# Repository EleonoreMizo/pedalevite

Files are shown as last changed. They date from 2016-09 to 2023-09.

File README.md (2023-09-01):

### We have moved!

**This page is now dead, there will not be any update anymore.**

**The new page is hosted here: https://gitlab.com/EleonoreMizo/pedalevite/**  
**Git repository address: https://gitlab.com/EleonoreMizo/pedalevite.git**

Please update your bookmarks! Repository is kept here for consistency with other projects but probably not indefinitely.

Pédale Vite — Multi-FX pedalboard
=================================

**Pédale Vite** is a DIY multi-FX pedalboard for guitar, bass or any other electric instrument.

It is based on a Raspberry Pi 4 and uses a custom audio board.

Pédale Vite

Key features:

- A large collection of effects within a single box: distortion, chorus, flanger, delay, reverb…
- Programs containing any free combination of the above effects
- 12 footswitches to activate the programs or other functionalities
- Fast and smooth transition between programs
- Up to 3 expression pedals to drive effects like wha, volume, LFOs…
- Infinite modulation possibilities
- Free effect routing
- Designed for stage and regular transport
- Silent and accurate tuner activated with a footswitch
- Standalone, no need for any external computer
- Building is easy and simple, can be reproduced and adapted by any person without specific skill
- Free software and hardware design
- And much more…

More information [here](http://ldesoras.free.fr/doc/articles/pedale-vite/pedale-vite-en.html).

The [/doc/](/doc/) folder contains everything you need to build the pedalboard.

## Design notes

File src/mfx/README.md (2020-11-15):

# Multi-FX

This is the main Pédale Vite source code.

- **`adrv`**: various audio drivers coded for Pédale Vite and its Windows emulator
- **`cmd`**: the layer commanding the audio thread.
- **`doc`**: the internal document structure, with serialization facilities.
- **`dsp`**: a library containing all the digital signal processing parts.
- **`hw`**: platform-specific and hardware-related code.
- **`pi`**: a set of audio effects (and more) used in the pedalboard, designed as plug-ins.
- **`piapi`**: the plug-in API for the audio effects.
- **`ui`**: user interface basics. Mostly deals with hardware (display, switches…)
- **`uitk`**: User interface toolkit. Higher level (G)UI management.

The code uses (or tries to use) a Model-View-Controller (MVC) programming scheme. The **`Model`** and **`View`** classes are the main culprits here. The controller part is split into the various `ui::pg` classes. **`PageSet`** aggregates various GUI parts. **`WorldAudio`** handles most of the real-time audio tasks, and is asynchroniously controlled by `cmd::Central`.

The whole setup and event loops are currently located in `main.cpp` from the topmost source code directory.

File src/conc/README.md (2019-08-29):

# Conc

A library for lock-free inter-thread communications. It enables easy inter-tread communication and avoids locking critical threads with mutexes or other synchronisation objects.

Here are the main utility classes, from a user’s point of view:

- **`LockFreeCell`**: A template class to wrap a message object and use it in `LockFreeStack`, `LockFreeQueue` or `CellPool`.
- **`LockFreeStack`**: Lock-free stack (LIFO), completely thread-safe.
- **`LockFreeQueue`**: Lock-free queue (FIFO). Concurrent N to M threads access. It’s your main communication building block.
- **`CellPool`**: thread-safe storage for unused or recycled `LockFreeCell` objects.
- **`ObjPool`**: Like `CellPool`, but for any kind of object, providing additional control over creation.

These classes rely on atomic primitives (using Compare-And-Swap instructions). The **`Atomic*`** classes provide basic data storage, with `AtomicPtrIntPair` being the cornerstone of the previous data structures. **`AtomicIntOp`** is a helper wrapping a user-functor into a CAS loop to execute synchronized operations. There are some functor examples in the **`Aio*`** classes.

Some of these classes are probably less useful since the introduction of the `<atomic>` header in C++11, anyway the **`Interlocked`** class probably offers stronger lock-free guaranties, especially for 128-bit CAS required by `AtomicPtrIntPair` on 64-bit systems.

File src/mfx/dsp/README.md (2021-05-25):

# Digital Signal Processing library

## General organization

- **`ana`**: analysis and feature extraction tools, except envelope followers
- **`ctrl`**: control signal generators and processors (LFOs, envelopes, parameter smoothing…)
- **`dly`**: delay tools
- **`dyn`**: tools to analyse dynamics (envelope followers)
- **`fir`**: Finite Impulse Response filters
- **`grn`**: Granular resynthesis
- **`iir`**: Infinite Impulse Response filters, s-plane design tools
- **`mix`**: Basic copy/mix/volume tools
- **`nz`**: Noise generators
- **`osc`**: Oscillators
- **`rspl`**: Resampling tools
- **`shape`**: Waveshaper, look-up table functions and distortions
- **`spat`**: Spatialisation, environment
- **`spec`**: Spectral tools
- **`va`**: Virtual analogue circuit modelisations
- **`wnd`**: Windows and similar shapes

## Dependencies

The **`dsp`** lib depends on several other libraries:
- **`ffft`**: Fast Fourier Transforms
- **`fstb`**: Miscellaneous support functions and generic tools
- **`hiir`**: Half-band IIR filters and Hilbert transforms
- **`lal`**: Minimalist linear algebra library

## Unsorted classes

- **`BandSplitAllPassPair`**: A template agregator to split a signal into two bands, using the sum and difference of a complentary pair of all-pass filters

- **`DenormStop`**: Functions to prevent denormal numbers to appear and significantly slow down the processing.

- **`FilterCascade`**: A template to cascade up to 4 filters from different classes. They rely on a `float process_sample(float)` function.
- **`FilterBypass`**: A do-nothing filter
- **`FilterCascadeIdEven`**: A template to cascade several filters from the same class
- **`FilterCascadeIdOdd`**: Same as `FilterCascadeIdEven`, but with one more filter from another class

- **`SplDataRetrievalInterface`**: An interface to abstract the random access to potentially large sample data

- **`StereoLevel`**: a simple 2×2 matrix to handle 2-channel levels

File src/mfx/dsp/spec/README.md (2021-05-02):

## spec — spectral tools

- **`FrameOverlap*`**: classes for analysis and resynthesis of overlapping frames
- **`StftHelper`**: a wrapper around an FFTReal class to perform a windowed STFT analysis. Block processing is automatically stopped when a new frame is ready.

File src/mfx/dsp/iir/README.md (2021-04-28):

## dsp::iir — Infinite Impulse Response filters, s-plane design tools

- **`AllPass1p`**: single-pole all-pass filter
- **`AllPass1pChain`**: Chain of several single-pole all-pass filters
- **`AllPass2p`**: 2-pole all-pass filter
- **`AllPassCascade`**: Cascade of any number of 1-pole and 2-pole all-pass filter sections
- **`Biquad`**: Direct Form 2 biquad (2 poles and 2 zeros) implementation
- **`Biquad4`**: Processes 4 biquads in parallel. The interface is compatible with `Biquad4Simd`.
- **`Biquad4Simd`**: Processes 4 biquads simultaneously. They can be arranged in parallel, series or both. Serial arrangements can be with or without latency compensation.
- **`Biquad4SimdMorph`**: Same as above, with automatic coefficient ramping when they are changed.
- **`BiquadPackSimd`**: Processes N channels with M biquads, for an almost optimal usage of the SIMD instructions. The (N, M) configuration can be smoothly changed, as well as each filter coefficient. This is the core engine of any complex equalizer.
- **`DcKiller1p`**: single-pole DC removal.
- **`DcKiller2p`**: 2-pole DC removal.
- **`DesignElliptic`**: Elliptic low-pass filter design in the s-plane.
- **`DesignEq2p`**: s-plane design functions for basic filters (butterworth, equalizer…), including Orfanidis’ corrected filters at Nyquist frequency.
- **`Downsampler?xSimd`**, **`Upsampler?xSimd`**: Convenience wrappers on the HIIR functions to achieve fast and high-quality 4x-up and downsampling.
- **`FilterComb`**: Sub-sample comb filter with custom interpolator.
- **`Lpf1p`**: Simple smoothing low-pass filter with one pole and no zero
- **`OnePole`**: Direct Form 2 implementation of 1st order filter.
- **`OnePole4Simd`**: Processes 4 single-pole filters simultaneously. They can be arranged in parallel, series or both. Serial arrangements can be with or without latency compensation.
- **`SplitAp5`**: 5th-order crossover filter using complementary pairs of all-pass filters.
- **`SplitMultiband`**: Filterbank with equal-magnitude reconstruction using complementary pairs of all-pass filters (any order, variable number of bands).
- **`SplitMultibandBustard`**: Filterbank with equal-magnitude reconstruction using elementary LPF/HPF pairs like L-R or Thiele.
- **`SplitMultibandLin*`**: Filterbank with perfect phase-linear reconstruction using IIR filters.
- **`SplitMultibandSimdGen`**: Code generator for SIMD versions of `SplitMultiband` with a predefined number of bands.
- **`SplitThiele8`**: Linkwitz-Riley or Thiele 8th-order crossover filter.
- **`SqueezerSimd`**: 4-pole Moog low-pass filter emulation with optional, custom dirt. `SqueezerOpDefect` (radical shaping and polarity inversion) can be used for this purpose.
- **`Svf2p`**: class to design SVFs from basic parameters or s-plane equations
- **`SvfCore`**: Like `Biquad`, but using Andrew Simper’s Linear Trapezoidal State Variable Filters (SVFs) instead of biquads. Filter and mixer coefficients can be computed with `Svf2p`. Generic mixer can be optimised with **`SvfMixer*`** classes if only a fixed output is required.
- **`SvfCore4Simd`**: Processes 4 SVFs simultaneously. Works like `Biquad4Simd`.
- **`TransS`**: Transforms of s-plane equations and poles/zeros. 
- **`TransSZBilin`**: Functions turning s-plane equations (analogue prototypes) into z-plane coefficients to use them in the filter implementations. Also handles frequency prewarping.
- **`TransSZMatched`**: Vicanek’s transforms of s- to z-plane equations, trying to fix the frequency response near the Nyquist frequency.

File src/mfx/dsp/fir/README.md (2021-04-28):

## dsp::fir — Finite Impulse Response filters

- **`ConvolverFft`**: Helper class to perform a filtering convolution using an overlap-save-FFT technique.
- **`DesignPhaseMin`**: Turns a linear-phase filter into a minimum-phase filter.
- **`MovingSum`**: Computes the running sum of the last N samples. Does not drift and works in O(1).
- **`RankSelL`**: Selects the Nth-rank element (the median for example) from a running N-element list. Optimised to select a single, fixed rank per processed sample. Works in O(N)
- **`RankSelA`**: Same as above, but optimised to select one or more ranks very quickly. However new sample insertion is slower than `RankSelL`.
- **`Remez`**: Implementation of the Parks-McClellan algorithm to design a FIR filter.
- **`SlidingMax`**: Computes the running max of the last N samples. Works in O(1).
- **`SlidingOp`**: Performs an operation between the last N samples. Works in O(ln(N)). The operation is a functor.

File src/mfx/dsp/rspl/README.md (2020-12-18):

## rspl — resampling tools

- **`InterpFtor`**: simple functors for polynomial interpolation
- **`InterpFirMakerHermite4`**: Utility class for building a 3rd-order cubic hermite interpolator as a 4-tap FIR
- **`InterpFirMakerLagrange4`**: Utility class for building a 3rd-order lagrange interpolator as a 4-tap FIR
- **`InterpFirPolyphase`**: Interpolator using a FIR polyphase filter. Phase data are implemented with `InterpPhase*`, taken as template parameter.
- **`InterpolatorInterface`**: generic interpolator interface. Provides sample-per-sample and block processing, resampling rate linear ramping and multi-channel operations.
- **`InterpolatorFir`**: implements the `InterpolatorInterface` using a FIR for interpolation. The FIR convolver class (`InterpFirPolyphase` for example) should be provided as a template parameter.
- **`InterpolatorHermite43`**: implements the `InterpolatorInterface` using a 3rd-order cubic hermite interpolator
- **`InterpolatorHermite43Simd`**: same as `InterpolatorHermite43` with SIMD processing
- **`InterpolatorLerp`**: implements the `InterpolatorInterface` using a linear interpolator
- **`InterpolatorLerpSimd`**: same as `InterpolatorLerp` with SIMD processing
- **`InterpolatorOrder0`**: implements the `InterpolatorInterface` using a 0-th order interpolator (nearest neighbour)
- **`InterpPhase*`**: 
- **`SnhTool`**: This class is intended to improve resampling speed in presence of oversampled processing (rendering at a high sampling rate then downsampling to the target sampling rate). The idea is to generate less samples than required (in other words, at a lower rate) and to let the object hold the values to fill the blanks. Sample & Hold is preferred here over zero-filling because it greatly simplifies rate changes.
- **`Voice`**: class build around `InterpolatorInterface` and `SplDataRetrievalInterface`, handling the playback of a sampler voice with variable rate. Optional forward, backward or bidirectional looping.

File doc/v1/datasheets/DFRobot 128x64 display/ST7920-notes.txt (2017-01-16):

https://www.embeddedrelated.com/showthread/lpc2000/36610-1.php
http://forum.hobbycomponents.com/viewtopic.php?f=75&t=1395

Connectique :
1	VSS	GND
2	VDD	5 V
3	V0		Contrast (pot GND-VDD)
4	RS	x	Chip Select
5	R/W	x	Data
6	E	x	Clock
7	DB0
8	DB1
9	DB2
10	DB3
11	DB4
12	DB5
13	DB6
14	DB7
15	PSB	GND	Parallel/Serial
16	(NC)
17	RST	x	Reset
18	VOUT
19	BLA	5 V	Back light alim
20	BLK	GND	Back light (switch GND/NC) -> 0 = on

Some versions of this LCD are shipped with the PSB (parallel/serial select) pin shorted to VDD by a 0 ohm resistor fitted to R9 on the back of the LCD. This fixes the LCD in parallel mode. If this resistor is fitted and you wish to use the LCD in serial mode you will either need to move the resistor to R10 or completely remove it and ground the PSD pin.

What persuaded me to make the leap was when I found the solder jumpers that connect Vss and K, Vdd and A and PSB to Vss (or Vdd for parallel operation). Made sense that the Led accepted 5v if the jumpers are there. 

Hi I'm new to this site and just would like to point out that on the 12864ZW model R9 is actually a 27Kohm resistor and not a 0ohm jumper. To put it into serial mode you don't have to remove it like on the 12864B model, you can just connect pin PSB to ground and it will work in serial mode

Latest version I got just from mail (12864ZW written on back) doesn't seem to require any modifications, only solder jumper on small selector "S / P". Three point selector/solder pad thing. Working well currently with Raspberry Pi 3. MOSI + SCK (R/W & E) to GPIO, CS (RS) tied directly to VDD on board and seems to work well.

R10 is 0ohm, removing it backlight stops working, at least thru BLA/BLK pins.

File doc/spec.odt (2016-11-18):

# Document structure

## Table of content

## Revision history

Version | Date | Modifications
1.0 | 2015.09.07 | Creation

## References

Number | Title | Origin/Reference | Version/Date

## Glossary

# Fonctionnalités

Disposition générale :

- Pédales permanentes. Exemples :
  - banque N
  - banque suivante
  - banque précédente
  - preset { N, … }
  - preset suivant
  - preset précédent
  - Toggle accordeur (effet global)
  - Toggle effet { X, … }
  - Event trigger
- Zone de banque

Banque :

- Pédales permanentes
  - preset { N, … }
  - preset suivant
  - preset précédent
  - Toggle accordeur
  - Toggle effet { X, … }
  - Event trigger
- Zone de preset

Preset :

- Assignation expression → effet X paramètre N
- Pédales contextuelles
  - Effet X on/off
  - Event trigger
  - Paramètre binaire effet X paramètre N

Preset { N, … } : Sélection d’un preset donné ou cycle parmi une courte liste assignée à la pédale.

Toggle effet { X, … } : on peut adresser l’effet X par un nom, qui est global à la disposition générale (ou à la banque courante ? À voir.) Au sein d’un preset, on peut assigner un nom à un effet particulier, ce qui permet de relier une pédale à n’importe quel effet de n’importe quel patch. Il peut y avoir plusieurs effets assignés à la pédale, et dans ce cas l’état bypass de chaque effet est inversé.

On peut aussi simplement donner un type caractérisant l’effet à activer/désactiver. La pédale commande alors le premier effet de ce type trouvé dans la chaîne.

Event trigger peut avoir différents usages : repérage du tempo, enregistrement, lecture ou arrêt d’une boucle, réinitialisation de la phase des LFOs, envoi de données sur le MIDI, etc.

# Architecture

## Threading

Trois threads :

- Thread des entrées
- Thread de commande, qui gère la structure du document et toutes ses modifications.
  - Répond aussi vite que possible aux sollicitations utilisateur
  - Prépare les données pour le thread audio
  - Instancie, reconfigure et détruit les plug-ins.
- Thread audio, qui pourra éventuellement être multipliés pour profiter du multi-core.

## Gestion du document

Le modèle est partagé entre le thread de commande et le thread audio.

Toutes les actions passent par le thread de commande. Cependant, certains contrôleurs peuvent être envoyés directement au thread audio qui, en fonction de la configuration courante, peut mettre à jour instantanément sa copie personnelle des paramètres (hors modulation). C’est le cas par exemple de la fréquence de coupure de la wha.

Les paramètres modifiés par le thread audio sont routés sur le thread de commande qui redispatche à tout le monde sauf l’audio et éventuellement enregistre les changements (en fonction du mode d’édition). On peut alors considérer que thread audio prend temporairement et localement le rôle de contrôleur au sens MVC, se substituant complètement à sa fonction de vue.

Les deux threads disposent donc chacun d’une copie approximativement synchronisée des valeurs de tous les paramètres.

## Audio

Tout ce qui concerne le traitement audio est précalculé par le thread de commande, dans la mesure du possible. En particulier : l’enchaînement des traitements, la répartition des buffers, les applications instantanées de presets, etc.

## Messages

Messages thread de commande → thread audio :

- Nouveau bloc de contrôle
- Paramètre de plug-in

Messages thread audio → thread de commande :

- Recyclage d’un bloc de contrôle
- Paramètre de plug-in

## Contrôleurs

### LFO

Paramètres :

- Période/fréquence
- Distorsion de phase (répartition temporelle du point du milieu)
- Position de la distorsion de phase
- Aléa cyclique
- Forme d’onde
  - Sinus
  - Triangle
  - Demi-sinus
  - Carré
  - Dents de scie
  - N-Phase
  - Varislope
  - Bruit brun
- Signe
- Polarité (unipolaire / bipolaire)
- Distorsion d’onde n & m (1–64) : 1-(1-x^n)^m en valeur absolue. On pourrait le réduire à un seul paramètre ? n :1→1→64→64→(1), m :1→64→1→64→(1) en calculant bien la progression de n et m. https://www.desmos.com/calculator/u7s3hvwhcj. Ou mieux : avec p dans [0 ; 1], x forme d’onde en entrée, f(s)=3*s^2-2*s^3, r0(p) = limit(|1.25-2*p|-0.25, 0, 0.5), r1(p) = limit (1.25-|0.75-2*p|, 0.5, 1), h(x, p) = x*(r1(p)-r0(p))+r0(p), w(x, p) = (f•f•f)(h(x, p)), y(x, p) = (w(x, p) - w(0, p)) / (w(1, p) - w(0, p)) en faisant attention au cas linéaire quand p = 0. https://www.desmos.com/calculator/cps103twdg
- Sample & hold
- Smoothing

Traitement :

Soit : Phase tri → modulation chaotique → distorsion de phase → forme d’onde → signe → polarité

Soit : Générateur tout-en-un

Puis : → écrêtement → distorsion d’onde → sample & hold → smoothing

#### Intégration

C’est délicat, car on aimerait pouvoir piloter les paramètres des LFO avec les pédales, voir avec les autres LFO.

Une solution serait de concevoir les LFO comme des plug-ins. Leur valeur de sortie serait stockée comme premier sample du premier canal audio. Le plug-in publierait une propriété spécifique indiquant qu’il émet du signal de contrôle et non du son.

L’avantage de cette solution, c’est qu’on peut fabriquer sur le même modèle d’autres types de source de modulation : enveloppes ADSR, step sequencers, voire sondes.

L’inconvénient, c’est qu’il faut intégrer cela de manière fluide et logique, d’une part dans le modèle de document, et d’autre part dans l’interface utilisateur.

Ne générant pas d’audio, les LFO n’ont pas vraiment leur place dans les slots classiques : avoir un module dry/wet/gain n’a aucun sens. On pourrait faire à la place une liste de « sources de modulation pures » reprenant un peu le concept de slot, mais sans le dry/wet/gain. Cependant il est gênant d’avoir une telle liste parallèle qui ressemble de très près aux slots.

Ou alors on pourrait les mettre dans les slots et simplement ignorer le dry/wet/gain quand on les traite. Il faudrait cependant ajouter au preset des informations de graphe pour être sûr de traiter chaque plug-in correctement, quitte à ne faire qu’une chaîne et des plug-ins isolés. C’est probablement la méthode la plus viable à long terme.

Les côtés traitement et présentation sont nettement plus complexes. Il faudrait revoir le concept de la chaîne de traitement.

Réflexions à poursuivre…

O.K., on reprend. On peut commencer par identifier les slots par un identifiant unique plutôt que par une position dans la liste. Cette liste deviendrait alors un simple container (typiquement, une map) et perdrait son indication implicite de routing. Le routing serait contenu, lui, dans un objet séparé. Il y a déjà du travail à faire pour tout adapter.

Bon, voilà qui est fait. Alors maintenant, on va pouvoir faire des plug-ins générant des signaux de contrôle. Il suffit de les identifier avec un flag ou quelque chose comme ça. Par contre, comment identifie-t-on de manière simple les instances de ces plug-ins de façon à les présenter comme contrôleurs ? On peut par exemple dresser une liste dynamique de ces plug-ins identifiés par le nom de leur classe + le numéro de leur instance (probablement issu d’un classement par slot_id) + éventuellement nº de sortie. Ou alors label + sortie. Ça change un peu la conception de la page qui permet de sélectionner une modulation, mais ça devrait le faire. Non en fait ça va être compliqué. On va faire par exemple N ports fixes, que les plug-ins vont s’assigner plus ou moins automatiquement. Par contre ne seront présentés à l’utilisateur que les ports occupés.

# Interface d’utilisation

## Principes

L’interface se présente sous forme de pages. On passe d’une page à l’autre par une manipulation de des boutons ou par un événement externe (modification du document).

Le graphisme et la mise en page sont adaptables à des tailles d’écran diverses (au minimum 84 × 48), mais elles seront optimisées pour l’écran actuellement choisi, en 128 × 64.

Les boutons qui permettent d’interagir directement avec l’interface sont Select, Esc, les 4 flèches et les deux rotenc (rotary encoders) à bouton poussoir. Les directions des rotenc sont associés habituellement aux flèches, mais il est possible de les décoreler. De même, les deux boutons poussoir sont habituellement équivalents à Select.

## Liste des pages

### Démarrage

#### Éléments affichés

- Titre
- Version
- Éventuellement, scan des plug-ins
- Éventuellement, message d’interruption.

#### Interactions

Si la pédale 1 est maintenue enfoncée pendant cette phase, la phase se poursuit au moins jusqu’au relâchement de la pédale. Si la pédale reste enfoncée plus de deux secondes, le programme se termine.

### Informations — programme courant

#### Éléments affichés

- Numéro du programme en très gros
- Nom du programme en gros
- Numéro et nom de la banque courante en petit (qui peut être différente de la banque à laquelle appartient le programme courant ?)
- Adresse IP en petit

#### Interactions

- Select : ➡ menu principal
- ←, →, rotenc 2 : ➡ contrôle des niveaux ? Ça ou autre chose ?
- ↑, ↓, rotenc 1 : changement de programme

### Contrôle des niveaux

#### Éléments affichés

- Volume master en dB
- Vu-mètre sortie + clipping
- Volume d’entrée en dB
- Vu-mètre entrée + clipping
- Vu-mètre Charge CPU

#### Interactions

- ↑, ↓, rotenc 1 : Défilement dans le menu
- ←, →, rotenc 2 : changements
- Select sur un volume : Remettre à zéro l’information de clipping
- Select sur l’icône de canaux : changer la stéréo de sortie
- Esc : ➡ Informations — programme courant

### Menu principal

#### Éléments affichés

- Édition programme courant
- Édition des banques
- Configuration du pédalier
- Contrôle du volume maître
- Redémarrage

#### Interactions

- ↑, ↓, rotenc 1 : Défilement dans le menu
- Select : ➡ Édition programme courant, ➡ édition des banques, ➡ configuration du pédalier, ➡ contrôle du volume maître, ➡ redémarrage
- Esc : ➡ Informations — programme courant

### Redémarrage

#### Éléments affichés

- Voulez-vous vraiment redémarrer ?
- Non
- Oui

#### Interactions

- ↑, ↓, rotenc 1 : Défilement dans le menu
- Select : ➡ menu principal ou redémarrage de la machine
- Esc : ➡ menu principal

### Édition programme courant

#### Éléments affichés

- Nom du programme
- Contrôleurs
- Sauver dans…
- Liste des plug-in slots dans l’ordre de traitement + 1 vide

Note : à partir de cet écran, et dans tous les écrans hiérarchiquement contenus, on passe en mode « édition ». Dans ce mode, les changements opérés sur le programme acif sont automatiquement sauvegardés dans la banque.

#### Interactions

- ↑, ↓, rotenc 1 : Défilement dans le menu
- Esc : ➡ menu principal
- Select sur Nom du programme ➡ édition texte. Titre : « Nom du programme ».
- Select sur Contrôleurs : ➡ contrôleurs du programme
- Select sur un slot vide : ➡ menu slot
- Select sur un slot plein : ➡ liste des paramètres
- ←, →, rotenc 2 sur un slot plein : changement du type de l’effet, avec un slot vide en début de liste.

### Édition texte

#### Éléments affichés

- Titre
- Chaîne éditée + curseur
- Zone de sélection défilante contenant différents caractères + Del + ← + → + OK + Cancel
- Curseur dans la zone défilante

Exemple de contenu de caractères (pas exhaustif, pas final) :

+---------------------+

|Titre |

|Texte |

|OK CANCEL SPC DEL ← →|

|abcdefgABCDEFGáàâãäÁÀÂÃÄþ

|hijklmnHIKLMNJéèêëýÉÈÊËšÞ

|opqrstuOPQRSTUíìîïÝÍÌÎÏŠø

|vwxyzçÇVWXYZñÑóòôõöÓÒÔÕÖØ

|0123456789œŒæÆúùûüßÚÙÛÜžŽ

+-_'"«»,.:;!¡?¿*+·#%&|

=@/\()[]{}<>×÷¯¢$€£¥

#### Interactions

À l’arrivée, le curseur de chaîne est positionné sur la fin de la chaîne.

- ↑, ↓, rotenc 1 et ←, →, rotenc 2 : faire défiler le curseur de sélection
- Select : ajouter le caractère pointé ou faire l’action indiquée
- Esc : comme Cancel.

Icônes :

- OK : la chaîne est validée telle quelle, retour à l’écran commanditaire
- Cancel : l’édition est annulée, retour à l’écran commanditaire
- Del : le caractère avant le curseur est effacé
- ←, → : déplacement du curseur de chaîne.

### Contrôleurs du programme

#### Éléments affichés

- Sources de modulation

#### Interactions

- Select sur Type de l’effet : ➡ Sources de modulation
- Esc : ➡ édition programme courant

### Sources de modulation

#### Éléments affichés

- Liste des plug-ins non-audio sources de modulation + 1 vide. L’ordre donné est arbitraire.

#### Interactions

- Le fonctionnement est le même que pour la liste Édition programme courant. Le menu Slot correspondant est un peu différent (pas d’Insertion, de Déplacer ni de Canaux). La liste des paramètres n’intègre pas ceux de mix.
- Esc : ➡ Contrôleurs du programme

### Menu slot

#### Éléments affichés

- Type de l’effet
- Label
- Insérer nouveau avant
- Copier
- Coller
- Supprimer (si applicable)
- Remise à zéro (si applicable)
- Déplacer
- Presets (si applicable)
- Nbr chn in/out (si applicable)

#### Interactions

- ←, →, rotenc 2 sur Type de l’effet : cycle les effets disponibles + slot vide.
- Select sur Type de l’effet : ➡ liste des effets
- Select sur Supprimer : ➡ confirmation simple (titre : « supprimer le slot ? »), éventuelle suppression du slot puis retour ➡ édition programme courant.
- Select sur Remise à zéro : ➡ confirmation simple (titre : « Remettre l’effet à zéro ? »), éventuelle remise à zéro du slot puis retour sur cette même page.
- Select sur Déplacer : ➡ déplacement de slot
- Select sur Presets : ➡ gestion des presets d’effet
- Select sur Nbr chn in/out : alterne le mono forcé avec stéréo (si applicable)
- Select sur Label :
- Esc : ➡ édition programme courant

### Liste des paramètres

#### Éléments affichés

- Setup / actions
- Bypass + valeur
- FX mix + valeur
- Volume + valeur
- Liste des paramètres de l’effet + valeur

Les valeurs sont ici affichées sans unité, par souci de compacité.

Les paramètres modulés seront signalés d’une manière restant à déterminer (soulignement pointillé ?)

#### Interactions

- ↑, ↓, rotenc 1 : Défilement dans le menu
- Select sur Setup / actions : ➡ menu slot
- Select sur un paramètre : ➡ Édition d’un paramètre
- Esc : ➡ édition programme courant
- ←, →, rotenc 2 : changement de la valeur du paramètre (coarse, 1/20)

### Édition d’un paramètre

#### Éléments affichés

- Nom du paramètre
- Valeur
- Unité (sur la même ligne que la valeur)
- Symboles donnant 4 pas de réglage, sur une ligne (ex : « 1 :10 :100 :1000 »)
- Contrôleurs, avec symbole indiquant qu’il y en a
- Si applicable : indication asservissement au tempo

#### Interactions

Le nom et la valeur ne sont pas navigables.

### Contrôleurs d’un paramètre

#### Éléments affichés

- Automation
- Modulations (liste)

Chaque élément de la liste est constitué soit de <none> (pour l’automation) ou <empty> (denière modulation), soit du nom/numéro de la source de modulation, sans autre précision à ce niveau.

#### Interactions

- ↑, ↓, rotenc 1 : Défilement dans le menu
- Select sur une entrée : ➡ Édition d’un contrôleur
- Esc : ➡ Édition d’un paramètre

### Édition d’un contrôleur

#### Éléments affichés

- Source/action : <empty>, pedal, expression, rotenc… (on allongera la liste plus tard) + numéro ou nom de la source
- Le pas, si applicable (rotenc + paramètre à valeurs continues)
- Valeur min
- Pas de réglage de la valeur min, si applicable
- valeur max
- Pas de réglage de la valeur max, si applicable
- Nom de la courbe, si applicable
- Conversion unipolaire → bipolaire

Idéalement, si <empty> est actif, les autres champs apparaissent vides.

#### Interactions

Les valeurs min et max ne sont pas navigables.

- ↑, ↓, rotenc 1 : Défilement dans le menu
- ←, →, rotenc 2 sur la source : changement de la source, éventuellement ajout ou destruction du contrôleur.
- ←, →, rotenc 2 sur le pas : changement de la valeur du pas. On utilisera une échelle log.
- ←, →, rotenc 2 sur le pas des valeurs min/max : changement de ladite valeur en fonction du pas sélectionné.
- ←, →, rotenc 2 sur la courbe : changement de la courbe
- Select sur la courbe :➡ Choix d’une courbe
- ←, →, rotenc 2 ou Select sur la conversion unipolaire → bipolaire : toggle.
- Esc : ➡ Contrôleurs d’un paramètre.

### configuration du pédalier

Cet écran pourra servir autant à la configuration de base du pédalier qu’à celles associées aux programmes et aux banques.

#### Éléments affichés

12 entrées indiquant pour chaque pédale :

- Numéro de la pédale
- Fonction attribuée

La fonction peut être excessivement complexe. On choisira donc de ne présenter que des cas d’utilisation courants. Les cas y échappant seront indiqués comme « complexes » et ne pourront pas être édités.

Cas d’utilisation envisagés :

- Rien.
- Simple action : PRESS, action unique. En dehors des possibilités suivantes, l’action sera indiquée comme complexe :
  - Prog +
  - Prog -
  - Prog N
  - Bank +
  - Bank -
  - Bank N
  - Tuner
  - Tempo
  - Toggle type d’effet ou étiquette
  - Set nom du paramètre, type d’effet ou étiquette
- Bouton momentané : PRESS + RELEASE, action paramètre identique avec une valeur pour chaque changement d’état.
  - PBSet nom du paramètre, type d’effet ou étiquette
- Toggle : PRESS avec 2 cycles, paramètre identique à chaque fois avec une valeur pour chaque cycle.
  - Tgl nom du paramètre, type d’effet ou étiquette

Rappel, structure à montrer :

pédale → type de déclencheur → étapes de cycle → liste d’actions

Note : seule le déclencheur « PRESS » peut avoir plusieurs étapes de cycle. Les autres n’utilisent que la première étape, si elle existe.

#### Interactions

- ↑, ↓, rotenc 1 : Défilement dans le menu
- ←, →, rotenc 2 sur une pédale : défilement du type d’action :
  - Toutes les simples actions (programme 0 à 15, banque 0 à 63), avec Toggle FX et Set positionnées sur une étiquette vide et le paramètre 0.
  - Bouton momentané avec une étiquette vide et le paramètre 0, valeurs normalisées 0 et 1
  - Idem pour le Toggle Param.
- Select sur Toggle FX : ➡ Sélection d’un effet
- Select sur Set : ➡ Sélection d’un paramètre d’effet, 1 valeur
- Select sur Bouton momentané : ➡ Sélection d’un paramètre d’effet, 2 valeurs
- Select sur Toggle Param : ➡ Sélection d’un paramètre d’effet, 2 valeurs
- Esc : ➡ Menu principal

### Sélection d’un paramètre d’effet, 1 valeur

#### Éléments affichés

- « Effect » ou « Label »
- Nom de l’effet ou du label
- Nom du paramètre
- Valeur
- Unité (sur la même ligne que la valeur)
- Symboles donnant 4 pas de réglage, sur une ligne (ex : « 1 :10 :100 :1000 »)

#### Interactions

### Sélection d’un paramètre d’effet, 2 valeurs

#### Éléments affichés

#### Interactions

### Édition des banques

#### Éléments affichés

- Import bank
- Export bank
- Liste des banques : coche + numéro + nom

La coche indique la banque courante.

#### Interactions

- Select sur Import : ➡ import de banque
- Select sur Export : ➡ export de banque
- Select sur une banque : sélection de la banque et ➡ édition d’une banque
- Esc : ➡ Menu principal

### x

#### Éléments affichés

#### Interactions

### x

#### Éléments affichés

#### Interactions

### x

#### Éléments affichés

#### Interactions

### x

#### Éléments affichés

#### Interactions

### x

#### Éléments affichés

#### Interactions

# Implémentation

## Interface utilisateur

### Principes

Chaque page est un container d’éléments, sous forme de simple liste.

La notion de curseur (matérialisé en vidéo inversée) est centrale. Celui-ci passe d’un élément à l’autre, en sautant les éléments qui n’acceptent pas de curseur.

Le curseur réagit à ↑, ↓ et rotenc 1. Par défaut, il passe à l’élément voisin et s’arrête aux extrémités de la liste. Il est toutefois possible d’indiquer pour chaque élément d’autres redirections, et même des redirections supplémentaires (←, →, rotenc 2). Ce mode permet de gérer des listes horizontales, des grilles plutôt que des listes ou des éléments disposés de manière irrégulière.

Un des éléments possible est une fenêtre, qui définit un espace virtuel possiblement plus grand que ce qui est affiché. Au sein d’une fenêtre, les éléments sont disposés comme dans le container principal. Il ne peut pas y avoir de fenêtre de second ordre. L’entrée et la sortie de la fenêtre se fait par ses éléments extrêmes. La sortie peut aussi se faire par le forçage à l’arrêt de certains éléments.

Pour simplifier, on fixe :

- que l’interaction et l’affichage sont regroupés sur la même arborescence
- que le fond est de couleur « 0 »
- que les éléments graphiques ne se superposent pas, ou s’écrasent les uns les autres
- que la position dans la liste détermine l’ordre d’affichage.

En terme de dessin, chaque élément est responsable de son affichage. Il sera mis à disposition un jeu de primitives.

### Raccord avec le modèle

Il existe une vue globale à jour disponible pour l’interface utilisateur. En plus ce cela, chaque élément implémente l’interface d’observer du modèle, ce qui permet de réagir de manière appropriée lors d’une notification (mise à jour d’une valeur, changement forcé d’écran…)

L’interface utilisateur aura également accès à l’interface contrôleur du modèle.

Pour l’instant tout tourne dans le même thread. En cas de latence significative ou de perte de réponse de l’audio causés par une gestion de l’UI un peu trop lourde, on mettra l’UI dans un thread séparé.

### Éléments d’interface

#### Caractéristiques communes

- Identifiant, donné par le code client lors de l’insertion. Il est unique au sein du container.
- Position en pixels, relativement à l’origine du container
- Flag indiquant la navigabilité (passage du curseur)
- Forçages : ↑, ↓, ←, →. Le forçage peut prendre plusieurs formes :
  - Saut à un élément spécifié
  - Arrêt
- Deux flags indiquant si les rotenc permettent la navigation (besoin de ça ? c’est implicite avec le gestionnaire d’événements)
- Une routine de redraw, où l’on indique si on doit afficher le curseur avec
- Un gestionnaire d’évènements :
  - Touches et rotenc non gérés par la navigation
  - Entrée et sortie du curseur

Les évènements de touches et de rotenc sont remontés hiérarchiquement s’ils ne sont pas explicitement interceptés.

#### Bitmap

Il s’agit d’une surface, fixe ou rendue dynamiquement. Pas de transparence à prévoir pour l’instant.

#### Simple texte

Défini par :

- Un texte
- Une police
- Des justifications horizontales et verticales
- Une taille maxi en pixels ?
- Des attributs :
  - Bold
  - Surligné
  - Souligné
  - Autre ?

#### Fenêtre

La fenêtre est un container spécifique.

# Idées

## Côté software

Intégrer un mode looper, qu’on active avec une pédale et qui dévoile plusieurs autres pédales : rec, stop/play, clear, revert… Il doit être possible de placer le looper à n’importe quel point de la chaîne (ça peut être un slot).

Intégrer un mode édition sans les mains, qui permette de naviguer uniquement avec les pédales et de régler les paramètres avec la pédale d'expression. Peut-être prévoir un affichage spécifique, présentant moins d’informations mais en plus gros.

Sortir le son 100 % dry sur le canal droit.

Mode tempo : les LED clignotent à un rythme déterminé. Utile ?

### Refonte de l’interface des plug-ins

Nouveaux besoins :

- Avoir un vrai système de plug-in, avec des bibliothèques dynamiques externes
- Faire en sorte que la description d’un plug-in soit indépendante des instances de celui-ci.
- Simplifier au mieux le développement d’un nouveau plug-in (éviter l’usine à gaz qui peut tout faire)

## Nouvelles versions de l’électronique

### Pédales d’expression supplémentaires

Ajouter des pédales (par exemple jusqu'à 3). Il peut être utile d’avoir plusieurs pédales d’expression pour contrôler alternativement plusieurs paramètres dans un même patch, sans avoir à passer par les interrupteurs du pédalier. Il faudra sajouter des résistances 100 kΩ ou 1 MΩ (valeur à tester) en pull-down sur les entrées de l’ADC, afin qu’aucune broche ne soit jamais complètement dans le vide et ne fasse antenne.

Si on pose Ra la valeur du potentiomètre, Rb la valeur du pull-down et p la position du potentiomètre entre 0 et 1, on obtient le potentiel suivant à la borne du curseur : V = Vref × PontDiviseur (Ra × p // Rb, Ra × (1 – p)) = Vref × (1 – Ra × (1 – p) / (Ra × Rb × p / (Ra × p + Rb) + Ra × (1 – p))). Avec les valeurs prévues, la différence de course est négligeable.

### LED plus brillantes

Avec amplification par transistor NPN BC547B. En faibles courants, VCESAT < 0,25 V et VBESAT = 0,7 V. β = 200.

LED choisies :

- Rouge, 180 mcd (20 mA, 1,95 V). RR = (VALIM – VCESAT – VLED) / IC = (3,3 – 0,25 – 1,95) / 0,020 = 55 Ω. On arrondit à la valeur standardisée de 56 Ω.
- Verte, 150 mcd (20 mA, 2,1 V). Pour compenser la luminosité on déplace le point de fonctionnement : (24 mA, 2,15 V). RG = (VALIM – VCESAT – VLED) / IC = (3,3 – 0,25 – 2,15) / 0,024 = 37,5 Ω. On arrondit à la valeur standardisée de 39 Ω.

Résistance de base : IBmin = IC / β = 0,024 / 200 = 0,12 mA. RBmax = (VHI - VBESAT) / IBmin = (3,3 – 0,7) / 0,00012 = 21666 Ω. Il faut un facteur 2 de sécurité, on choisit donc 10 kΩ.

Note importante : on utilise la broche d’alimentation 3,3 V. Or cette broche est comme le reste du GPIO, limitée à un total de 50 mA. On ne peut donc pas avoir plus de 2 LED allumées simultanément. Il reste alors au mieux 5 à 10 mA pour le reste du GPIO. Comme ces LED ne sont pas allumées à fond simultanément (PWM), on peut essayer de répartir les phases actives pour donner de l’air au circuit.

On pourrait aussi doubler les valeurs des résistances (120 et 82 Ω), ce qui devrait diviser par 2 le courant traversant les diodes. La luminosité résultante serait encore amplement suffisante.

### Codeurs incrémentaux

Quatre par exemple, voire plus. Deux broches d’entrée par codeur sont nécessaires, ce qui nécessitera un extenseur de ports.

### Plusieurs cartes

Diviser la carte principale en plusieurs morceaux. L’intérêt serait d’une part de simplifier les pistes et le soudage, et d’autre part de favoriser l’évolutivité et la modularité de l’ensemble. Par exemple :

- Carte de dispatching (connecteur Pi + connecteurs autres cartes) + ADC
- Carte LED
- Carte Pédales/boutons
- Carte codeurs incrémentaux

### Meilleur écran

Idéalement https://www.adafruit.com/products/2050 (8/16 broches) si dispo, mais on peut aussi utiliser https://www.adafruit.com/products/358 qu’on a déjà (8 voire 9 broches). On peut prévoir suffisamment de broches GPIO et un connecteur de départ adapté pour reporter la décision à n’importe quel moment.

Finalement : on a pris un 12864ZW basé sur un contrôleur Sitronix 7920. L’écran a une grande surface d’affichage, un très bon contraste et une résolution de 128 × 64. Le rétroéclairage consomme environ 60 mA en 5 V, ce qui est relativement important (0,3 W).

### Odroid C2

Vérifier la compatiblité des broches GPIO.

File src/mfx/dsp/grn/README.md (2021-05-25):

## dsp::grn — Granular resynthesis

- **`VelvetConv`**: Convolution between a single granule and velvet noise.

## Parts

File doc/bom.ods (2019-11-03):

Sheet: Feuille2
PÉDALE VITE — VERSION 2 — 2019-11-29
All resistors are 1% metal-film, ¼ W, ≤ 6.3 mm long unless specified
Green lines indicate identical components used in different places.
Prices are indicative and possibly outdated.
 |  |  |  |  | Quantity
Components | Description | Model | Main | Case | Mic | In | Out | Pwr | Dgt | Oth | Total | Units per set | Price per set (w/o tax) | Number of sets | Price | URL | Note
AUDIO BOARD
C1, C2 | 2200 µF, 50 V, pitch 7.5 mm, Ø18 mm | Panasonic EEU-FC1H222 |  |  |  |  |  | 2 |  |  | 2 | 1 | 3,1700 | 2 | 6,34 | http://fr.farnell.com/panasonic-electronic-components/eeufc1h222/condensateur-elec-alu-2200uf-50v/dp/9692487
C3, C4, C7, C8, C9, C11, C14, C15, C19, C20, C39, C42, C45, C59, C62, C65, C70, C74, C76, C78, C80, C82, C96, C97, C98 | 100 nF, 50 V, pitch 2.54 mm, X7R | Multicomp MC0805B104K500A2.54MM |  |  |  | 3 | 3 | 4 | 8 | 4 | 25 | 1 | 0,0894 | 25 | 2,24 | http://fr.farnell.com/multicomp/mc0805b104k500a2-54mm/condensateur-mlcc-x7r-100nf-50v/dp/2309020
C5, C6 | 1000 µF, 35 V, pitch 5 mm, Ø12.5 mm | Panasonic EEU-FC1V102 |  |  |  |  |  | 2 |  |  | 2 | 1 | 0,9160 | 2 | 1,83 | https://www.banzaimusic.com/Panasonic-FM-1000uF-35V.html http://fr.farnell.com/panasonic-electronic-components/eeufc1v102/condensateur-elec-alu-1000uf-35v/dp/9692312
C10, C73, C75, C81 | 100 µF, 25 V, pitch 2.5 mm, Ø6.3 mm | Panasonic EEU-FC1E101S |  |  |  |  |  |  | 3 | 1 | 4 | 1 | 0,1597 | 4 | 0,64 | https://www.banzaimusic.com/Panasonic-FM-100uF-25V.html http://fr.farnell.com/panasonic-electronic-components/eeufc1e101s/condensateur-elec-alu-100uf-25v/dp/1848439
C12, C13, C16, C17 | 100 µF, 35 V, pitch 3.5 mm, Ø8 mm | Panasonic EEU-FC1V101 |  |  |  |  |  |  |  | 4 | 4 | 1 | 0,1681 | 4 | 0,67 | https://www.banzaimusic.com/Panasonic-FM-100uF-50V.html http://fr.farnell.com/panasonic-electronic-components/eeufc1v101/condensateur-elec-alu-100uf-35v/dp/1848449
C18, C21 | 10 µF, 25 V → 50 V, pitch 2 mm, Ø5 mm | Panasonic EEU-FC1H100L |  |  |  |  |  |  | 2 |  | 2 | 1 | 0,1597 | 2 | 0,32 | https://www.banzaimusic.com/Panasonic-FC-10uF-25V.html http://fr.farnell.com/panasonic-electronic-components/eeufc1h100l/condensateur-elec-alu-10uf-50v/dp/1855182
C22 | 1 nF, 50 V → 100 V, pitch 2.54 mm, X7R | AVX SR151C102KAA |  |  |  |  |  |  |  | 1 | 1 | 1 | 0,1890 | 1 | 0,19 | http://fr.farnell.com/avx/sr151c102kaa/condensateur-mlcc-x7r-1nf-100v/dp/2332953
C30, C31, C40, C41, C50, C51, C60, C61 | 10 µF, 50 V, pitch 3.5 mm, Ø8 mm | Elna RFS-50V100MG3#5 |  |  | 2 | 2 |  |  |  |  | 8 | 1 | 0,4202 | 8 | 3,36 | https://www.banzaimusic.com/Elna-RFS-10uF-50V.html https://www.mouser.fr/ProductDetail/Elna/RFS-50V100MG35
C32, C33, C52, C53 | 1 nF polypropylen 2.5%, pitch 5 mm, 7.2 × 4.5 mm² | Wima FKP2-1000/100/5A |  |  | 2 |  |  |  |  |  | 4 | 1 | 0,1250 | 4 | 0,50 | https://www.musikding.de/Wima-FKP2-1nF-100V_1 https://www.mouser.fr/ProductDetail/WIMA/FKP2-1000-100-5A
C34, C54 | 470 µF, 25 V, pitch 5 mm, Ø10 mm | Panasonic EEU-FC1E471 0,843 |  |  | 1 |  |  |  |  |  | 2 | 1 | 0,3025 | 2 | 0,61 | https://www.banzaimusic.com/Panasonic-FC-470uF-25V.html
C35, C36, C55, C56 | 1 µF, 35 V tantalum, pitch 2.54 mm | ? |  |  | 2 |  |  |  |  |  | 4 | 1 | 0,1765 | 4 | 0,71 | https://www.banzaimusic.com/Tantalum-1uF-35V.html http://www.gotronic.fr/art-condensateur-tantale-1-0uf-35v-3323.htm
C37, C38, C57, C58 | 10 µF, 35 V, pitch 2 mm, Ø5 mm | Elna RFS-35V100ME3#5 |  |  | 2 |  |  |  |  |  | 4 | 1 | 0,1597 | 4 | 0,64 | https://www.banzaimusic.com/Elna-RFS-10uF-35V.html https://www.mouser.fr/ProductDetail/Elna/RFS-35V100ME35
C43, C44, C46, C47, C63, C64, C66, C67 | 1 nF, 50 V, pitch 5 mm, C0G | TDK FA28C0G1H102JNU00 Vishay K102J15C0GF53H5H |  |  |  | 4 |  |  |  |  | 8 | 1 | 0,2430 | 8 | 1,94 | https://www.mouser.fr/ProductDetail/TDK/FA28C0G1H102JNU00 http://fr.farnell.com/vishay/k102j15c0gf53h5h/condensateur-mlcc-c0g-1000pf-50v/dp/2544855
C48, C68 | 3.3 nF, 50 V, pitch 5 mm, C0G | TDK FA28C0G1H332JNU00 Kemet C322C332J1G5TA |  |  |  | 1 |  |  |  |  | 2 | 1 | 0,2880 | 2 | 0,58 | https://www.mouser.fr/ProductDetail/TDK/FA28C0G1H332JNU00 http://fr.farnell.com/kemet/c322c332j1g5ta/condensateur-mlcc-c0g-np0-3-3nf/dp/1457675
C71, C72 | 4 pF → 3.9 pF, 50 V, pitch 2.54 mm, ceramic | ? |  |  |  |  |  |  | 2 |  | 2 | 1 | 0,0800 | 2 | 0,16 | http://www.gotronic.fr/art-condensateur-ceramique-3-9-pf-8674.htm http://www.gotronic.fr/art-condensateur-ceramique-18-pf-8682.htm
C77, C79 | 1 µF, 25 V → 50 V, pitch 2 mm, Ø5 mm | Elna RFS-50V010ME3#5 |  |  |  |  |  |  | 2 |  | 2 | 1 | 0,1597 | 2 | 0,32 | https://www.banzaimusic.com/Elna-RFS-1uF-50V-14.html https://www.mouser.fr/ProductDetail/Elna/RFS-50V010ME35 https://www.mouser.fr/ProductDetail/Elna/RFS-50V010MF35 https://www.mouser.fr/ProductDetail/KEMET/ESC105M050AC3AA | The F3#5 model is a bit too thick. Kemet ones are OK and cheaper
C83, C84 | 100 pF, 50 V, pitch 2.54 mm, C0G | Multicomp MC0805N101J500A2.54MM |  |  |  | 1 |  |  |  |  | 2 | 1 | 0,0853 | 2 | 0,17 | http://fr.farnell.com/multicomp/mc0805n101j500a2-54mm/condensateur-mlcc-c0g-np0-100pf/dp/2309023
C90, C91, C100, C101 | 100 µF, 25 V, pitch 5 mm, Ø10 mm | Elna RFS-25V101MH4#5 |  |  |  |  | 4 |  |  |  | 4 | 1 | 0,4538 | 4 | 1,82 | https://www.banzaimusic.com/Elna-RFS-100uF-25V.html https://www.musikding.de/ELNA-RFS-100uF-25V_1 https://www.mouser.fr/ProductDetail/Elna/RFS-25V101MH45
C92, C102 | 2.2 nF, 50 V, pitch 5 mm, C0G | TDK FA28C0G1H222JNU00 Kemet C322C222J1G5TA |  |  |  |  | 2 |  |  |  | 2 | 1 | 0,2790 | 2 | 0,56 | https://www.mouser.fr/ProductDetail/TDK/FA28C0G1H222JNU00 http://fr.farnell.com/kemet/c322c222j1g5ta/condensateur-mlcc-c0g-np0-2-2nf/dp/1457673
C93, C103 | 6.8 nF, 50 V, pitch 5 mm, C0G | TDK FK28C0G1H682J Kemet C322C682JBG5TA |  |  |  |  | 2 |  |  |  | 2 | 1 | 0,2790 | 2 | 0,56 | https://www.mouser.fr/ProductDetail/?qs=vNwBHymccZ%2FG5OaLWVcvXw%3D%3D http://fr.farnell.com/kemet/c322c682jbg5ta/condensateur-mlcc-c0g-np0-6800pf/dp/2500246
C94, C104 | 470 pF 50 V, pitch 5 mm, C0G | TDK FA28C0G1H471JNU00 Vishay K471J15C0GF53H5H |  |  |  |  | 2 |  |  |  | 2 | 1 | 0,2160 | 2 | 0,43 | https://www.mouser.fr/ProductDetail/TDK/FA28C0G1H471JNU00 http://fr.farnell.com/vishay/k471j15c0gf53h5h/condensateur-mlcc-c0g-470pf-50v/dp/2544854
C95, C105 | 1.5 nF 50 V, pitch 5 mm, C0G | TDK FG28C0G1H152JNT00 Kemet C322C152J2G5TA |  |  |  |  | 2 |  |  |  | 2 | 1 | 0,1980 | 2 | 0,40 | https://www.mouser.fr/ProductDetail/TDK/FG28C0G1H152JNT00 http://fr.farnell.com/kemet/c322c152j2g5ta/condensateur-mlcc-c0g-1500pf-200v/dp/2678633
D1–D8 | Blocking diode 100 V reverse voltage (1N4002 or above) | 1N4007 |  |  |  |  |  | 6 | 1 | 1 | 8 | 1 | 0,0700 | 8 | 0,56 | http://www.gotronic.fr/art-1n4007-107.htm
D9 | TL431 voltage reference (any model) | TL431ACLP |  |  |  |  |  | 1 |  |  | 1 | 1 | 0,3890 | 1 | 0,39 | http://fr.farnell.com/texas-instruments/tl431aclp/ref-de-tension-shunt-2-495v-36v/dp/9593543
D10–D13, D18–D21, D30–D33, D38–D41 | IC protection diode 1N4448, low fwd voltage, 100 V rev | 1N4448 |  |  | 4 | 4 |  |  |  |  | 16 | 1 | 0,0700 | 16 | 1,12 | http://www.gotronic.fr/art-1n4448-1633.htm
D14–D17, D34–D37 | IC protection Schottky diode 1N5817, low fwd voltage | STMicroelectronics 1N5817 |  |  |  | 4 |  |  |  |  | 8 | 1 | 0,0840 | 8 | 0,67 | http://www.banzaimusic.com/1N5817.html https://www.musikding.de/1N5817_1 http://fr.farnell.com/stmicroelectronics/1n5817/diode-schottky-1a-20v/dp/9801197
IC1 | +15 V regulator 1,5 A TO220, high PSRR | ON MC7815ACTG |  |  |  |  |  | 1 |  |  | 1 | 1 | 0,4500 | 1 | 0,45 | https://www.mouser.fr/ProductDetail/ON-Semiconductor/MC7815ACTG
IC2 | -15 V regulator 1,5 A TO220, high PSRR | TI LM7915CT/NOPB |  |  |  |  |  | 1 |  |  | 1 | 1 | 1,4000 | 1 | 1,40 | https://www.mouser.fr/ProductDetail/Texas-Instruments/LM7915CT-NOPB
IC3 | +5 V regulator 1,5 A TO220, high PSRR | TI LM7805CT/NOPB |  |  |  |  |  |  |  | 1 | 1 | 1 | 1,3800 | 1 | 1,38 | https://www.mouser.fr/ProductDetail/Texas-Instruments/LM7805CT-NOPB
IC1, IC2, IC3 | Heatsink for TO220, 20 × 10 mm², 24 °C/W | Aavid Thermalloy 507302B00000G |  |  |  |  |  | 2 |  | 1 | 3 | 10 | 1,5400 | 1 | 1,54 | http://fr.farnell.com/aavid-thermalloy/507302b00000g/dissipateur-to-220/dp/1611415
IC1, IC2, IC3 | M3 screw, 6 mm |  |  |  |  |  |  | 2 |  | 1 | 3 | 10 | 0,2500 | 1 | 0,25 | http://www.gotronic.fr/art-10-vis-acier-m3-6mm-6506.htm
IC1, IC2, IC3 | M3 nut |  |  |  |  |  |  | 2 |  | 1 | 3 | 10 | 0,1700 | 1 | 0,17 | http://www.gotronic.fr/art-10-ecrous-acier-m3-6510.htm
IC1, IC2, IC3 | M3 washer |  |  |  |  |  |  | 2 |  | 1 | 3 | 10 | 0,1300 | 1 | 0,13 | http://www.gotronic.fr/art-10-rondelles-acier-m3-6511.htm
IC4 | +3.3 V regulator 300mA TO-92 | STMicroelectronics L4931CZ33 |  |  |  |  |  |  | 1 |  | 1 | 1 | 1,1100 | 1 | 1,11 | http://fr.farnell.com/stmicroelectronics/l4931cz33-ap/ldo-fixe-3-3v-0-25a-to-92-3/dp/2554986
IC4, D9, Q1, Q2, Q3 | Single row round-pin socket for transistors, regulator and voltage reference | STB32 |  |  |  |  |  |  | 15 |  | 15 | 32 | 0,9500 | 1 | 0,95 | http://www.gotronic.fr/art-barrette-secable-stb32-4622.htm
IC5, IC9 | Differential instrumentation amplifier | TI INA103KP |  |  | 1 |  |  |  |  |  | 2 | 1 | 9,5700 | 2 | 19,14 | https://www.mouser.fr/ProductDetail/Texas-Instruments/INA103KP
IC5, IC9 | IC socket, 16 pins, 7.62mm | SUP16T |  |  | 1 |  |  |  |  |  | 2 | 1 | 0,3667 | 2 | 0,73 | http://www.gotronic.fr/art-support-tulipe-sup16t-4606.htm
IC6, IC7, IC8, IC10, IC11, IC12, IC15, IC16, IC17 | Operational amplifier | TI NE5532AP |  |  |  | 3 | 3 |  |  |  | 9 | 1 | 0,9810 | 9 | 8,83 | https://www.mouser.fr/ProductDetail/Texas-Instruments/NE5532AP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 https://fr.farnell.com/texas-instruments/ne5532ap/ampli-op-double-faible-bruit-5532/dp/1106091
IC6, IC7, IC8, IC10, IC11, IC12, IC15, IC16, IC17 | IC support 8 pins, pitch 7.62 mm, hollow body | SUP08T |  |  |  | 3 | 3 |  |  |  | 9 | 1 | 0,1800 | 9 | 1,62 | http://www.gotronic.fr/art-support-tulipe-sup08t-4604.htm
IC13 | Clock | IDT MK2703BSLF |  |  |  |  |  |  | 1 |  | 1 | 1 | 4,0500 | 1 | 4,05 | https://www.mouser.fr/ProductDetail/IDT/MK2703BSLF?qs=sGAEpiMZZMtXsj1ZQc4vOY7HyZZcqbXCXYQWKNwuzqM%3D
IC14 | Audio codec | Cirrus Logic CS4272 |  |  |  |  |  |  | 1 |  | 1 | 1 | 8,1900 | 1 | 8,19 | https://www.mouser.fr/ProductDetail/Cirrus-Logic/CS4272-CZZ?qs=sGAEpiMZZMtq3QB8qGen7RvmYt8Ka6ZEaAgtBiwxodk%3D
J7, J9 | Screw terminal 1 × 2, 250 V, pitch 5 mm | ? |  |  |  |  |  | 2 |  |  | 2 | 1 | 0,2500 | 2 | 0,50 | http://www.gotronic.fr/art-bornier-sc02-4535.htm
JP1, JP2, P3 | 1-row breakable Dupont pin header, pitch 2.54 mm | 1×36 pins |  |  |  |  |  |  | 13 | 2 | 15 | 36 | 0,5000 | 1 | 0,50 | http://www.gotronic.fr/art-connecteur-he14-mh100-4457.htm
JP1, JP2 | Female jumpers for Dupont pin headers | ? |  |  |  |  |  |  | 1 | 1 | 2 | 20 | 0,6700 | 1 | 0,67 | http://www.gotronic.fr/art-cavaliers-femelles-cf17-4464.htm
L1, L2 | 22 µH, pitch 5 mm, Ø7.5 mm | CH6080 |  |  |  |  |  | 2 |  |  | 2 | 1 | 0,7100 | 2 | 1,42 | http://www.gotronic.fr/art-self-radiale-22uh-8576.htm
L3–L6 | 1.2 µH, 7.11 × 2.79 mm | Bourns 78F1R2K-RC |  |  | 2 |  |  |  |  |  | 4 | 1 | 0,1980 | 4 | 0,79 | https://www.mouser.fr/ProductDetail/Bourns/78F1R2K-RC
L7 | Ferrite bead, pitch 2–4 mm, Ø6 mm, 1 kΩ at 100 MHz | Laird Technologies 28C0236-0EW-10 |  |  |  |  |  |  | 1 |  | 1 | 5 | 1,8150 | 1 | 1,82 | http://fr.farnell.com/laird-technologies/28c0236-0ew-10/filtre-6x10-50mm-100mhz-998r/dp/2292298 http://fr.farnell.com/murata/bl02rn1r2m2b/inductance-radial/dp/9526838 | The second one is probably less efficient but is cheaper and available as single units.
P1, P2 | 3-pin connector, pitch 2.54 mm, male embase (type Molex KK) | MPE-Garry 428-1-003-0-T-KS0 |  |  |  |  |  | 1 |  | 1 | 2 | 1 | 0,1000 | 2 | 0,20 | http://www.gotronic.fr/art-connecteur-s003-124.htm
P1, P2 | 3-pin connector, pitch 2.54 mm, female | MPE-Garry 431-1-003-X-KS0 |  |  |  |  |  | 1 |  | 1 | 2 | 1 | 0,0500 | 2 | 0,10 | http://www.gotronic.fr/art-boitier-nsk254-3b-170.htm
P1, P2 | Female contact for the 3-pin connectors | MPE-Garry 611-1-TX-X |  |  |  |  |  | 3 |  | 3 | 6 | 10 | 0,1700 | 1 | 0,17 | http://www.gotronic.fr/art-10-contacts-nsk254-0-171.htm
P4–P20 | 2-row breakable Dupont pin header, pitch 2.54 mm | 2×36 pins |  |  |  | 20 | 10 | 8 |  |  | 58 | 72 | 0,7500 | 1 | 0,75 | http://www.gotronic.fr/art-connecteur-he14-mh200-4459.htm
Q1 | NPN, TO 92, 1 A | BC639 |  |  |  |  |  |  |  | 1 | 1 | 1 | 0,1700 | 1 | 0,17 | http://www.gotronic.fr/art-transistor-bc639-1360.htm http://fr.farnell.com/fairchild-semiconductor/bc63916-d27z/transistor-bipol-npn-80v-to-226aa/dp/2453811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
Q2 | PNP, TO 92, 1 A | BC640 |  |  |  |  |  |  |  | 1 | 1 | 1 | 0,1700 | 1 | 0,17 | http://www.gotronic.fr/art-transistor-bc640-1361.htm http://fr.farnell.com/fairchild-semiconductor/bc640ta/transistor-bipol-pnp-80v-to-92/dp/2453812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
Q3 | NPN, TO 92 | BC547B |  |  |  |  |  |  | 1 |  | 1 | 1 | 0,1300 | 1 | 0,13 | http://www.gotronic.fr/art-transistor-bc547b-1336.htm | BC639 is fine too.
R7 | 10 Ω |  |  |  |  |  |  | 1 |  |  | 1 | 1 | 0,0504 | 1 | 0,05 | https://www.musikding.de/10R-metal-film-1 http://fr.farnell.com/te-connectivity/lr0204f10r/resistance-metal-10r-0-25w-1/dp/2329856
R12, R13, R42, R43 | 15 Ω |  |  |  | 2 |  |  |  |  |  | 4 | 1 | 0,0504 | 4 | 0,20 | https://www.musikding.de/15R-metal-film-1 http://fr.farnell.com/te-connectivity/lr0204f15r/resistance-metal-15r-0-25w-1/dp/2329874
R25, R55 | 20 Ω |  |  |  |  | 1 |  |  |  |  | 2 | 1 | 0,0504 | 2 | 0,10 | https://www.musikding.de/20R-metal-film-1 http://fr.farnell.com/te-connectivity/lr0204f20r/resistance-metal-20r-0-25w-1/dp/2329898
R5, R6, R72 | 33 Ω |  |  |  |  |  |  |  | 1 | 2 | 3 | 1 | 0,0504 | 3 | 0,15 | https://www.musikding.de/33R-metal-film-1 http://fr.farnell.com/te-connectivity/lr0204f33r/resistance-metal-33r-0-25w-1/dp/2329924
R14, R15, R44, R45 | 50 Ω (→ 51 Ω if unavailable or too expensive) |  |  |  | 2 |  |  |  |  |  | 4 | 1 | 0,0504 | 4 | 0,20 | https://www.musikding.de/51R-metal-film-1 http://fr.farnell.com/te-connectivity/lr0204f51r/resistance-metal-51r-0-25w-1/dp/2329951
R19, R20, R22, R24, R36, R37, R49, R50, R52, R54, R66, R67, R90, R91, R92, R110, R111, R112 | 100 Ω |  |  |  | 2 | 4 | 6 |  |  |  | 18 | 1 | 0,0336 | 18 | 0,61 | https://www.musikding.de/100R-metal-film-1 http://fr.farnell.com/te-connectivity/lr0204f100r/resistance-metal-100r-0-25w-1/dp/2329854
R87, R107 | 220 Ω |  |  |  |  |  | 2 |  |  |  | 2 | 1 | 0,0504 | 2 | 0,10 | https://www.musikding.de/220R-metal-film-1 http://fr.farnell.com/te-connectivity/lr0204f220r/resistance-metal-220r-0-25w-1/dp/2329900
R83, R103 | 430 Ω |  |  |  |  |  | 2 |  |  |  | 2 | 1 | 0,0504 | 2 | 0,10 | https://www.musikding.de/430R-metal-film-1 http://fr.farnell.com/te-connectivity/lr0204f430r/resistance-metal-430r-0-25w-1/dp/2329938
R81, R101 | 510 Ω |  |  |  |  |  | 2 |  |  |  | 2 | 1 | 0,0504 | 2 | 0,10 | https://www.musikding.de/510R-metal-film-1 http://fr.farnell.com/te-connectivity/lr0204f510r/resistance-metal-510r-0-25w-1/dp/2329949
R16, R46 | 604 Ω (→ 620 Ω if unavailable or too expensive) |  |  |  | 1 |  |  |  |  |  | 2 | 1 | 0,0672 | 2 | 0,13 | https://www.banzaimusic.com/604-Ohm-MF-0-25W.html https://www.mouser.fr/ProductDetail/Yageo/MFR-25FBF52-604R
R85, R105 | 620 Ω |  |  |  |  |  | 2 |  |  |  | 2 | 1 | 0,0504 | 2 | 0,10 | https://www.musikding.de/620R-metal-film-1 http://fr.farnell.com/te-connectivity/lr0204f620r/resistance-metal-620r-0-25w-1/dp/2329960
R88, R108 | 820 Ω |  |  |  |  |  | 2 |  |  |  | 2 | 1 | 0,0504 | 2 | 0,10 | https://www.musikding.de/820R-metal-film-1 http://fr.farnell.com/multicomp/mf25-820r/resistance-0-25w-1-820r/dp/9342265
R3, R4, R28, R29, R58, R59, R86, R89, R106, R109 | 1 kΩ |  |  |  |  | 2 | 4 |  |  | 2 | 10 | 1 | 0,0504 | 10 | 0,50 | https://www.musikding.de/10k-metal-film-1 http://fr.farnell.com/multicomp/mf25-1k/resistance-1k-0-25w-1/dp/9341102
R38, R39, R68, R69 | 1.1 kΩ |  |  |  |  | 2 |  |  |  |  | 4 | 1 | 0,0504 | 4 | 0,20 | https://www.musikding.de/1k1-metal-film-1 http://fr.farnell.com/te-connectivity/lr0204f1k1/resistance-metal-1k1-0-25w-1/dp/2329886
R34, R35, R64, R65 | 1.2 kΩ |  |  |  |  | 2 |  |  |  |  | 4 | 1 | 0,0504 | 4 | 0,20 | https://www.musikding.de/1k2-metal-film-1 http://fr.farnell.com/multicomp/mf25-1k2/resistance-1-2k-0-25w-1/dp/9341226
R82, R102 | 1.3 kΩ |  |  |  |  |  | 2 |  |  |  | 2 | 1 | 0,0672 | 2 | 0,13 | https://www.banzaimusic.com/1-3k-MF-0-25W.html http://fr.farnell.com/te-connectivity/lr0204f1k3/resistance-metal-1k3-0-25w-1/dp/2329889
R80, R100 | 1.54 kΩ (→ 1.6 kΩ if unavailable or too expensive) |  |  |  |  |  | 2 |  |  |  | 2 | 1 | 0,0940 | 2 | 0,19 | https://www.mouser.fr/ProductDetail/Yageo/MFR-25FBF52-1K54 http://fr.farnell.com/te-connectivity/lr0204f1k6/resistance-metal-1k6-0-25w-1/dp/2329892
R84, R104 | 2 kΩ |  |  |  |  |  | 2 |  |  |  | 2 | 1 | 0,0504 | 2 | 0,10 | https://www.musikding.de/2k-metal-film-1 http://fr.farnell.com/te-connectivity/lr0204f2k0/resistance-metal-2k0-0-25w-1/dp/2329911
R10, R11, R31, R33, R40, R41, R61, R63 | 2.2 kΩ |  |  |  | 2 | 2 |  |  |  |  | 8 | 1 | 0,0504 | 8 | 0,40 | https://www.musikding.de/2k2-metal-film-1 http://fr.farnell.com/multicomp/mf25-2k2/resistance-2-2k-0-25w-1/dp/9341536
R30, R32, R60, R62 | 2.4 kΩ |  |  |  |  | 2 |  |  |  |  | 4 | 1 | 0,0504 | 4 | 0,20 | https://www.musikding.de/2k4-metal-film-1 http://fr.farnell.com/te-connectivity/lr0204f2k4/resistance-metal-2k4-0-25w-1/dp/2329913
R9, R21, R23, R26, R27, R51, R53, R56, R57, R70 | 10 kΩ |  |  |  |  | 4 |  | 1 | 1 |  | 10 | 1 | 0,0504 | 10 | 0,50 | https://www.musikding.de/10k-metal-film-1_1 http://fr.farnell.com/te-connectivity/lr0204f10k/resistance-metal-10k-0-25w-1/dp/2329855
R8 | 11 kΩ |  |  |  |  |  |  | 1 |  |  | 1 | 1 | 0,0504 | 1 | 0,05 | https://www.musikding.de/11k-metal-film-1 http://fr.farnell.com/te-connectivity/lr0204f11k/resistance-metal-11k-0-25w-1/dp/2329859
R17, R18, R47, R48, R71 | 100 kΩ |  |  |  |  | 2 |  |  | 1 |  | 5 | 1 | 0,0504 | 5 | 0,25 | https://www.musikding.de/100k-metal-film-1 http://fr.farnell.com/te-connectivity/lr0204f100k/resistance-metal-100k-0-25w-1/dp/2329853
Y1 | 27 MHz crystal, 18 pF, pitch 5 mm | TXC 9B-27.000MEEJ-B |  |  |  |  |  |  | 1 |  | 1 | 1 | 0,5360 | 1 | 0,54 | http://fr.farnell.com/txc/9b-27-000meej-b/xtal-27-000mhz-18pf-hc-49s/dp/1842241
MAIN BOARD
C1, C2 | 1 µF, ceramic X7R, pitch 2.5 mm, must fit in a 2.5 × 5 mm² space, 4 mm high max |  | 2 |  |  |  |  |  |  |  | 2 | 1 | 1,020 | 2 | 2,04 | https://fr.farnell.com/kemet/c315c105k3r5ta/condensateur-1-f-25v-10-x7r/dp/2819619
C3–C5, C7–C42 | 100 nF, ceramic Y5V+, pitch 2.5 mm, must fit in a 2.5 × 5 mm² space, 4 mm high max |  | 40 |  |  |  |  |  |  |  | 40 | 1 | 0,093 | 40 | 3,73 | https://fr.farnell.com/multicomp/mc0805y104m500a2-54mm/condensateur-0-1-f-50v-20-y5v/dp/2112751 https://fr.farnell.com/murata/rcer71h104k0dbh03a/condensateur-0-1uf-50v-mlcc-radial/dp/2990748 https://www.mouser.fr/ProductDetail/Vishay/K104K15X7RF53L2 https://www.musikding.de/Ceramic-Disc-01-uF
P1 | HE10 male socket connector, 2×20 pins |  | 1 |  |  |  |  |  |  |  | 1 | 1 | 0,792 | 1 | 0,79 | https://www.gotronic.fr/art-connecteur-he10bd40-20084.htm https://fr.farnell.com/3m/30340-6002hb/connect-header-40-voies-2-rangs/dp/2668422
P2, P3, P16 | 2-row breakable Dupont pin header, pitch 2.54 mm | 2×36 pins | 15 |  |  |  |  |  |  |  | 15 | 36 | 0,750 | 1 | 0,75 | https://www.gotronic.fr/art-connecteur-he14-mh200-4459.htm
P4 | 1-row breakable Dupont pin header, pitch 2.54 mm | 1×36 pins | 10 |  |  |  |  |  |  |  | 10 | 36 | 0,500 | 1 | 0,50 | https://www.gotronic.fr/art-connecteur-he14-mh100-4457.htm
P5, P9, P10 | Connector NSK254 1×4, base | MPE-Garry 428-1-004-0-T-KS0 | 3 |  |  |  |  |  |  |  | 3 | 1 | 0,100 | 3 | 0,30 | https://www.gotronic.fr/art-connecteur-nsk254-4-15396.htm
P6, P7, P8, P11, P12, P13, P14, P15 | Connector NSK254 1×3, base | MPE-Garry 428-1-003-0-T-KS0 | 8 |  |  |  |  |  |  |  | 8 | 1 | 0,083 | 8 | 0,67 | https://www.gotronic.fr/art-connecteur-nsk254-3-15395.htm
Q1, Q2, Q3 | Transistor NPN CBE hFE ≥ 200 | BC547B | 3 |  |  |  |  |  |  |  | 3 | 1 | 0,125 | 3 | 0,38 | https://www.gotronic.fr/art-transistor-bc547b-1336.htm https://fr.farnell.com/on-semiconductor/bc547bta/transistor-npn-45v-0-1a-0-5w-to/dp/2985329 | BC639 is fine too.
R1 | 1.5 kΩ, 5 %, ¼ W |  | 1 |  |  |  |  |  |  |  | 1 | 10 | 0,167 | 1 | 0,17 | https://www.gotronic.fr/art-10-resistances-1-4w-1-5k-8486-2576.htm https://fr.farnell.com/multicomp/mf25-1k5/resistance-1-5k-0-25w-1/dp/9341323
R2, R3, R4 | 1 MΩ, 5 %, ¼ W |  | 3 |  |  |  |  |  |  |  | 3 | 10 | 0,167 | 1 | 0,17 | https://www.gotronic.fr/art-10-resistances-1-4w-1-0m-8486-2602.htm https://fr.farnell.com/multicomp/mf25-1m/resistance-1m-0-25w-1/dp/9341137
R5, R7 | 140 Ω, 5 %, ¼ W |  | 2 |  |  |  |  |  |  |  | 2 | 10 | 0,750 | 1 | 0,75 | https://fr.farnell.com/vishay/mrs25000c1400fct00/resist-couche-mince-140r-1-600mw/dp/9464514
R6 | 110 Ω, 5 %, ¼ W |  | 1 |  |  |  |  |  |  |  | 1 | 1 | 0,067 | 1 | 0,07 | https://www.musikding.de/110R-metal-film-1 https://fr.farnell.com/multicomp/mf25-110r/resistance-0-25w-1-110r/dp/9341161
R8, R9, R26–R43, R60–R79 | 10 kΩ, 5 %, ¼ W |  | 40 |  |  |  |  |  |  |  | 40 | 10 | 0,167 | 4 | 0,67 | https://www.gotronic.fr/art-10-resistances-1-4w-10k-8486-19.htm https://fr.farnell.com/multicomp/mf25-10k/resistance-10k-0-25w-1/dp/9341110
RN10-17, RN18-25, RN44-51, RN52-59 | Resistor network, 8 × 10 kΩ bussed, 5 %, ¼ W, SIP9 |  | 4 |  |  |  |  |  |  |  | 4 | 1 | 0,202 | 4 | 0,81 | https://fr.farnell.com/multicomp/mcrnla09g0103b0e/reseau-de-resistance-10k-2-1-8w/dp/1973141 https://www.gotronic.fr/art-reseau-de-8-x-10k-8486-point-commun-2970.htm
U1 | A/D converter, 10 bits, 8 channels, SPI | Microchip MCP3008-I/P | 1 |  |  |  |  |  |  |  | 1 | 1 | 2,070 | 1 | 2,07 | https://fr.farnell.com/microchip/mcp3008-i-p/10bit-adc-2-7v-8ch-spi-16dip/dp/1627174
U1 | IC socket, 16 pins, 7.62mm, hollow body | SUP16T | 1 |  |  |  |  |  |  |  | 1 | 1 | 0,367 | 1 | 0,37 | https://www.gotronic.fr/art-support-tulipe-sup16t-4606.htm
U3, U4 | Port expander, I2C | Microchip MCP23017-E/SP | 2 |  |  |  |  |  |  |  | 2 | 1 | 1,130 | 2 | 2,26 | https://fr.farnell.com/microchip/mcp23017-e-sp/16-bit-expander-i-o-i2c-i-f/dp/1332088
U3, U4 | IC socket, 28 pins, 7.62mm, hollow body | SUP28TE | 2 |  |  |  |  |  |  |  | 2 | 1 | 0,625 | 2 | 1,25 | https://www.gotronic.fr/art-support-tulipe-sup28te-220.htm
CASE & MISC. PARTS
 | Processing unit | Raspberry Pi 4B |  | 1 |  |  |  |  |  |  | 1 | 1 | 31,360 | 1 | 31,36 | https://fr.farnell.com/raspberry-pi/rpi4-modbp-1gb/raspberry-pi-4-model-b-1gb/dp/3051885
 | PSU for the RPi4 | Recom RAC15-05SK |  | 1 |  |  |  |  |  |  | 1 | 1 | 13,690 | 1 | 13,69 | https://fr.farnell.com/recom-power/rac15-05sk/alimentation-ac-dc-5v-3a/dp/2900646 https://fr.farnell.com/mean-well/irm-15-5/alimentation-ac-dc-5v-3a/dp/2815503
 | USB-C male plug with cable | Molex 68798-0009 |  | 1 |  |  |  |  |  |  | 1 | 1 | 4,580 | 1 | 4,58 | https://fr.farnell.com/molex/68798-0009/cable-usb-2-0-male-male-1m/dp/2894286
 | Display, HDMI, 800 × 480 | Waveshare 4inch HDMI LCD (12030) |  | 1 |  |  |  |  |  |  | 1 | 1 | 38,170 | 1 | 38,17 | https://www.waveshare.com/4inch-hdmi-lcd.htm
 | HDMI cable | Waveshare DIY HDMI Cable |  | 1 |  |  |  |  |  |  | 1 | 1 | 1,000 | 1 | 1,00 | https://www.waveshare.com/product/accessories/wire-adapter/ffc-20pin-0.5pitch-0.5m-opposite-side-contact.htm
 | Micro HDMI plug | Waveshare DIY HDMI Cable |  | 1 |  |  |  |  |  |  | 1 | 1 | 3,000 | 1 | 3,00 | https://www.waveshare.com/product/accessories/wire-adapter/micro-hdmi-adapter-horizontal.htm
 | HDMI plug, angled | Waveshare DIY HDMI Cable |  | 1 |  |  |  |  |  |  | 1 | 1 | 2,500 | 1 | 2,50 | https://www.waveshare.com/product/accessories/wire-adapter/hdmi-adapter-vertical.htm
 | Prototyping board 100×160mm² | Roth Elektronik RE210-S1 |  | 1 |  |  |  |  |  |  | 1 | 1 |  | 1 | 0,00
Audio board | Toroidal transformer, 230 V to 2×15 V, 2×7.5VA or more (500 mA in the secundary) | Audiophonics |  |  |  |  |  | 1 |  |  | 1 | 1 | 14,9167 | 1 | 14,92 | https://www.audiophonics.fr/fr/transformateurs-toriques/transformateur-torique-30va-2x15v-p-3629.html https://fr.farnell.com/multicomp/mcta015-15/transformateur-15va-2x-15v/dp/9530266 | The Multicomp transformer works also for 110V mains.
LED board, 2 rot. enc. boards, navigation board | Prototyping board 100×160mm² | Roth Elektronik RE210-S1 |  | 1 |  |  |  |  |  |  | 1 | 1 | 5,660 | 1 | 5,66 | https://fr.farnell.com/roth-elektronik/re210-s1/carte-prototypage-re210-s1/dp/1221149
Audio connections | Symmetrical shielded patch cable (meters) | Sommer Cable SC Isopod SO-F22 Sommer Cable Cicada SO-D14 |  | 2 |  |  |  |  |  |  | 2 | 1 | 0,392 | 2 | 0,78 | https://www.thomann.de/fr/sommer_cable_sc_isopod_so_f22_blk.htm https://www.thomann.de/fr/sommer_cicada_sod14_sw.htm
 | Thin wrapping wire (meters) |  |  | 1 |  |  |  |  |  |  | 1 |  |  | 1 | 0,00 |  | One can use standard wires
 | Low-voltage signal wire (meters). ~0.2 mm² | FC25* |  | 21 |  |  |  |  |  |  | 21 |  | 0,167 | 21 | 3,50 | https://www.gotronic.fr/art-fil-de-cablage-fc25n-5076.htm https://www.musikding.de/wire-025mm2-5m-black
 | Domestic-voltage wire (meters). ≥ 1 mm² |  |  | 1 |  |  |  |  |  |  | 1 |  |  | 1 | 0,00
 | Faston female connectors 250 mil | JST STO-2.5T-250N |  | 7 |  |  |  |  |  |  | 7 | 100 | 8,330 | 1 | 8,33 | https://fr.farnell.com/jst-japan-solderless-terminals/sto-2-5t-250n/contact-femelle-6-3x0-8mm/dp/3625448
 | Boxes for Faston female connectors | JST 01022-250 |  | 7 |  |  |  |  |  |  | 7 | 100 | 3,130 | 1 | 3,13 | https://fr.farnell.com/jst-japan-solderless-terminals/01022-250/capot-pour-connect-femelle-6-3mm/dp/3625527
 | Terminal, 3mm | COZ30 |  | 11 |  |  |  |  |  |  | 11 | 100 | 2,000 | 1 | 2,00 | https://www.gotronic.fr/art-100-cosses-a-souder-3-mm-coz30-4690.htm
 | Set of heat-shrinkable tubes |  |  |  |  |  |  |  |  |  | 0 |  |  | 0 | 0,00
2 audio inputs | Input combo jack + XLR, female | Neutrik NCJ9 FI-S |  |  |  | 1 |  |  |  |  | 2 | 1 | 3,233 | 2 | 6,47 | https://www.thomann.de/fr/neutrik_ncj_9_fis.htm https://fr.farnell.com/neutrik/ncj9fi-h/embase-xlr-jack-6-35mm-coudee/dp/5008372 | FI-H fits too, but is less handy to solder.
3 expression pedals 2 audio outputs | Jack socket, female, stereo | Neutrik Rean NYS230 |  | 3 |  |  | 2 |  |  |  | 5 | 1 | 1,375 | 5 | 6,88 | https://www.musikding.de/Rean-Neutrik-phone-jack-stereo-NYS230
12 pedals | Momentary footswitch | Toowei T601A21U |  | 12 |  |  |  |  |  |  | 12 | 1 | 2,333 | 12 | 28,00 | https://www.musikding.de/1PST-momentary-footswitch-soft-short
6 navigation switches | Momentary button | Multimec 5GTH935 |  | 6 |  |  |  |  |  |  | 6 | 1 | 1,980 | 6 | 11,88 | https://fr.farnell.com/multimec/5gth935/commutateur-tht-ip67-3-5n-0-05a/dp/2280480
 | Caps for the momentary buttons | Multimec 1US09 |  | 6 |  |  |  |  |  |  | 6 | 5 | 1,510 | 2 | 3,02 | https://fr.farnell.com/multimec/1us09/cap-round-10-6mm-convex-noir/dp/2280433
2+5 rot. enc. | Rotary encoder with push button | Bourns PEC11R-4215F-S0024 |  | 7 |  |  |  |  |  |  | 7 | 1 | 1,560 | 7 | 10,92 | https://fr.farnell.com/bourns/pec11r-4215f-s0024/codeur-increment-2canal-24impuls/dp/2474844
 | Caps for the rotary encoders | Multicomp CR-BA-7C6-180D |  | 7 |  |  |  |  |  |  | 7 | 5 | 3,580 | 2 | 7,16 | https://fr.farnell.com/multicomp/cr-ba-7c6-180d/bouton-15-7mm-noir-blanc-line/dp/1441142
 | LED, red, 20 mA, > 20 mcd | Kingbright L-9294SURCK |  | 2 |  |  |  |  |  |  | 2 | 5 | 0,000 | 1 | 0,00 | https://fr.farnell.com/kingbright/l-9294surck/led-wide-view-130-rouge/dp/2079968 https://fr.farnell.com/kingbright/l-57srsrd/led-5mm-rouge-150mcd-640nm/dp/2217956
 | LED, green, 20 mA, > 20 mcd | Kingbright L-9294CGCK |  | 1 |  |  |  |  |  |  | 1 | 5 | 0,880 | 1 | 0,88 | https://fr.farnell.com/kingbright/l-9294cgck/led-wide-view-130-vert/dp/2079971 https://fr.farnell.com/kingbright/l-53sgc/led-5mm-ultra-vert/dp/1142572
2 rot. enc. w/sw 1 LED | Connector NSK254 1×4, case | MPE-Garry 431-1-004-X-KS0 |  | 6 |  |  |  |  |  |  | 6 | 1 | 0,067 | 6 | 0,40 | https://www.gotronic.fr/art-boitier-nsk254-4b-15398.htm
5 rot. enc 3 expr. pedals | Connector NSK254 1×3, case | MPE-Garry 431-1-003-X-KS0 |  | 13 |  |  |  |  |  |  | 13 | 1 | 0,050 | 13 | 0,65 | https://www.gotronic.fr/art-boitier-nsk254-3b-170.htm
 | Connector NSK254, female contact | MPE-Garry 611-1-TX-X |  | 63 |  |  |  |  |  |  | 63 | 10 | 0,167 | 7 | 1,17 | https://www.gotronic.fr/art-10-contacts-nsk254-0-171.htm
2 rot. enc w/sw 1 LED | Connector NSK254 1×4, base | MPE-Garry 428-1-004-0-T-KS0 |  | 3 |  |  |  |  |  |  | 3 | 1 | 0,100 | 3 | 0,30 | https://www.gotronic.fr/art-connecteur-nsk254-4-15396.htm
5 rot. enc. | Connector NSK254 1×3, base | MPE-Garry 428-1-003-0-T-KS0 |  | 5 |  |  |  |  |  |  | 5 | 1 | 0,083 | 5 | 0,42 | https://www.gotronic.fr/art-connecteur-nsk254-3-15395.htm
Navigation switches | 2-row breakable Dupont pin header, pitch 2.54 mm | 2×36 pins |  | 4 |  |  |  |  |  |  | 4 | 36 | 0,750 | 1 | 0,75 | https://www.gotronic.fr/art-connecteur-he14-mh200-4459.htm
Pi4 GPIO link | HE10 ribbon cable, 2×20, 300 mm | Amphenol FC40300-S |  | 1 |  |  |  |  |  |  | 1 | 1 | 2,180 | 1 | 2,18 | https://fr.farnell.com/amphenol/fc40300-s/cordon-2-54mm-f-f-s-r-300mm-40voies/dp/2217675
1 audio board | Dupont case, 1×10 | Multicomp 2226A-10 |  | 2 |  |  |  |  |  |  | 2 | 50 | 3,395 | 1 | 3,40 | https://fr.farnell.com/multicomp/2226a-10/a-sertir-boitier-1-rangee-10-voies/dp/1593513
2 display 2 navigation | Dupont case, 2×4 | NDR-08 |  | 4 |  |  |  |  |  |  | 4 | 25 | 2,083 | 1 | 2,08 | https://www.gotronic.fr/art-25-boitiers-ndr-08-29006.htm
1 footswitch | Dupont case, 2×8 | Multicomp 2226B-16 |  | 1 |  |  |  |  |  |  | 1 | 10 | 1,560 | 1 | 1,56 | https://fr.farnell.com/multicomp/2226b-16/a-sertir-boitier-2-rangee-16voies/dp/1593525 | Optional, we can use two 2×4 cases
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

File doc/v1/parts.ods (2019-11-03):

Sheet: Parts
Description | Model | Quantity | Units per set | Price per set (tax-free) | Number of sets | Price | URL | Note
Processing unit | Raspberry Pi 3 model B | 1 | 1 | 31,410 | 1 | 31,41 | http://fr.farnell.com/raspberry-pi/raspberrypi3-modb-1gb/sbc-raspberry-pi-3-mod-b-1gb-ram/dp/2525225
Radiator for Pi 3 | ? | 1 | 1 | 3,900 | 1 | 3,90 | http://www.gotronic.fr/art-radiateurs-pour-raspberry-19847.htm
USB Sound interface | PreSonus Audiobox USB | 1 | 1 | 70,833 | 1 | 70,83 | http://www.thomann.de/fr/presonus_audiobox_usb.htm
5V DC 2.5A power supply | Stontronics T6090DV | 1 | 1 | 6,910 | 1 | 6,91 | http://fr.farnell.com/stontronics/t6090dv/psu-raspberry-pi-5v-2-5a-uk-euro/dp/2520786
5V DC 450mA cheap mobile charger | ? | 1 | 1 | 0,000 | 1 | 0,00 | Second hand
Micro-SD card + NOOBS | Transcend TSRASPI10-16G | 1 | 1 | 8,890 | 1 | 8,89 | http://fr.farnell.com/transcend/tsraspi10-16g/16gb-microsd-card-preloaded-with/dp/2521753
Expression pedal | Yamaha FC-7 | 1 | 1 | 49,167 | 1 | 49,17 | http://www.thomann.de/fr/yamaha_fc7.htm
Display 128×64 | LCD12864DFR (Digole 12864ZW) | 1 | 1 | 18,250 | 1 | 18,25 | http://www.gotronic.fr/art-module-graphique-lcd12864dfr-19395.htm
Prototyping board 100×160mm² | Roth Elektronik RE210-S1 | 2 | 1 | 5,660 | 2 | 11,32 | https://fr.farnell.com/roth-elektronik/re210-s1/carte-prototypage-re210-s1/dp/1221149
Wire, soft, insulated, black, 0.2mm² (1m) | FC25N | 36 | 1 | 0,167 | 36 | 6,00 | http://www.gotronic.fr/art-fil-de-cablage-fc25n-5076.htm | Total wire length: 36m
Wire, soft, insulated, grey, 0.2mm² (1m) | FC25G | 0 | 1 | 0,167 | 0 | 0,00 | http://www.gotronic.fr/art-fil-de-cablage-fc25g-5077.htm
Wire, soft, insulated, brown, 0.2mm² (1m) | FC25GR | 0 | 1 | 0,167 | 0 | 0,00 | http://www.gotronic.fr/art-fil-de-cablage-fc25br-5078.htm
Wire, soft, insulated, violet, 0.2mm² (1m) | FC25VI | 0 | 1 | 0,167 | 0 | 0,00 | http://www.gotronic.fr/art-fil-de-cablage-fc25vi-5079.htm
Wire, soft, insulated, blue, 0.2mm² (1m) | FC25B | 0 | 1 | 0,167 | 0 | 0,00 | http://www.gotronic.fr/art-fil-de-cablage-fc25b-5080.htm
Wire, soft, insulated, green, 0.2mm² (1m) | FC25V | 0 | 1 | 0,167 | 0 | 0,00 | http://www.gotronic.fr/art-fil-de-cablage-fc25v-5081.htm
Wire, soft, insulated, red, 0.2mm² (1m) | FC25R | 0 | 1 | 0,167 | 0 | 0,00 | http://www.gotronic.fr/art-fil-de-cablage-fc25r-5082.htm
Wire, soft, insulated, orange, 0.2mm² (1m) | FC25O | 0 | 1 | 0,167 | 0 | 0,00 | http://www.gotronic.fr/art-fil-de-cablage-fc25o-5083.htm
Wire, soft, insulated, yellow, 0.2mm² (1m) | FC25Y | 0 | 1 | 0,167 | 0 | 0,00 | http://www.gotronic.fr/art-fil-de-cablage-fc25j-5084.htm
Wire, soft, insulated, white, 0.2mm² (1m) | FC25BL | 0 | 1 | 0,167 | 0 | 0,00 | http://www.gotronic.fr/art-fil-de-cablage-fc25bl-5085.htm
Wire, single conductor, insulated, 0.2mm², multicolour set (total 60m) | FCR60 | 1 | 1 | 9,083 | 1 | 9,08 | http://www.gotronic.fr/art-assortiment-fcr60-5212.htm | Optional. We could use the soft wires
Wire, single conductor, 0.2mm², 138m | Pro Power TCW25 250G | 1 | 1 | 12,350 | 1 | 12,35 | http://fr.farnell.com/pro-power/tcw25-250g/fil-de-cuivre-etame-tcw-25swg/dp/1230990 | Actually required: 5m
Audio cable, mono (2m) | Sommer Cable The Spirit LLX | 2 | 1 | 2,167 | 2 | 4,33 | http://www.thomann.de/fr/sommer_cable_the_spirit_llx.htm
Audio cable, balanced (2m) | Sommer Cable Galileo 238 / SW | 2 | 1 | 2,167 | 2 | 4,33 | https://www.thomann.de/fr/sommer_cable_galileo_238sw.htm
Jack, female, stereo, 6.35mm | Neutrik NYS230 | 6 | 1 | 3,490 | 6 | 20,94 | http://fr.farnell.com/neutrik/nys230/embase-jack-panneau-6-35mm-stereo/dp/4632667
Jack, male, stereo, 6.36mm | Neutrik NP3X | 3 | 1 | 2,742 | 3 | 8,23 | http://www.thomann.de/fr/neutriknp_3_x.htm
Jack, female, mono, 6.35mm | Neutrik NYS229 | 2 | 1 | 2,900 | 2 | 5,80 | http://fr.farnell.com/neutrik/nys229/embase-jack-panneau-6-35mm-mono/dp/4632655
Jack, male, mono, 6.35mm | Neutrik NP2X | 2 | 1 | 3,060 | 2 | 6,12 | http://fr.farnell.com/neutrik/np2x/fiche-male-6-35mm-2p/dp/8314535
USB type A male port with right angle | Lumberg 2410 07 | 1 | 1 | 1,780 | 1 | 1,78 | http://fr.farnell.com/lumberg/2410-07/fiche-usb-2-0-type-a-angle-droit/dp/1308875
USB type B female socket | Multicomp MC32597 | 1 | 1 | 0,659 | 1 | 0,66 | http://fr.farnell.com/multicomp/mc32597/embase-usb-2-0-type-b-traversant/dp/1696538
USB type B male plug | Keystone Electronics 926 | 1 | 1 | 1,270 | 1 | 1,27 | http://www.mouser.fr/ProductDetail/Keystone-Electronics/926/
Momentary footswitch | Toowei T601A21 ? | 12 | 1 | 2,333 | 12 | 28,00 | http://www.musikding.de/1PST-momentary-footswitch-soft-short
Momentary button | Multicomp MCPAS6-D1-M1CES2-5 | 6 | 1 | 3,110 | 6 | 18,66 | http://fr.farnell.com/multicomp/mcpas6-d1-m1ces2-5/commutateur-carree-noir/dp/2146917
Rotary encoder with push button | Bourns PEC11R-4215F-S0024 | 7 | 1 | 1,790 | 7 | 12,53 | http://fr.farnell.com/bourns/pec11r-4215f-s0024/codeur-increment-2canal-24impuls/dp/2474844
Cap for rotary encoders | Multicomp CR-BA-7C6-180D | 7 | 1 | 0,556 | 7 | 3,89 | http://fr.farnell.com/multicomp/cr-ba-7c6-180d/bouton-15-7mm-noir-blanc-line/dp/1441142
Capacitor, 4700µF, electrolytic, 16V | Panasonic EEUFR1C472B | 1 | 1 | 1,970 | 1 | 1,97 | http://fr.farnell.com/panasonic-electronic-components/eeufr1c472b/condensateur-elec-alu-4700uf-16v/dp/1800647
Capacitor, 1µF, ceramic | Multicomp MCMLR50V105KX7R | 1 | 1 | 0,448 | 1 | 0,45 | http://fr.farnell.com/multicomp/mcmlr50v105kx7r/condensateur-ceramique-x7r-1uf/dp/2112947
Capacitor, 100nF, ceramic | Multicomp MC0805B104K500A2.54MM | 40 | 1 | 0,090 | 40 | 3,61 | http://fr.farnell.com/multicomp/mc0805b104k500a2-54mm/condensateur-mlcc-x7r-100nf-50v/dp/2309020
Capacitor, 100nF, film | MKT IRD607 LCC or MKT370 PHILIPS | 1 | 1 | 0,130 | 1 | 0,13 | http://www.gotronic.fr/art-condensateur-lcc-100-nf-66.htm
Resistor 1W, 2.2Ω | ? | 1 | 1 | 0,080 | 1 | 0,08 | http://www.gotronic.fr/art-resistance-carbone-1w-2-2-8486-2717.htm
Resistor ¼W, 39Ω | ? | 1 | 10 | 0,167 | 1 | 0,17 | http://www.gotronic.fr/art-10-resistances-1-4w-39-8486-2560.htm
Resistor ¼W, 56Ω | ? | 2 | 10 | 0,167 | 1 | 0,17 | http://www.gotronic.fr/art-10-resistances-1-4w-56-8486-2562.htm
Resistor ¼W, 1.5kΩ | ? | 1 | 10 | 0,167 | 1 | 0,17 | http://www.gotronic.fr/art-10-resistances-1-4w-1-5k-8486-2576.htm
Resistor ¼W, 10kΩ | ? | 72 | 10 | 0,167 | 8 | 1,33 | http://www.gotronic.fr/art-10-resistances-1-4w-10k-8486-19.htm
Resistor ¼W, 1MΩ | ? | 3 | 10 | 0,167 | 1 | 0,17 | http://www.gotronic.fr/art-10-resistances-1-4w-1-0m-8486-2602.htm
Transistor NPN | BC547B | 3 | 1 | 0,125 | 3 | 0,38 | http://www.gotronic.fr/art-transistor-bc547b-1336.htm
LED, red | Kingbright L-9294SURCK | 2 | 1 | 0,181 | 2 | 0,36 | http://fr.farnell.com/kingbright/l-9294surck/led-wide-view-130-rouge/dp/2079968
LED, green | Kingbright L-9294CGCK | 1 | 1 | 0,189 | 1 | 0,19 | http://fr.farnell.com/kingbright/l-9294cgck/led-wide-view-130-vert/dp/2079971
HE10 base connector, 2×20 | HE10BD40 | 1 | 1 | 0,792 | 1 | 0,79 | http://www.gotronic.fr/art-connecteur-he10bd40-20084.htm
HE10 ribbon cable, 2×20, 300 mm | Amphenol FC40300-S | 1 | 1 | 5,190 | 1 | 5,19 | http://fr.farnell.com/amphenol/fc40300-s/cordon-2-54mm-f-f-s-r-300mm-40voies/dp/2217675
HE14 female contact | NDR-T | 99 | 25 | 0,625 | 4 | 2,50 | http://www.gotronic.fr/art-25-contacts-ndr-t-22802.htm
HE14 male connectors, 2×36, breakable | MH200 | 1 | 1 | 0,750 | 1 | 0,75 | http://www.gotronic.fr/art-connecteur-he14-mh200-4459.htm
HE14 case, 1×3 | NSR-03 | 1 | 25 | 0,667 | 1 | 0,67 | http://www.gotronic.fr/art-25-boitiers-nsr-03-22806.htm
HE14 case, 1×8 | Multicomp 2226A-08 | 3 | 10 | 3,270 | 1 | 3,27 | http://fr.farnell.com/multicomp/2226a-08/a-sertir-boitier-1-rangee-8-voies/dp/1593512
HE14 case, 2×4 | Multicomp 2226B-08 | 5 | 10 | 4,100 | 1 | 4,10 | http://fr.farnell.com/multicomp/2226b-08/a-sertir-boitier-2-rangee-8voies/dp/1593521
HE14 case, 2×8 | Multicomp 2226B-16 | 2 | 10 | 1,930 | 1 | 1,93 | http://fr.farnell.com/multicomp/2226b-16/a-sertir-boitier-2-rangee-16voies/dp/1593525 | Optional. We could replace it with 2 2x4 cases.
Connector NSK254, female contact | NSK254-0 | 56 | 10 | 0,167 | 6 | 1,00 | http://www.gotronic.fr/art-10-contacts-nsk254-0-171.htm
Connector NSK254 1×3, base | S003 | 13 | 1 | 0,100 | 13 | 1,30 | http://www.gotronic.fr/art-connecteur-s003-124.htm
Connector NSK254 1×3, case | NSK254-3B | 13 | 1 | 0,050 | 13 | 0,65 | http://www.gotronic.fr/art-boitier-nsk254-3b-170.htm
Connector NSK254 1×4, base | S004 | 4 | 1 | 0,125 | 4 | 0,50 | http://www.gotronic.fr/art-connecteur-s004-5858.htm
Connector NSK254 1×4, case | NSK254-4B | 4 | 1 | 0,667 | 4 | 2,67 | http://www.gotronic.fr/art-boitier-nsk254-4b-15398.htm
Connector NSK254 1×5, base | S005 | 2 | 1 | 0,150 | 2 | 0,30 | http://www.gotronic.fr/art-connecteur-s005-5859.htm
Connector NSK254 1×5, case | NSK254-5B | 2 | 1 | 0,075 | 2 | 0,15 | http://www.gotronic.fr/art-boitier-nsk254-5b-22515.htm
IC socket, 16 pins, 7.62mm | SUP16T | 1 | 1 | 0,333 | 1 | 0,33 | http://www.gotronic.fr/art-support-tulipe-sup16t-4606.htm
IC socket, 28 pins, 7.62mm | SUP28TE | 2 | 1 | 0,625 | 2 | 1,25 | http://www.gotronic.fr/art-support-tulipe-sup28te-220.htm
IC socket, 14 pins, 7.62mm | SUP14T | 1 | 1 | 0,292 | 1 | 0,29 | http://www.gotronic.fr/art-support-tulipe-sup14t-4605.htm
A/D converter, 10 bits, 8 channels, SPI | Microchip MCP3008-I/P | 1 | 1 | 2,070 | 1 | 2,07 | http://fr.farnell.com/microchip/mcp3008-i-p/10bit-adc-2-7v-8ch-spi-16dip/dp/1627174
Port expander, I2C | Microchip MCP23017-E/SP | 2 | 1 | 1,140 | 2 | 2,28 | http://fr.farnell.com/microchip/mcp23017-e-sp/16-bit-expander-i-o-i2c-i-f/dp/1332088
AND gate (4×) | 74HC08 | 1 | 1 | 0,250 | 1 | 0,25 | http://www.gotronic.fr/art-74hc08-10012.htm
Terminal 3mm | COZ30 | 1 | 100 | 1,917 | 1 | 1,92 | http://www.gotronic.fr/art-100-cosses-a-souder-3-mm-coz30-4690.htm | Actually required: 1 piece
C14 (IEC 60320) power socket | ? | 1 | 1 | 4,230 | 1 | 4,23 | http://fr.rs-online.com/web/p/connecteurs-iec/0488191/
Insulation for C14 power socket | ? | 1 | 5 | 3,380 | 1 | 3,38 | http://fr.rs-online.com/web/p/products/5260724/ | Actually required: 1 piece
Power switch | C6003L | 1 | 1 | 1,750 | 1 | 1,75 | http://www.gotronic.fr/art-interrupteur-c6003l-4219.htm
Power socket, female, 2 pins |  | 1 | 1 | 0,917 | 1 | 0,92 | http://www.leroymerlin.fr/v3/p/produits/fiche-electrique-femelle-2-poles-6-a-debflex-e29634
Wire, 2 ways, 220V |  | 1 | 1 | 2,958 | 1 | 2,96 | http://www.leroymerlin.fr/v3/p/produits/cable-electrique-h03vvf-blanc-l-5-m-e28732 | Actually required: 1m
Strut 4mm | ? | 8 | 10 | 0,750 | 1 | 0,75 | http://www.gotronic.fr/art-10-entretoises-lisses-4-mm-23179.htm
Strut 5mm | ? | 18 | 10 | 0,792 | 2 | 1,58 | http://www.gotronic.fr/art-10-entretoises-lisses-5-mm-23180.htm
Strut 10mm | ? | 2 | 10 | 1,000 | 1 | 1,00 | http://www.gotronic.fr/art-10-entretoises-lisses-10-mm-23182.htm | We could combine the remains of the 4 and 5mm sets to get 9mm struts instead.
Screw, M3, 20mm | ? |  | 10 | 0,292 | 0 | 0,00 | http://www.gotronic.fr/art-10-vis-acier-m3-20mm-6508.htm
Nut, M3 | ? |  | 10 | 0,167 | 0 | 0,00 | http://www.gotronic.fr/art-10-ecrous-acier-m3-6510.htm
Washer, M3 | ? |  | 10 | 0,125 | 0 | 0,00 | http://www.gotronic.fr/art-10-rondelles-acier-m3-6511.htm
Screw, M2.5, wood |  | 30 |  |  | 30 | 0,00
Sheet of steel, 1000×600×0.75mm |  | 1 | 1 | 13,000 | 1 | 13,00 | http://www.leroymerlin.fr/v3/p/produits/tole-lisse-acier-brut-l-100-x-l-60-cm-x-ep-0-75-mm-e19323 | Actually required: 500×600
Corner piece, aluminium, 19.5×1000×1.5mm |  | 1 | 1 | 3,792 | 1 | 3,79 | http://www.leroymerlin.fr/v3/p/produits/corniere-egale-aluminium-brut-l-1-m-x-l-1-95-cm-x-h-1-95-cm-e17200 | Actually required: 500mm
Wood board, 20mm |  | 1 | 1 |  | 1 | 0,00
Wood board, 10mm |  | 1 | 1 |  | 1 | 0,00
Rubber leg | SJ5009 | 8 | 4 | 0,420 | 2 | 0,84 | http://www.gotronic.fr/art-pieds-a-visser-pour-coffrets-sj5009-6356.htm
 |  |  |  |  | 0 | 0,00
 |  |  |  |  | 0 | 0,00
 |  |  |  |  | 0 | 0,00
Shipping fees |  | 5 | 1 | 7,000 | 5 | 35,00
Total |  |  |  |  |  | 457,17

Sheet: Wire lengths
Wire lengths
Part | Length (m) | Number of cables | Wires per cable | Total length
Rotenc5 | 0,35 | 5 | 3 | 5,25
Rotenc2 | 0,4 | 2 | 4 | 3,2
Rotenc board | 0,8 | 1 | 6 | 4,8
Switch board | 0,7 | 1 | 8 | 5,6
LED board | 0,4 | 1 | 5 | 2
Display | 0,6 | 1 | 9 | 5,4
Display fix | 0,2 | 1 | 5 | 1
Buttons | 0,25 | 6 | 1 | 1,5
Button ground | 0,35 | 1 | 1 | 0,35
Pedals | 0,25 | 12 | 1 | 3
Pedal ground | 0,65 | 2 | 1 | 1,3
Expression pedal | 0,25 | 3 | 3 | 2,25
Total |  |  |  | 35,65

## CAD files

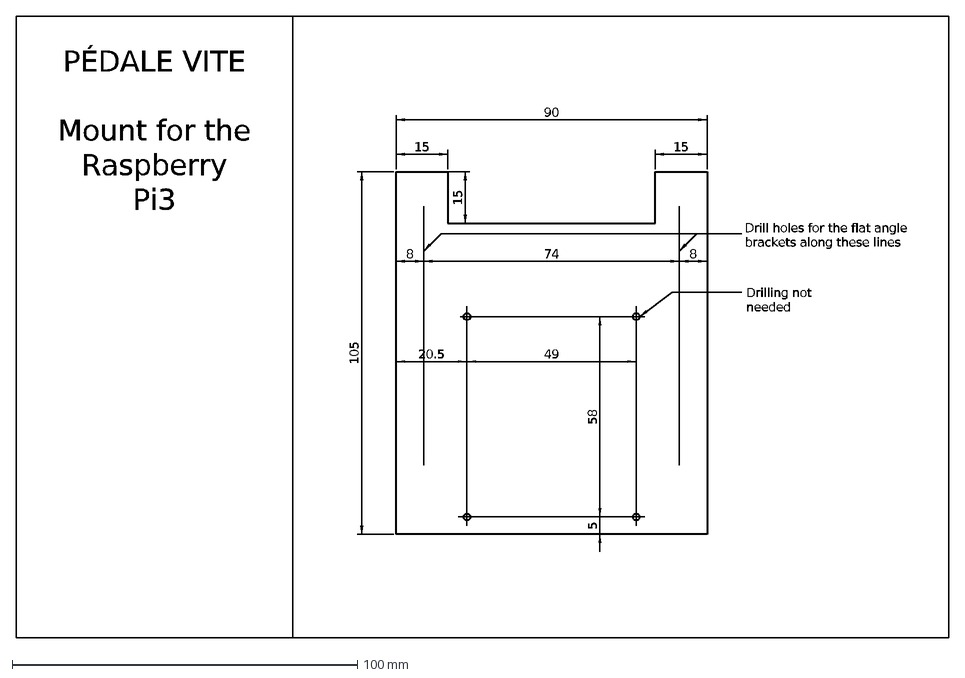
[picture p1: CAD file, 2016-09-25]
doc/v1/drawing-pi-mount.dxf
90
105
Drilling not needed
Drill holes for the flat angle brackets along these lines
8
74
PÉDALE VITE Mount for the Raspberry Pi3
15
49
20.5
5
58

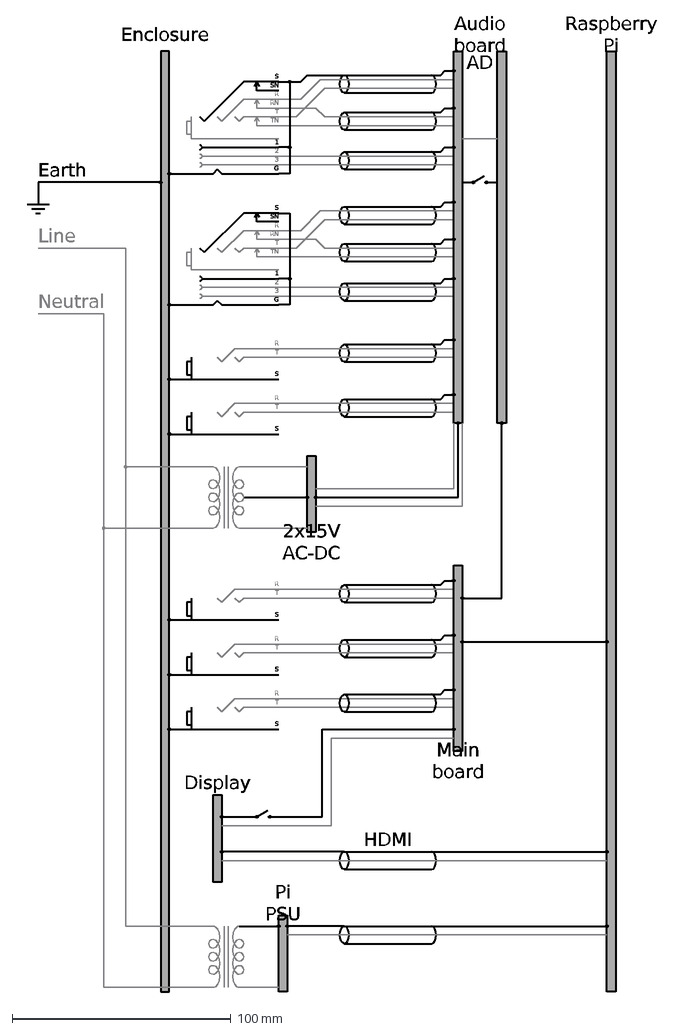
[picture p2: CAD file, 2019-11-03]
doc/ground-path.dxf
S
SN
R
RN
T
TN
1
2
3
G
A
D
Enclosure
Audio board
Raspberry Pi
Earth
Line
Neutral
Display
2x15V AC-DC
HDMI
Main board
Pi PSU

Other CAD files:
doc/drawing-panel.dxf
doc/user-manual/sources/panel.dxf
doc/v1/user-manual/sources/panel.dxf
doc/v1/drawing-panel.dxf

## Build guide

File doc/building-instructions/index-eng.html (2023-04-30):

# Pédale Vite v2 — Building instructions

## Table of content

1. Introduction
2. Required materials
  1. Drawings
  2. Materials
  3. Tools
3. Step-by-step building
  1. Enclosure
  2. Electronics
  3. Assembly
4. Software setup
  1. Preparing the system
  2. Startup and system update
  3. Basic configuration
  4. Boot time optimisation
  5. Software dependencies
  6. Installing Clang (optional)
  7. Installing Pédale Vite
  8. Pédale Vite autostart
  9. Read-only operating system and other optimisations
5. Maintenance
  1. Tests and troubleshooting
  2. Source code
6. Possible improvements and variations
7. Version history

## I. Introduction

Pédale Vite is a DIY (“do it yourself”) multi-effect pedalboard for guitar and bass. This manual decribes how to build it and install all required components.

I want to make it clear, this project is quite complex moderately difficult but within reach of everyone. One does not need to be a DIY genius. One does not need to be dexterous. No specific ability is required. All used skills (soldering, drilling…) are not trivial but they are easy and quick to learn.

However the realisation requires a significant amount of work, count about ten days of work. This is approximately the time I’ve spend to build Pédale Vite. And I’m far from being well organised and dexterous. I’m pretty sure seasoned people could halve this time without hassle.

It is advised to start by reading the full instructions before beginning, in order to have a better view of the operations.

## II. Required materials

The project’s GitHub repository (https://github.com/EleonoreMizo/pedalevite/) contains all the required files.

- .pro schematics open with KiCAD (http://kicad-pcb.org/), v6.0.2 here.
- .dfx drawings open with LibreCAD (http://librecad.org/), v2.2.0 here.
- .ods spreadsheets open with LibreOffice (https://www.libreoffice.org/) or OpenOffice (https://www.openoffice.org/).

Some documents have been exported to .png or .pdf for convenience.

### Drawings

Drawings are in the doc (https://github.com/EleonoreMizo/pedalevite/tree/master/doc) folder in the repository.

- The boards folder contains KiCAD electronic schematics as well as the PCB layouts for all the boards.
- drawing-panel.dxf shows how to drill the plates for the enclosure.
- cables.ods show how to build and connect the cables. Each pair of letters indicates matching pins for a single wire.

These drawings are not exhaustive. For example, cables for the Pi powering or power cords are missing. However these parts are quite simple and don’t need detailed instructions.

### Materials

The bill of materials is in doc/bom.ods on the repository. It shows quantity, quality and physical constraints, as well as an indicative price without tax (from the shop where each component was bought). It’s possible to cut down the price on several components. Some of the parts I used are leftovers from other projects or were bought in unnecessary large quantities here. It is possible to optimise this point. It’s also possible to use other materials, as long as they are compatible or adjustable to the existing design.

For your information, all the resistors are ¼ W, mostly because of their size on the board.

### Tools

- Drawing pencil, or better a mechanical pencil, to draw through the holes of a prototyping board
- Fine compass or any other tools for drawing circles of diameter 10, 11, 12 and 24 mm (if using a non-stepped unibit).
- Ruller
- Protractor
- Chisel
- Wood saw
- Metal saw
- Metal file, flat
- Metal file with a round section, as fine as possible (3–5 mm)
- Workbench
- A pair of clamps
- Disposable woodboards (from pallets for example) to use as drilling stand or helper.
- Drill, or a drill press if possible
- Drill bit for wood, 2 mm
- Drill bits, unibit or hole saws to cut steel at diameters of 3, 4, 5, 7, 10, 11, 12 and 24 mm
- Center punch or sharp, pointed screw
- Small multi-usage handheld tool (Dremel, Proxxon…) with cutting ability
- Cutting discs for steel (if possible in both small and large diameters)
- Cutting oil
- Set of spanners : 5, 5.5, 6, 10, 13 and 14 mm
- Flat screwdriver
- Cross-head screwdriver (PH2 and possibly PH1)
- Hammer
- Thermoregulated soldering iron (50 W or more) with its stand
- Solder 0.5mm and 1mm with flow
- Desoldering pump and possibly desoldering bread
- Third hand
- Vice
- Sponge to clean the iron
- Fine pliers
- Tweezers
- Cutting pliers for component legs
- Crimping tool for small terminals (the PA-09 (http://www.engineer.jp/en/products/pa09e.html) from Engineer are great)
- Crimping tool for Faston 250 terminals
- Stripping tool for small section wires
- Insulating adhesive tape
- Gloves
- Safety glasses
- Respirator, to protect against dust
- Fan or something to suck or repulse toxic releases from soldering
- Multimeter (to measure resistance or test contacts)
- Oscilloscope (optional but handy)
- Marker pens or painting with fine paintbrushes

Tools alone can be expensive. Don’t hesitate to borrow them, steal them or buy them collectively.

## III. Step-by-step building

### Enclosure

#### Machining

First, don’t forget to protect yourself with goggles, respirator and gloves, and possibly some noise reducer depending on your cutting and drilling tools.

Cut the plate with a cutting disc mounted on the multi-usage handheld tool. Use a plank as a guide for the tool so you can cut as straight as possible. Spray cutting oil on the line to avoid heating and save the cutting discs. If you’ve never done it before, it’s recommended to practice on a scrape before.

Cut the following panels :

- Top : 520×250 mm²
- Back : 520×70 mm²
- Front : 520×30 mm²
- Bottom : 520×253 mm²
- Sides : [30–70]×250 mm² (rectangle trapeze)

Note : front and bottom panels can be made of aluminium instead of steel.

Once the panels are cut, deburr with a file and slightly round the corners.

Important : operations are done on the inside of each panel. The drawings are all inside views.

Draw some marks for the drilling and cutting, referring to the drawings (Panels layer). Mark the centers with the center punch. Use the compass to delimit the holes which will be drilled with the reamer. Drill these ones first, with cutting oil. Stop drilling when the reamer reaches the hole outline. Get the component and try to fit it in the hole, and drill slightly more if required.

Deburr the hole with a dedicated reamer or use a cutting disc to eliminate the excess of metal.

Cut two 520 mm pieces from the corner piece. They will join the top panel with the bottom and front pannels. The smallest part of the L will be on top and the longest will be vertical. If required, file the top part of one of the pieces to make room for the display screws.



More room for the screws. Actually it wasn’t really necessary.

Cut two 250 mm corner pieces that will be used as lining for the panel. One of them is stepped over by the audio board; make sure there will be no contact when everything is in place. If so, remove some matter off the corner piece with a file or a cutting disc.

Clamp the latter corner pieces with the plate and drill their common holes simultaneously.

Drill the remaining holes and deburr if necessary. The small holes without indicated diameters one the drawings are 3mm wide. The position and diameter of some holes depend on the actual material you could gather (power socket and switch, connectors, etc.) Don’t blindly follow the drawings, check what you really need and adjust if required.

The LED holes have a 5 mm diameter. It is possible to enlarge them slightly to 6 mm while shifting down the center from half a millimeter. This allows the LEDs to be brought down to the enclosure surface while being still visible even at high incidence.

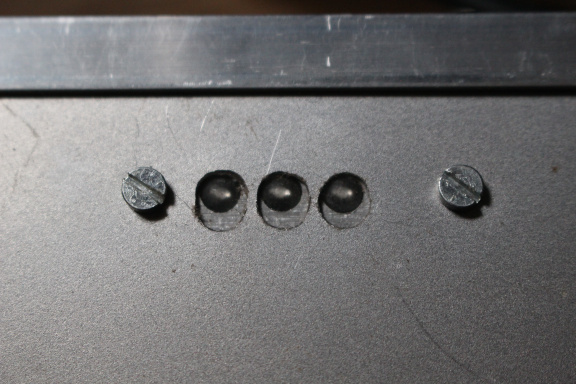
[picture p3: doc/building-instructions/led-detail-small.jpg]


My LED holes are pushed even further and are slightly oval.

Nota bene : the holes to screws the side stands and pillars are slighty shifted at the corners so the screws can cross without colliding.



Screws unalignment, front panel.

It may be easier to leave aside the holes going through the long corner pieces. They will be drilled once these pieces are put on the assembly.

Cut the rectangle zone. Start drilling the corners with a small bit (3 mm is OK, at 1.5 mm from each corner), this will ease joining the cuts. Then cut the lines with a small disc. Deburr and square the angles with a rectangular file.

#### Side stands

Take a 18- to 20 mm-thick plank (max). Cut two trapezoidal shapes, 250 mm on the side with both right angles, and 30 and 70 mm on the adjacent sides. You can check that the opposite side is about 253 mm. The right angles are on the top. Please refer to the drawings (Structure layer) for the dimensions and locations.

With a wood saw and a chisel, cut the windows for the Pi connectors and the gain controls of the audio board.



Window for the Pi connectors.

Then drill and screw the metal plates on the inside.

Screw the front, back and top panels on these wood pieces. Use 3 mm screws, not too long.

Put the long corner piece on the angles and hold them tight. Drill the holes through the corner pieces, the panels and the wood pieces with a 2 mm drill. Then drill the metal parts only with a 3 mm drill.

It is possible to drill all the holes through the corner pieces, even the pillar ones. Add the last side stand screws. Add short metal screws (8–10 mm) with nuts and washers to hold the corner piece against the top panel.

#### Center pillars

The center pillars will support the linings made with the corner pieces. First, screw the latters to the plate if it is not already done. Then cut the pillars of 20 mm square section in wood, preferably a strong variety. One can take the offcut from the previous planks.

The vertical shape of each pillar is a trapeze (side view). The angle (9°) is located at the bottom. The length difference is about 3 mm. Cut a pair of pillars of 30 and 33 mm for the front, and another pair of 67 and 70 mm for the back. Subtract the corner piece thickness from these lengths. Anyway you can also add about half a millimeter which will be trimmed later with a file.

Hold the pillars on the assembly, drill the holes and add screws. Put the assembly on the floor, and check it is not wobbly. If it is, trim the pillar excess with a file.

Then, the baptism of fire : put the assembled enclosure on the floor and stay on it. It should not bend nor give any sign of weakness.

### Electronics

#### The boards

The main board, audio board and 2×15 V AC to DC converter boards are PCBs that you can make manufacture with the Gerber files contained in the doc/boards subfolders.

The other boards are obtained by cutting the following rectangles in the prototyping boards :

- 19×18 full holes, 48.3×45.7 mm², 5V power board
- 20×13 full holes, 50.8×33.0 mm², navigation switch board
- 18× 4 full holes, 45.7×10.1 mm², LED board
- 18× 4 full holes, 45.7×10.1 mm², board to mount rotary encoders for navigation
- 48× 3 full holes, 121,9× 7.6 mm², board to mount rotary encoders for parameter control

Standard prototyping boards contain 61×38 holes. Therefore it’s possible to extract all the boards from the same board. It is possible to use a veroboard or a matrix board, the latter being easier for the circuits to be implemented here.

To cut the board, a metal saw does the job well. Fasten the board on a workbench with a vice or a clamp, between two wood boards to avoid damaging it. Cut it following the middle of a row of pads, of holes, to take advantage of the existing holes.

Drill the mounting holes at the four corners with a 3 mm drill. Without drill press, it’s better to use an existing hole as a guide. Locate each drilled hole at the middle of a 3×3 pad square, free of any conductive function (check doc/boards/misc-boards/misc-boards.kicad_pcb).

When the LED board is cut, build its mounting device before soldering the components. Just see below.

#### Soldering the PCBs

##### Main board

Solder the components in order of height. First the flat resistors, then all the ceramic capacitors located out of IC sockets.

Then check that the internal capacitors can fit inside the sockets without any problems. If necessary, file the plastic of the sockets so that everything fits in correctly without forcing. It is possible to tilt the capacitors or slightly offset them, up to a certain limit.

Then solder the sockets, then the internal capacitors. Then the vertical resistors, then the transistors. Finally, the HE10, Dupont and NSK254 connectors.

Do not immediately place the IC in their holders, there are checks to be done beforehand, see below.

##### Audio board

This board requires some attention. Indeed, there are two surface mounted technology (SMT) components, the CS4272 codec and the MK2703 clock. The CS4272 is particularly delicate since it is a TSSOP, with very thin legs (0.63 mm pitch). These two components must be soldered first. You will need thin soldering wire (0.5 mm), and depending on your visual acuity, perhaps a magnifying glass or a microscope. Very good lighting is necessary in all cases.

There are various soldering techniques for this type of component, generally involving first soldering two legs to immobilize the part, then soldering the rest. There are many photo or video tutorials for manual soldering of SMT chips. The solder flood technique works relatively well, but requires a minimum of practice to be executed cleanly and efficiently. Feel free to practice beforehand on adapter boards with cheap IC that can be sacrificed without regret. Otherwise, go back to the simplest technique, leg by leg. The biggest risk is to pour solder under the chip, behind the legs and bridge them without possibility of going back. In case of a problem, it is almost impossible to unsolder the chip without damaging it (mechanically or thermally) and start again, unless you have a suitable hot air gun.

If you do not feel confident enough for the operation, entrust it to an experienced or professional person. However, it is not that difficult, this board was my first TSSOP chip soldering experience and it works very well.



The audio board.

After soldering the SMT chips, the components are soldered in their order of height : small 1N4448-like diodes, resistors, larger Schottky-like diodes, ceramic capacitors, integrated circuit holders, film capacitors, Dupont connectors and sockets for transistors and regulators, inductors, choke, and finally, in no predefined order, electrolytic capacitors, 5 V regulator, NSK254 power supply connector.

The Q1-Q3 transistors, D9 voltage reference and IC4 regulator are mounted on a single-row round-pin socket rather than soldered directly (this is optional).

Put the quartz in this list according to its actual size, but before soldering it, make sure there is a gap between the component and the PCB. You can insert a piece of cardboard to ensure the gap and remove it once the soldering is complete. Be careful not to overheat it, it could burn.

Tilt the inductors of each channel to form a mutual right angle.

When everything is soldered, fasten the thermal dissipator to IC3.

Finally, insert a jumper on JP1 to select the least significant bit of the board I²C address. Put it between pins 2 et 3 for the address 0, expected by the software part.



I²C address selection with JP1.

As with the main board, do not place the chips in their sockets immediately.

##### 15V AC to DC board

Nothing much to say about this board supplying power for the audio board. Don’t forget to fasten the thermal dissipators on the voltage regulators. L1 and L2 coils have to be bent to form a mutual right angle.



±15 V rectification and filtering. Ignore the model of the diodes in the bridge, it’s not the same as the one in the BOM list.

#### Soldering the prototyping boards

For all the boards : on the component side, first place the main components without soldering them, with the help of the PCB drawings. Draw their outline with a lead pencil. This will ease the placing of the other components.

##### Making tracks

To connect the components on a matrix board, it may be necessary to create tracks on the copper side. These tracks appear in green on the drawings (B.Cu, back copper layer in KiCAD/Pcbnew). To help, capture a screenshot of the diagram (seen from the component side) and mirror it horizontally with a graphic software (Gimp, Photoshop…) This gives a wiring diagram with the correct orientation.

To create a circuit wire, unroll some non-insulated tinned wire. Pull it with a plier in one hand and the reel in the other hand until you feel it has slightly stretched. Stop immediately to avoid breaking it. Then the wire has become straight. Cut it to the desired length (a large segment that will be reused, or a bit more than strictly required for a single connection).

To place it, start from the first free pad. Avoid starting on a pad filled with a component leg, use the next one on the path. With a plier, bend the end of the wire on 1 or 2 mm in order to make a small hook, which will go in the selected pad. Then bend the wire with the plier to make the desired path. You can use a pattern to help measuring the sections, for example with some offcut of the boards. With complex paths, control the wire from time to time by placing it on the circuit and correcting if required. When you’re done, make another hook, control the path and cut the end.

Check carefully what will be soldered on the path. It can be necessary to move aside from the center of the pads to make room for the component legs.

Solder at the ends and at the angles. Add soldering joints on the longest segments, to consolidate.

When soldering components, you will have to add a small bridge to link the track to the component leg.

##### Wires on the components sides

Some boards require wires on the component side. Strip the insulation on 2–3 mm. Wedge it in the hole with a crocodile clip. Don’t bite the wire near the soldering point. Instead, make a kind of reversed U by holding the wire a few centimeters further and by entering the hole perpendicularly to the board. When the wire is heated, the insulation will probably retract and the pressure will make the wire move forward, keeping the insulation as close to the board as possible. This is necessary to avoid short circuits with several wires close to each other.

##### 5V power board

Solder the terminals and then the power supply unit. Connect the legs by soldering bare copper wires or by laying large solder bridges. Refer to the PCB diagram to place these tracks.

Some tracks and pins (J501 and pins 1 and 2 of the power block) carry mains voltages. It will be necessary to carefully scrape the copper around these tracks over at least one pad (2.5mm wide) to avoid any possibility of short circuiting. A mini drill with a small rounded cutter is perfect for this job. Bonus : cover these tracks and pins with varnish.

Also, pay attention to the mounting holes. Ensure that nuts, washers and spacers remain far enough away from the mains tracks.

##### Navigation switch board

On this board, the switches are on the copper side and the connector on the component side. There are two possible approaches. The first is to use the copper on the board to make certain connections, such as ground. This option is relatively simple if you use a Veroboard instead of a matrix board; just cut the tracks in the right places. This is the solution I chose because I had got rests of Veroboard. In the case of a matrix board, tracks must be formed by adding bare copper wires or solder bridges. These conductive elements will then lie under the switches. Ensure that the switches, once in place, rest in a stable and horizontal position on the tracks. In addition, care should be taken to leave open holes to insert the legs of these switches, which can be complicated.

The second option is to wire everything on the component side with insulated wires. In this case, start with the elements near the connector, as the wiring will become quite dense there.

Solder the switches row by row, one by one, from the above. Soldering between two switches can be a little tricky, be careful not to melt the plastic while walking around with the iron. Make sure that the switches are firmly attached to the board when soldering. Indeed, they will have to cope with high and regular pressures, and this must not stress the solder joints.

It is not necessary to connect all the legs. Each switch has four legs, they are connected two by two internally, constituting two unique poles. You can solder and connect just one leg of each pole. Depending on the connection solution chosen, solder the cables as you go along, or after soldering all the switches. It is up to you to evaluate what will be the most practical to do. On the connector, there are only two ground legs for the six switches, so you will need to make derivations.



Navigation switch board, component side.
Here, a strip board (Veroboard) has been used to simplify the wiring.
Wires are soldered on both side for practical reasons.

##### Rotary encoder boards

Like the navigation switches, encoders are solered on the copper side. Ideally, the encoders should be fastened first on the front panel then soldered on the board. However the gap between the encoders and the panel is small, which is not handy.

If it’s too complicated, solder the component as best as you can, check with the panel and fix them if necessary. You can even enlarge slightly the holes with a round file.

Connect the connectors to the encoders using solder bridges. For the two navigation encoders with switches, add insulated wires on the component side to connect the connector legs to both terminals of the switch.



Rotary encoders for parameters



Rotary encoders for navigation

##### LED board

The LED board is somewhat special because it has component on both sides and requires a stand.

The stand supports the LEDs. It lies just under the front panel. Because of the LED size I used (compact ones), my board was about 2mm thick. For higher, standard LEDs, 3–5 mm is fine. It can be in wood, plastic or any other material. There is no specific size for the stand, just fully cover the circuit board, but don’t hesitate to make it larger. Just watch it will not collide with other items in the enclosure.

When the stand is ready, tie the board to it with a clamp, on the copper size. Drill the mounting holes on both elements, so they are correctly aligned. Mark the LED positions on the stand with a pencil through the circuit board holes receiving the LED legs.

Detach the stand and mark the center of the LEDs. Drill the LED holes (⌀ 5 mm). This requires accuracy because the smallest error becomes visible, in an aesthetic point of view.

Put the LEDs on the circuit board without soldering them and assemble everything : the stand wedging the LED heads, the circuit board maintaining the LED legs, the nuts, bolts and struts holding both parts far enough from each other.

The struts must be big enough to leave a couple of millimeters between the circuit board and the LED heads. Indead, LEDs are mounted on the copper side, and will be solered on this side. One-centimeter high struts should be good. If required, use washer to add missing millimeters. Make sure the screws are long enough, counting the panel thickness, nuts and washers.

Make sure the LED are aligned before solering them. Once done, disassemble the board to solder the other components.



Assembly made for a Pédale Vite prototype



LED board, mounted.

#### Connection checks

Before attaching the ICs, the connections must be checked. Use a multimeter in diode test mode or ohm-meter mode. It’s important to do it before mounting the IC on their sockets, because these IC may have internal contacts which will distort the results. Or worse, they could be damaged by the test.

You need a table summing up all the pins of all the connectors. For each of them, check the following :

- For each ground pin, check that no other pin is in contact, excepted other ground pins.
- Same for the power pins. Check on the IC sockets that the power pins are actually connected. However we still got connections with other pins, for example when a pull-up resistor is located between them. Check that this case is justified (buttons), and that the resistance value is correct.
- For each adjacent pin, check that there is no contact between them, or that the obtained resistance is consistent with what is expected.
- Check that all neighbour lumps of solder are not bridging.
- Check that the GPIO-like pins are consistent on the sockets and on the connectors.
- Touch soldered jumper wires when testing them to check that the connection doesn’t move.

These tests don’t guarantee that things will be running smoothly, however they help to detect a lot of potential short circuits.

Once the check is done, ICs can be fit into their supports.

#### Wiring

To connect the Pi and the main board, an old IDE cable does the job well; it is basically a 40-pin HE10 cable. Sometimes the connection is keyed and one of the hole is sealed. Just drill it with the tip of a knife or scissors, the female part of the connector should be there. Check it with a multimeter. Make sure that the cable is a 40-wires one and not a more recent 80-wire Ultra-DMA cable, their layouts are not compatible. Regarding the orientation, the wire which is on the SD-card side on the Pi must land on the left side on the main card.

For the other cables, check the spreadsheet indicating the connections (each letter identifies a wire), the connector types, and the cable lengths. Some cables have crossed wires.

You can twist the cables, this is handy and sometimes makes them more immunte to noise. However, the more the cable is twisted, the shorter it becomes.

Some connectors are keyed, make sure that the female part has the same orientation as the male part. On the other hand, Dupont connectors are not keyed. You must be careful during the connection. You can put a painted mark on both male and female parts to match them more easily.

Buttons and footswitches share a few ground wires. Prepare the cables by crimping them on one side only. They will be soldered and connected later.

##### Audio wiring and ground

All the audio connections should be done with shielded cables, the shield being tied to the ground. Cables with two wires but not shielded (like the gain pot or pads) should be twisted. More generally, use as shortest wire as possible, to minimise exposure to noise.

To prevent ground loops and their induced buzz, the ground should be wired in a star topology, and at worst, in a tree. The links between different ground sections should be unique, otherwise a ground loop is formed.

In Pédale Vite, ground is arranged in the following manner :

- The audio board has two independant ground planes. One for the analogue part, the other one for the digital part. These two grounds should be connected at a single point, the JP2 jumper.
- Tha analogue ground should be connected to the outside only by the first audio input (left), more specifically the jack part of the jack-XLR combo. The ground wires from all other connectors should be connected only to one end. But at least one end is required to make the shielding work.
- Ground from the other audio connectors are connected to the enclosure, either naturally in the case of non-insulated jacks (audio output), either by soldering the ground lug to the lug in contact with the enclosure in the case of isolated combos. This is also true for the combo XLR part from the first input. Be careful with the latter : I added a terminal between the combo and the enclosure, making the combo imperfectly pressed against the side. Therefore the small metal teeth on the combo were not making a good contact (1 Ω is already too much), leading to a ground buzz. So I had to add another terminal linked to the G pin with a wire.
- All power supply units are isolated and should not cause any explicit link to the ground or earth.
- The earth coming from the mains is tied to the enclosure, and consequently to the common ground. Ideally, one should run a wire to plug the earth directly on the ground of the first audio connector to get an explicit star topology. However the back panel from the enclosure is conductive enough to be considered as a ground plane and the earth wire can be connected on one of the screws fastening the mains plug.
- All the panels from the enclosure should be electrically connected. It is possible that the aluminium corner pieces are anodised, so they are not conductive. Therefore the link should be secured with terminals attached to the screws and wires. A groove should be cut in the bottom of one of the center pillar to fit a terminal that will be hold by the screw of a leg.
- The main board ground is linked to the Pi one by the 40-pin connector. This ground is propagated to the display and to the digital ground plane of the audio board. Switches use the main board ground but are isolated.
- However the jacks for the expression pedals make contact with the back panel. Solder only one end of their ground wire.
- Custom boards and the Pi boards have isolated mounting holes, so their ground is not directly linked to the enclosure. Unfortunately, this is not the case with the display. Therefore, it will be necessary to cut its ground plane at the level of each “ear” containing the mounting holes, on both sides of the PCB. Use a sharp tool or the corner of a file. Check with a multimeter that each ear is actually insulated.
- The display has two ground connections with the Pi. One directly with the HDMI cable, the other one with the female GPIO port. Pins from this port are connected to the Pi via the main board for the touchscreen signals. It could be tempting to disconnect the power supply ground, unfortunately the HDMI wires are way too thin, so keep it connected.
- On the audio board, both analogue and digital grounds are not explicitely connected. It is possible to connect them with a jumper on JP2, located near the power supply connector. Once all elements are installed in the enclosure (see below), check with a multimeter that there is a stable and strong contact between both JP2 pins (the small capacitor for HF removal may perturbate the measure). If there is, leave JP2 alone, but you should investigate why there is a contact. If there is not, and that should be the case, add a jumper.

All these considerations should give a loop-free ground.



Ground map (bold lines).

 

Audio input (left) and output (right) connectors.
Please ignore the resistors soldered here for an experiment.



Connection of the analogue and digital grounds with JP2 on the audio board.

 
 
 

Interconnection of the enclosure plates.



Expression pedal connectors.

 

Mounting holes isolated from the ground on the display board.

##### Pi power supply

Raspberry Pi 4 can be powered by a USB-C plug or the GPIO port. We will power it with the USB-C, the ribbon cable connected to the GPIO being not strong enough to convey the required 3 A.

Because it is very difficult to find a naked USB-C plug, we are going to use a USB-A to USB-C powering cord and cut it. We just need about 15cm from the USB-C plug.

Now we should identify the wires. Get the other part of the cable, ending with the USB-A plug, because this plug is bigger and it will be easier to check its pins. From the front (https://en.wikipedia.org/wiki/USB#/media/File:USB.svg), the connector pins being turned upwards, the negative power pin is located at the far left, and the positive one at the far right. Also, it is very likely that the shield is connected to the negative pin. For the +5 V pin, check the continuity between each wire and the pin. Do not trust the insulation colors.

One both wires are found, strip the insulator on 3 mm. If you got the tools, crimp them with small cylindrical terminals, because these wires are thin and may move in the terminal blocks. If not, strip more insulator and fold the copper in order to get more material. Fold the other wires against the main cable and attach them with insulated adhesive tape.

Finally, connect the cable to the terminal blocks according to the polarity.



Pi power supply. The 5 V cable is the white one.

### Assembly

#### First assembly

Most parts can now be screwed to the enclosure : boards, plugs, switches… Because the Pi is very close to the top panel and its PCB is quite flexible, it will be necessary to cut the legs from the USB and RJ45 connectors, which are longer than the other through-hole components. The micro-SD card drive is quite high too. It is connected to the ground so it is not a real problem, but we want to avoid ground loops. To be safe, line the Pi location on the panel with insulating adhesive tape.



Enclosure inside, no cables, no Pi.

Put some insulating tape on the corner piece below the audio board, too.

Also, it will be necessary to put some insulating tape on the bottom metal sheet, in front of the transformer screw. Indeed, if there were a conductive loop going through the torus, it would be equivalent to a short-circuited turn, and would endanger the transformer.



Insulation to protect the transformer screw on the bottom plate.

Speaking about the transformer, I estimated necessary to add a large washer on its mounting screw, to avoid plate deformation under the transformer weight.



Washer stiffening the plate part holding the transformer.

Heights of the struts for each board :

- LEDs : 5–10 mm
- Navigation switches : 10 mm
- Display : 4 mm
- 5V PSU : 5 mm
- Raspberry Pi 4 : 3 mm
- Audio board : 12–13 mm
- Main board : 5 mm
- 2×15 V AC→DC : 5 mm

At this step, it is probably advised to mount the Pi only temporarily. Indeed, access to the SD card will be required when installing the software. When everything will be mounted, it will be difficult to access it.

#### Mains cables

First, insert a fuse in its support, along with a spare one in the second slot. Check with a multimeter how the C14 socket and the switch are wired.

Use stranded wires designed for power supply. Before soldering anything, don’t forget to pass the wires through the insulated sleeves protecting the plugs. Use enough cable to make sure that these sleeves can be moved back when soldering.

There are several cables to build : two for the line and neutral between the socket and the switch, one between the earth and the enclosure, and two between the switch and the 5V module. The 15V transformer has its own wires, which should be connected at the output of the switch too. Therefore the switch lugs should connect two wires each, one going to the 5V module, the other one to the 15V transformer.

If you have got the tools to crimp Faston terminals, cut the wires to the required size and crimp them. Don’t forget to crimp both cables on the same terminal for the switch lugs.

Once the terminals are crimped, add a insulating box. It may be necessary to slightly bend the male lugs on the C14 and switch block to prevent any contact with the bottom part of the enclosure.



Mains wiring using insulated Faston terminals.

Without Faston terminals, the wires should be soldered. Before soldering, don’t forget to put two or three heat-shrinkable tubes per solder joint to avoid letting conductive parts exposed (with the exception of the earth wire).

Fasten both outputs from the transformer in the terminal blocks of the 15V board. These two outputs should be wired in series with the same polarity. On the board, both central terminal blocks are wired together. In case of doubt, check the transformer with a multimeter. If the voltage in series is very small, invert one of the transformer outputs.



2×15 V transformer secundary connected to the AC to DC board

#### Soldering the footswitches

There is less ground wires out of the connectors than signal wires. Four for the footswitches. Just solder the ground wires to the closest switches and daisy-chain it to the switches nearby.

Footswitches requires some attention, if xPDT are used. First, the contact position is unique per switch (there is no reliable mark on the enclosure). The common pin (for the ground) is on the center, that’s all we know. Check with a multimeter what is the pin shored when the switch is held down.

The footswitch model included in the list is a robust one. However, depending on the model you got, the plastic box may be quite sensitive to heat and could melt easily. If one of the pin just slightly moves during soldering, the contact may be damaged. If it happens on DPDT switches, you can desolder it and try the other path. Always check the contact with a multimeter once both pins are soldered.

When all footswitch wires are soldered, they can be grouped by connector.

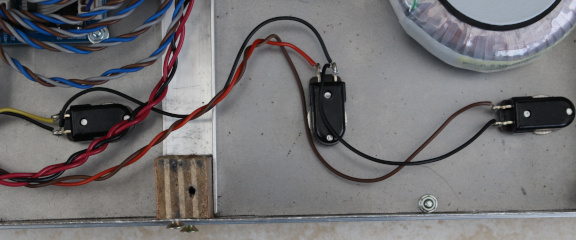
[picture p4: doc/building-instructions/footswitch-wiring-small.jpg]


Connecting the footswitches.

#### Last adjustments and enclosure closing

Add the remaining cables. All of them.



Main board, hyperconnected.
Don’t pay attention to the inversion of the blue and green wires on the audio board connector. There was a mistake in this board version.



Output connectors on the audio board. The balanced output is on the 1–2–3 part.

Personnally, I haven’t included the gain potentiometer and switches for the audio board because I don’t need it at the moment. Instead, I used jumpers to select the microphone level instead of the line level at the XLR input and set the global gain with a simple resistor.



Lazyness wins. No controls for the gains (yet).

For a given input gain, the resistance in ohms is given by the following formula :

R = 2000 / (Glin − 1) = 2000 / (10GdB/20 − 1)

Where Glin is the linear gain and GdB the same gain expressed in decibels. To obtain a unit gain, an infinite resistance is needed, so the Gain pot connectors should be left empty. Practically, it is probably more advised not to go over 10 kΩ to avoid brining too much thermal noise in.

To hold the resistor, crimp its two legs in Dupont female terminals, put them in a box and use it as a jumper.



Resistor in a Dupont box.



Input connectors on the audio board. Mic level is selected with two jumpers, some switch slots have been left empty and a resistor replaces the gain pot on the first input.



Enclosure content is ready. Anyway on this version, the touchscreen wiring is missing.

When everything is ready and the enclosure can be closed, adjust the ground terminal for the bottom plate so it lies just on the plliar screew hole. Put the plate. Insert 40 mm screws in the rubber legs and screw them in the pillars and side stands without forcing. The rubber legs just should stop spinning freely, don’t tighten the screws more. Be careful with the screws (ore more exactly the screw treads in the holes) because it is possible that you will have to open and close the enclosure many times for final adjustments and later, maintenance. Actually I advise not to close the enclosure until the pedalboard is fully operational, and to remove the Pi for software install.



Eight legs for a single enclosure.



Pédale Vite from the back.

During your tests, if you realize that you inverted some footswitches, switches, rotary encoder directions or other things, it is still possible to invert them back. Either on the hardware side by swapping some wires within a connector, either on the software.

Note : The Pi 4 is known to overheat easily. When the load is important, the clock speed is reduced to thermally protect the CPU. However Pédale Vite does not use all the available processing power. The internal temperature stays always below 65 °C, given tests done at a 17 °C ambient temperature and an important load, reaching the stability limit (90 %). One can extrapolate that there is no risk of thermal throttling up to 40 °C. So no additional cooling system (active or passive) is required.

## IV. Software setup

This part is easy but a bit laborious because it requires a lot of manipulations. However most of them can be scripted. I will try later to do it to simplify the task.

### Preparing the system

Minimum recommended version for Raspberry Pi OS is Buster (listed as Legacy) from 2019-09-26. Prefer a 32-bit OS because the 64-bit OS is not tested yet. Whatever OS you pick, make sure it is a Lite version.

#### Bullseye and later

Using the Raspberry Pi Imager (https://www.raspberrypi.com/software/) is preferred in order to customize the system image with a default user account on which you can log on with SSH. Download and install the Imager. Select “Raspberry Pi OS (32-bit)” ad comme Operating System, or “Use custom”. at the very end of the list if you previously downloaded a specific version.

Click on the gear icon (Avanced Options), check Enable SSH while allowing the password mode, check Set username and password and fill both fields just below. Save.

In Choose storage, select the drive where the micro-SD card will be written. Finally, click on Write to start the operation.

#### Buster

Download Raspberry Pi OS (https://www.raspberrypi.com/software/operating-systems/). Unpack somewhere the .img file contained in the archive.

First format the card, if not previously done :

- Go on sdcard.org, Downloads > SD Card Formatter > SD Formatter for Windows Download (my computer runs Windows).
- Accept the license, download the archive, install the program and run it.
- Insert the SD card, click Refresh, select the right drive.
- Click on Options, change “Format size adjustement” to “ON”.
- Click on Format and wait it to finish. It should be quick.

On Windows, download Win32DiskImager (https://sourceforge.net/projects/win32diskimager/) (ImageWriter), install and run it. Select the unpacked Raspbian image (the .img file). Make sure that Device points on the right drive. Click on Write, confirm and wait for the image to be copied on the card.

Then allow SSH accès during the first boot. To do so, go to the partition root named boot and create an empty file (its content doesn’t care) named ssh.

#### Commmon instructions

The system is now ready to be run for the first time. Remove the micro-SD car from the computer and insert it in the Pi socket. This can be tricky if your Pi is already in the enclosure, because the SD-card reader is not accessed easily. In this case, hold the card at the very end of small pliers and introduce it gently below the Pi board.

Plug the Pi to the network and to the power supply if it is not mounted yet.

### Startup and system update

Start up the Pi, wait for the system to load and SSH to run. Normally, the Pi is allocated an IP address with DHCP. Check this address with your network devices. If not possible, you must plug a display and a keyboard before the first start up and use the local terminal.

Log in with the default identifiers (pi / raspberry) or the user specified during installation.

If required, you can set your language and keyboard preferences (optional) :

sudo raspi-config

Select 5. Localisation Options and set your language and keyboard preferences. Finally, hit the left arrow to select Finish. No need to reboot once it is done, we’ll do it a bit later.

Important : from there and until the end of the software setup, the Pi will require an internet access. Make sure it is available.

Now, update the system :

sudo apt-get -y update
sudo apt-get -y dist-upgrade

This will take a while. Sometimes, a information message will block the operation. Scroll down and quit the text viewing program to continue.

We can reboot now :

sudo shutdown -r now

### Basic configuration

Let’s begin with some settings. We’ll need to activate the SPI and I²C interfaces to communicate with our components.

sudo nano /boot/config.txt

Modify the following lines by commenting or uncommenting them, as follows :

dtparam=i2c_arm=on
dtparam=spi=on
#dtparam=audio=on
#dtoverlay=vc4-fkms-v3d

Therefore the default audio device is removed. The last line is written in different locations, make sure to comment them all. Add the following lines in the [all] section at the end :

# Disable rainbow image at boot
disable_splash=1

# Waveshare 4 inch HDMI LCD
hdmi_group=2
hdmi_mode=87
hdmi_timings=480 0 40 10 80 800 0 13 3 32 0 0 0 60 0 32000000 3
disable_overscan=1
framebuffer_priority=2
# Looks like the touchscreen driver uses the SPI interface exclusively
#dtoverlay=ads7846,cs=1,penirq=12,penirq_pull=2,speed=50000,keep_vref_on=0,swapxy=0,pmax=255,xohms=150,xmin=200,xmax=3900,ymin=200,ymax=3900
display_hdmi_rotate=1

# No Bluetooth, no WiFi
dtoverlay=disable-bt
dtoverlay=disable-wifi

Beware, the instruction dtoverlay=ads7846…ymax=3900 fits on a single line. Ctrl+X to save and quit. Then, we ask to load the I2C module during boot :

sudo nano /etc/modules

Add the following lines at the end of the file :

i2c-bcm2708
i2c-dev

Prepare a mounting point for a USB drive :

sudo mkdir /mnt/sda1
sudo chmod 775 /mnt/sda1

### Boot time optimisation

Edit the file :

sudo nano /etc/modprobe.d/raspi-blacklist.conf

Add the following lines to deactivate WiFi and Bluetooth :

#wifi
blacklist brcmfmac
blacklist brcmutil
#bluetooth
blacklist btbcm
blacklist hci_uart

Then type :

sudo apt-get remove -y --purge pi-bluetooth

And we reboot again :

sudo shutdown -r now

### Software dependencies

Install git, Jack2, ALSA and autoconf :

sudo apt-get -y install libjack-jackd2-dev libasound2-dev \
   git autoconf raspberrypi-kernel raspberrypi-kernel-headers

### Clang installation (optional)

It is possible to install a recent version of the Clang compilation suite. This step is optional, but Clang allows a significant speed-up (about +25 %) of the Pédale Vite application, relative to the default GCC compiler. Here, we’re going to install Clang 14.0.6, the latest version at the time of writing, but more recent versions may exist. If so, you can replace the 14.0.6 in the first of the following lines with the newer version identifiers. Anyway you could also keep Clang 14.0.6 which does perfectly the job.

Note : 14.0.6 is the latest version working on Buster. Subsequent versions require a more recent libc6 version which is not available as an update.

Note also that Clang requires about 3 GB on the drive. Make sure you’re not going to run short on space.

clangversion="14.0.6"
cd ~
wget https://github.com/llvm/llvm-project/releases/download/llvmorg-$clangversion/clang+llvm-$clangversion-armv7a-linux-gnueabihf.tar.xz
tar -xvf clang+llvm-$clangversion-armv7a-linux-gnueabihf.tar.xz
rm clang+llvm-$clangversion-armv7a-linux-gnueabihf.tar.xz
mv clang+llvm-$clangversion-armv7a-linux-gnueabihf clang_$clangversion
sudo mv clang_$clangversion /usr/local
echo 'export PATH=/usr/local/clang_'$clangversion'/bin:$PATH' >> .bashrc
echo 'export LD_LIBRARY_PATH=/usr/local/clang_'$clangversion'/lib:$LD_LIBRARY_PATH' >> .bashrc
. .bashrc
clang++ --version

The part beginning with wget and ending with .xz fits on a single line, as well as the second echo line. Theoretically, everything should work well, however I encountered some issues when running executable files using the bundled libc++, which was not found. The following lines will fix the problem :

echo '/usr/local/clang_'$clangversion'/lib/' > ./clang.conf
sudo mv ./clang.conf /etc/ld.so.conf.d/
echo '/usr/local/clang_'$clangversion'/lib/armv7l-unknown-linux-gnueabihf/' > ./libc.conf
sudo mv ./libc.conf /etc/ld.so.conf.d/
sudo ldconfig

It seems that updating libc.conf is only required from Clang 15.

### Installing Pédale Vite

First, download the code in ~/Documents.

cd ~
mkdir Documents
cd Documents
git clone https://github.com/EleonoreMizo/pedalevite.git

Setup the project configuration :

cd pedalevite/build/unix
./autogen.sh
./configure-v2-release

If Clang was installed at the previous step, replace the last line with :

./configure-v2-release CXX='clang++' CC='clang'

Finally (for all versions), compile it :

make -j4

Check that everything succeeded and that there is an executable file pedalevite in the current directory. Then install the software in its dedicated folder, as well as some other files :

sudo mkdir -p /opt/pedalevite/bin
sudo mkdir -p /opt/pedalevite/etc/config
sudo mkdir -p /opt/pedalevite/etc/font
sudo mkdir -p /opt/pedalevite/var/audiodump
sudo cp ./pedalevite /opt/pedalevite/bin/pedalevite
sudo cp ../../bin/cmd_rofs.sh /opt/pedalevite/bin/cmd_rofs.sh
sudo cp ../../etc/font/* /opt/pedalevite/etc/font

The Pi can possibly be connected to all the required cards and peripherals (see the building instructions). Once done, run Pédale Vite for a quick check :

sudo /opt/pedalevite/bin/pedalevite

The program should run normally. Ctrl+C to stop it, or quit it from the user interface menus.

### Pédale Vite autostart

Create this file :

sudo nano /etc/init.d/pedalevite

Modify the file the following way :

#!/bin/sh
# kFreeBSD do not accept scripts as interpreters, using #!/bin/sh and sourcing.
if [ true != "$INIT_D_SCRIPT_SOURCED" ] ; then
    set "$0" "$@"; INIT_D_SCRIPT_SOURCED=true . /lib/init/init-d-script
fi
### BEGIN INIT INFO
# Provides:          pedalevite
# Required-Start:    $local_fs
# Required-Stop:     $local_fs
# Default-Start:     2 3 4 5
# Default-Stop:      0 1 6
# Short-Description: Starts and stops Pedale Vite
# Description:       This service is used to process the sound from a guitar
### END INIT INFO

case "$1" in
    start)
        echo "Mounting Pedale Vite directory as R/W..."
	mount --bind /opt/pedalevite/ /opt/pedalevite/
	mount -o remount,rw /opt/pedalevite/
        echo "Starting Pedale Vite..."
        /opt/pedalevite/bin/pedalevite &
        echo -n performance | sudo tee /sys/devices/system/cpu/cpu0/cpufreq/scaling_governor > /dev/null
        echo -1 | sudo tee /proc/sys/kernel/sched_rt_runtime_us > /dev/null
        systemctl stop getty@tty1.service
        ;;
    stop)
        echo "Stopping Pedale Vite..."
        killall pedalevite
        umount /opt/pedalevite/
        ;;
    *)
        echo "Usage: /etc/init.d/pedalevite start|stop"
        exit 1
        ;;
esac

exit 0

Then :

sudo chmod +x /etc/init.d/pedalevite
sudo update-rc.d pedalevite defaults

Pédale Vite will run automatically at the next reboot. It can be run immediately, too :

sudo /etc/init.d/pedalevite start

### Read-only operating system and other optimisations

This part should be done with care in order not to let the system enter an inconsistent state.

#### Script to enable the write mode back

First, add a little helper script to switch the filesystem back in read-write mode. You will need to manually execute this script each time you need to update something, compile or any other operation requiring disk write.

cd ~
nano fs-rw.sh

Add to this new file :

#!/bin/sh
sudo mount -o remount,rw /
sudo mount -o remount,rw /boot

Give it the execution permissions :

chmod +x ./fs-rw.sh

#### Main course

Let’s remove tasks that are not required nor adapted to read-only operations :

sudo apt-get remove -y --purge triggerhappy logrotate dphys-swapfile fake-hwclock
sudo apt-get -y autoremove --purge

Replace log management with busybox (use logread if needed) :

sudo apt-get -y install busybox-syslogd
sudo dpkg --purge rsyslog

Edit the boot parameters :

sudo nano /boot/cmdline.txt

Add fsck.mode=skip ro logo.nologo at the very end of the line :

dwc_otg.lpm_enable=0 console=serial0,115200 console=tty1 root=/dev/mmcblk0p2 rootfstype=ext4 elevator=deadline fsck.repair=yes rootwait fsck.mode=skip ro logo.nologo

Replace some var subfolders with symbolic links on the RAM-disk :

sudo rm -rf /var/spool
sudo ln -s /tmp /var/spool
sudo rm -rf /var/lib/lightdm /var/cache/lightdm
sudo ln -s /tmp /var/lib/lightdm
sudo ln -s /tmp /var/cache/lightdm

Edit var.conf :

sudo nano /usr/lib/tmpfiles.d/var.conf

Replace the spool permission 0755 with 1777 :

d /var/spool 1777 - - -

Move dhcpd.resolv.conf to tmpfs :

sudo touch /tmp/dhcpcd.resolv.conf
sudo rm /etc/resolv.conf
sudo ln -s /tmp/dhcpcd.resolv.conf /etc/resolv.conf

Edit fstab :

sudo nano /etc/fstab

Add ,ro after the defaults for the disk patitions :

proc            /proc           proc    defaults             0       0
/dev/mmcblk0p1  /boot           vfat    defaults,ro          0       2
/dev/mmcblk0p2  /               ext4    defaults,ro,noatime  0       1

These lines may also start with PARTUUID=. Also add the lines :

tmpfs           /tmp            tmpfs   nosuid,nodev         0       0
tmpfs           /var/lib/systemd/timesync tmpfs   nosuid,nodev         0       0
tmpfs           /var/log        tmpfs   nosuid,nodev         0       0
tmpfs           /var/tmp        tmpfs   nosuid,nodev         0       0

Edit rc.local :

sudo nano /etc/rc.local

Add the chmod before the exit 0 :

  printf "My IP address is %s\n" "$_IP"
fi

chmod g+w,o+w /tmp
exit 0

Prevent the automatic system updates :

sudo systemctl disable apt-daily.timer
sudo systemctl disable apt-daily-upgrade.timer
sudo systemctl disable man-db.timer

Optional : to automatically switch to read-only mode when logging off, edit or create the bash.bash_logout file :

sudo nano /etc/bash.bash_logout

Add the following lines at the end :

mount -o remount,ro /
mount -o remount,ro /boot

Reboot. Pédale Vite is now functional.

At this point, it is recommended to check if the system date is updated correctly when connected to the internet. If it isn’t, check the troubleshooting section.

#### A few handy scripts

Optional. Watch out for the linebreaks.

cd ~
echo '#!/bin/sh'$'\n\n''sudo mount -o remount,rw /'$'\n''sudo mount -o remount,rw /boot' > fs-rw.sh ; chmod +x fs-rw.sh
echo '#!/bin/sh'$'\n\n''sudo timedatectl set-ntp 1' > updatedate.sh ; chmod +x updatedate.sh
cd ~/Documents/pedalevite/build/unix
echo '#!/bin/sh'$'\n\n''sudo cp /opt/pedalevite/etc/config/current /opt/pedalevite/etc/config/current.bak-`date --utc +%Y-%m-%d-%H%M`' > backup-config.sh ; chmod +x backup-config.sh
echo '#!/bin/sh'$'\n\n''sudo jackd -P70 -p16 -t2000 -dalsa -p64 -n3 -r44100 -s &' > run-jack.sh ; chmod +x run-jack.sh
echo '#!/bin/sh'$'\n\n''sudo mount -t vfat /dev/sda1 /mnt/sda1' > usb-mount.sh ; chmod +x usb-mount.sh
echo '#!/bin/sh'$'\n\n''sudo umount /mnt/sda1' > usb-umount.sh ; chmod +x usb-umount.sh

## V. Maintenance

### Tests and troubleshooting

To do…

#### Known issues

##### Network not available

For some reason, the system cannot connect to the network during startup. Generally, rebooting is enough to fix this issue.

##### Pédale Vite program refuses to start again after a crash

When Pédale Vite starts, it creates a temporary file indicating that an instance of the program is already running, preventing other instances to run concurrently. This file is deleted when Pédale Vite stops, normally or with Ctrl + C. However the file is not deleted in case of a crash, and Pédale Vite immediately terminates, displaying :

Pedale Vite is already running!

Just manually delete the file :

sudo rm /var/lock/pedalevite-unique

##### The RPi4 EEPROM update fails during startup

This issue could occuring during the startups following a system update. The cause is the read-only mode of the filesystem. To fix it, just set the filesystem in read-write mode and force the EEPROM update :

sudo mount -o remount,ro /
sudo mount -o remount,ro /boot
sudo systemctl restart rpi-eeprom-update.service

One can check everything worked fine :

sudo systemctl status rpi-eeprom-update.service

##### When connected to the Internet, the date is not updated even if timesyncd is active

Sometimes the timesyncd services cannot synchronise to NTP servers. Check with :

timedatectl status

NTP service shoud be active but System clock synchronized may be set to no. In this case, check :

timedatectl timesync-status

Reports :

       Server: (null) (3.debian.pool.ntp.org)
Poll interval: 0 (min: 32s; max 34min 8s)
 Packet count: 0

This may be an issue with the DNS server, which does not resolve the NTP servers for some reason. Try by setting explicitely the DNS :

sudo mount -o remount,rw /
sudo rm /etc/resolv.conf
sudo nano /etc/resolv.conf

Add the following lines (you can put here any working DNS server address) :

domain home
nameserver 1.1.1.1
nameserver 1.0.0.1

Reboot or restart the services.

##### The audio clicks or channels are swapped very frequently

This is likely a scheduling issue with real-time threads. Type the following commands and check the results :

cat /proc/sys/kernel/sched_rt_period_us
cat /proc/sys/kernel/sched_rt_runtime_us

The runtime value should be equal to the period, or -1. If this is not the case, type the following :

echo -1 | sudo tee /proc/sys/kernel/sched_rt_runtime_us > /dev/null

### Source code

Despite the hardware being important in Pédale Vite, this is primarily a software project. This part describes briefly the program architecture and what is required to know to adapt it easily to hardware modifications. To update the code from the Git repository :

cd ~/Documents/pedalevite
git pull

Don’t forget beforehand to set the filesystem as read-write :

~/fs-rw.sh

#### Compiling

The software is written in C++. The compiler should support at least C++14. Project files are located in the pedalevite/build folder.

##### Linux

The unix subfolder contains what is required to to compile on the Pi and for the Pi. Makefile.am is the file to be modified to add source files. configure-v2-debug and configure-v2-release define the compilation configuration. Running make -j4 compiles the project. See also the software part from the building instructions.

##### Windows

win contains the projects for Visual Studio 2013. Source code is organized according to seveal categories :

- mfxlib groups most of the source files as a static library. This is an entity shared between other projects.
- pedalevite is the program emulating a pedal board requiring nn ASIO sound card, the keyboard and the display. This program is by far the easiest way to modify and test Pédale Vite software.
- test contains some unitary tests for classes or miscellaneous functionalities.

These three projects are bundled into the pedalevite.sln solution.

If your computer’s soundcard does not support navite ASIO drivers, it’s possible run it with ASIO4ALL. By default, the Pédale Vite input channels are number 3 and 4 (these are the instrument inputs for my card). You may have to change them by setting the chn_idx_in value, near the end of pedalevite/src/main.cpp :

#elif (MAIN_API == MAIN_API_ASIO)
	mfx::adrv::DAsio  snd_drv;
	chn_idx_in = 2;
#else

The emulation uses the following keys :

A Z E R T Y or Q W E R T Y | Pedals 0 to 5, upper row
Q S D F G H or A S D F G H | Pedals 6 to 11, lower row
0 1 2… 8 9 on the numeric keypad | Several values for the expression pedal #0
1 2, 3 4, … …, 9 0 | −1 and +1 from the 5 generic incremental encoders
W X C or Z X C et V B N | −1, +1 and button for the 2 incremental encoders used for navigation
Return | Select from the user interface
Esc | Esc from the user interface
Arrows | Arrows from the user interface

#### Architecture

##### Threads

The program uses 3 main threads :

- The audio thread, processing audio inputs and outputs and computes what to do with the former to produce the latter.
- The main thread, collecting control inputs and produce the data to be displayed. It handles interactions from the user interface and controls the audio thread.
- Finally, one or several (depending on the platform) I/O threads. They poll the input ports and redirect the display data to the right devices.

Thread are communicating with a lock-free queue. Most of these information are centralized by the main thread. However, there are some direct communications between the input thread and the audio thread, in order to maximise the audio processing reactivity to external stimulis.

##### MVC paradigm

The architecture follows the MVC paradigm (mfx::Model model drives a low-level layer to command the mfx::cmd::Central audio engine. There, data are perpared (always in the main thread) and transactionnally sent to the audio thread, mainly located in mfx::WorldAudio.

The document structure (banks, programs, settings…) is described in mfx::doc. The etc/config/current save file is directly generated and read by the serialising interface.

The audio drivers are located in mfx::adrv. The main part of the platform-specific code is located in mfx::hw. Switch polarty, order, GPIO pin numbers, speed of the communication protocols and all other hardware details can be changed in these classes.

The user interface is made of pages in mfx::uitk::pg. They are activated depending on the user navigation. They are registered as views and act as controllers, in the MVC meaning. They use a rudimentary system of GUI tree implemented in mfx::uitk, allowing placing controls, receiving user events and navigating easily through these elements.

Effects are organized in mfx::pi in a plug-in logic, despite not being deployed as such. The common interface is in mfx::piapi. Each effect is actually made of two processors : the actual effect plug-in and a mixer plug-in implementing bypass, volume and dry/wet mix.

All these piece are put together in pedalevite/src/mfx/main.cpp which still has a rough state. Most of the program parameters is located in mfx::Cst.

There is so much to talk about the code architecture and implementation details, it’s an endless job. This section might be expanded later.

#### File tree

The file tree in pedalevite/src follows more or less closely the namespace tree. The classes are implemented in files having their names, as they does in Java. Please note the following namespaces :

- fstb is a kind of generic toolbox. It provides basic functions and tools. Particularly, there is a wrapper on 128-bit SIMD instruction sets for SSE/SSE2 and NEON to write portable code without hassle.
- conc provides lock-free primitives.
- mfx::dsp contains several audio DSP classes (filtering, mixing, delay lines…) This library is intensely used by the effects.

pedalevite/etc/config contains the pedalboard user configurations (mainly current). This folder is copied in the install location /opt/pedalevite on the Pi and used in-situ by the Windows emulator.

## VI. Possible improvements and variations

For people afraid by the complexity or the price, there are a lot of ways to cut down the price or simplify the building. Here are a few topics I could imagine.

#### External USB audio interface

There would be some advantages to put the audio interface out of the perdalboard :

- Reduce cost by removing the internal audio board and wiring.
- Building is simplified for the same reasons.
- Direct access to the audiobox front panel for calibration.
- Allows changing the audio interface model without taking into account geometrical constraints.

For the cons :

- More parts to carry around and to plug.
- Even more complex to plug if we replace the USB powering by our own power supply.
- Software configuration must be changed to use the ALSA drivers.

#### Simplification of the internal audio board

It is possible to get rid of the mic preamps if they aren’t needed at all. It is even possible to get rid of the second input channel. This reduce significantly the amount of components on the board.

#### Cheaper parts

Price can be optimized by choosing cheaper part suppliers. It requires spending more time and energy comparing prices and part specifications.

For example the audio connectors could use cheaper TR jacks instead of Neutrik jack-XLR combos and TRS jacks.

However I think it would be clumsy to try to save on the footwitches. Robustness of these parts is essential.

#### Rotary encoder removal

In the current configuration, I use them not as often as I imagined it. I think we can do without them. This is less connections and less costs.

#### Pull-up resistors

The RPi and the 23017 port expander have internal pull-up resistors. One can use them instead of all the 10 kΩ external resistors and remove the associated filtering capacitors too. This will be less clean on an electrical point of view, but it should do the job. The code to change to activate these internal resistors is negligible. Debouncing is already doubled in software and this shouldn’t require any change.

Cost cut is small but building simplification is significant.

#### Reducing the number of connectors

Most of the links between the boards and the main parts are done with cables and connectors at both ends. One can remove some of the connectors and just solder the wires. However I discourage soldering the cables at both ends, this would make control and maintenance more complicated.

Secondly, because a lot of wires follow the same way, it is possible to cut pieces of a ribbon cable. A meter (or slightly more) of 40-wire multicoloured ribbon should be enough for the whole pedalboard. Be careful with the wires which may be a bit too thin for the Dupont connectors, they probably should be replaced with more suitable connectors.

## VII. Version history

r13, 2023-04-29

- Replaced the wiringPi library with a custom implementation.

r12, 2023-02-11

- Updated RPiOS installation instructions (Bullseye support).

r11, 2022-11-15

- Notes about OS and Clang versions.

r10, 2022-05-24

- Changed the configure options to compile with Clang.

r9, 2021-03-26

- More troubleshooting with the time slices allocated to real-time threads.

r8, 2020-10-02

- More troubleshooting.
- Updated Clang installation to v11.0.0

r7, 2020-03-03

- Updated the setup of the read-only filesystem.

r6, 2020-01-16

- Added the creation of a few subdirectories for software installation.

r5, 2019-12-20

- Possibility of using Clang to compile Pédale Vite.

r4, 2019-11-09

- Fixed date synchronisation issues when setting the filesystem access in read-only.

r3, 2019-11-07

- Updated the autostart script to set the /opt/pedalevite subdirectory in R/W mode.

r2, 2019-11-02

- Pédale Vite is upgraded to version 2.

r1, 2017-09-24

- Document translation in English.

r0, 2016-12-31

- Document creation (in French).

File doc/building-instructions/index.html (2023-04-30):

# Pédale Vite v2 — Instructions de montage

## Table des matières

1. Introduction
2. Fournitures
  1. Plans
  2. Matériaux
  3. Outillage
3. Montage pas à pas
  1. Boîtier
  2. Électronique
  3. Assemblage
4. Installation logicielle
  1. Préparation du système
  2. Démarrage et mise à jour système
  3. Configuration de base
  4. Optimisation du temps de démarrage
  5. Installation des dépendances logicielles
  6. Installation de Clang (facultatif)
  7. Installation de Pédale Vite
  8. Démarrage automatique de Pédale Vite
  9. Passage du système en lecture seule et autres optimisations
5. Maintenance
  1. Tests et dépannage
  2. Code source
6. Amérliorations et variations envisageables
7. Historique des versions

## I. Introduction

Pédale Vite est une pédalier multi-effet pour guitare à fabriquer soi-même (DIY, do it yourself). Ce manuel détaille comment réaliser le montage et installer toutes les composantes nécessaires à son fonctionnement.

Ce projet est relativement complexe et modérément difficile, mais à la portée de tout le monde. Il n’est pas nécessaire d’avoir le bricolage dans le sang. Il ne nécessite pas d’adresse ou de compétence particulière. Les techniques utilisées (soudure, perçage, etc.) ne s’improvisent pas mais s’apprennent relativement rapidement.

Cependant la réalisation est relativement prenante et nécessite une dizaine de jours de travail environ. C’est approximativement le temps que j’ai passé au montage. Je suis loin d’être très organisé et encore moins adroit de mes dix doigts. Je suis sûr qu’une personne un peu bricoleuse peut réduire ce temps de moitié.

Il est préférable de lire les instructions dans leur intégralité avant de commencer, afin de se faire une idée plus précises des opérations et de leur ordre. Il n’y a pas beaucoup d’illustrations des étapes intermédiaires du montage, mais celles illustrant le pédalier (presque) fini devraient suffir à se faire une idée plus précise des placements et de la logique d’assemblage.

## II. Fournitures

Les fichiers nécessaires se trouvent dans le dépôt GitHub (https://github.com/EleonoreMizo/pedalevite/) du projet.

- Les schémas en .pro s’ouvrent avec KiCAD (http://kicad-pcb.org/), utilisé ici en version 6.0.2.
- Les dessins en .dfx s’ouvrent avec LibreCAD (http://librecad.org/), utilisé ici en version 2.2.0.
- Les feuilles de calcul .ods s’ouvrent avec LibreOffice (https://www.libreoffice.org/) ou OpenOffice (https://www.openoffice.org/).

Certains documents ont été exportés en .png ou .pdf pour un accès plus simple.

### Plans

Les plans se trouvent dans le répertoire doc (https://github.com/EleonoreMizo/pedalevite/tree/master/doc) du dépôt.

- Le dossier boards contient les schémas électroniques (KiCAD) ainsi que les plans des ciruits imprimés des différentes cartes.
- drawing-panel.dxf donne le plan de perçage des feuilles métalliques composant le boîtier.
- cables.ods fournit le plan de câblage. Chaque paire de lettre indique les broches à relier ensemble au moyen d’un fil électrique.

Ces plans ne sont pas exhaustifs. Par exemple, je n’ai pas encore fait figurer les câbles reliant le Pi à son alimentation, ou les câbles secteur. Toutefois ce sont des parties relativement simples qui ne nécessitent pas d’instruction détaillées.

### Matériaux

La liste des matériaux utilisésse trouve dans le fichier doc/bom.ods du dépôt. Les composants sont décrits en fonction de leurs contraintes physiques et qualitatives, assortis des d’un prix hors taxes indicatif. D’ailleurs, en terme de prix, il est possible d’optimiser un certain nombre de choses. Certaines pièces sont issues de mes stocks venant de projets précédents et peuvent avoir été achetées par lots surnuméraires. En cherchant, on peut trouver des lots en quantités plus adéquates. Il est tout à fait possible de prendre d’autres matériaux, pourvu qu’ils soient compatibles ou adaptables.

Pour information, les résistances utilisées sont toutes des ¼ W de 6,2 mm de long au maximum, essentiellement pour des raisons d’encombrement sur le circuit.

### Outillage

- Crayon à papier ou mieux, porte-mine pour pouvoir tracer à travers un trou de plaque
- Compas de précision ou forme permettant de tracer des cercles de 10, 11, 12 et 24 mm de diamètre si on utilise une fraise conique sans étage
- Réglet gradué
- Rapporteur
- Ciseau à bois
- Scie à bois
- Scie à métaux
- Lime à métaux, plate
- Lime à métaux à section arrondie (« queue de rat ») et aussi fine que possible (3–5 mm)
- Établi
- Paire de serre-joints
- Planches jetables (récupération de palette) pour support de perçage, guides, etc.
- Perceuse, si possible sur colonne
- Mèche bois 2 mm
- Mèches, cloches ou fraises coniques pour percer du 3, 4, 5, 7, 10, 11, 12 et 24 mm de diamètre dans de l’acier
- Pointeau ou vis pointue
- Mini-perceuse type Dremel
- Disques de tronçonnage pour acier (si possible plusieurs, petits et grands diamètres)
- Huile de coupe
- Jeu de clés plates ou éventuellement à pipe : 5, 5.5, 6, 10, 13 et 14 mm
- Tournevis plat
- Tournevis cruciforme ordinaire (PH2 et possiblement PH1)
- Marteau
- Fer à souder thermorégulé avec porte-fer (50 W mini)
- Fil de soudure 0.5 mm et 1 mm avec flux
- Pompe à soudure et éventuellement de la tresse à déssouder
- Troisième main
- Étau
- Éponge dédiée au nettoyage du fer
- Pinces à bec fin
- Pinces brucelles
- Pinces à couper les pattes de composants (pinces coupantes ordinaires O.K. mais moins pratiques)
- Pinces à sertir les petites cosses (les PA-09 (http://www.engineer.jp/en/products/pa09e.html) de chez Engineer sont très bien)
- Pinces à sertir les cosses Faston 250
- Outil à dénuder de petit calibre
- Ruban adhésif isolant (« Scotch d’électricien »)
- Gants
- Lunettes de protection contre les projections
- Masque respiratoire contre la poussière
- Multimètre (mesure de résistance ou de contact)
- Oscilloscope (facultatif mais pratique)
- Markers pas trop gros clairs et foncés ou tubes de peinture avec pinceau fin

Cette liste n’est pas complètement exhaustive, n’y figurent pas tous les petits outils ou matériaux pouvant servir de leviers, cales ou de martyrs durant le montage. Ils peuvent être improvisés sur place en fonction de ce dont vous disposez et de vos habitudes ou techniques de bricolage. L’outillage à lui seul peut revenir assez cher. N’hésitez pas à vous faire prêter le matériel, ou à faire des achats collectif.

## III. Montage pas à pas

### Boîtier

#### Usinage

En premier lieu, protégez-vous le visage, les yeux et les mains avec les lunettes et les gants. Le masque sert aussi à se protéger contre l’inhalation des poussières. Si possible, portez des vêtements couvrants.

Découper la plaque de métal avec la scie à métaux ou avec un disque de tronçonnage monté sur la mini-perceuse. Dans ce dernier cas, utiliser une planche comme guide pour appuyer l’axe de l’outil afin de couper aussi droit que possible. Asperger la ligne de coupe d’huile de coupe afin d’éviter les échauffements et d’économiser les disques de tronçonnage.

Les plaques sont à découper aux dimensions suivantes :

- Façade (dessus) : 520 × 250 mm²
- Face arrière : 520 × 70 mm²
- Face avant : 520 × 30 mm²
- Dessous : 520 × 253 mm²
- Côtés: [30–70]×250mm² (trapèze rectangle)

Note : la face avant et le dessous peuvent être en aluminium car elles nécessitent moins de robustesse.

Une fois les panneaux coupés aux bonnes dimensions, ébavurer avec une lime de façon à arrondir les bords dans le sens de l’épaisseur.

Important : toutes les opérations se font sur la face intérieur de chaque panneau. Les plans sont tous des vues de l’intérieur.

Tracer ensuite les repères des perçages et découpes en fonction des plans. Tracer le contour des trous à percer à la fraise conique à l’aide d’un compas. Marquer le centre des trous avec un pointeau ou une vis bien pointue. Procéder ensuite au perçage. Pour les trous les plus gros, il peut être intéressant de faire un avant-trou afin de bien guider la mèche ou la fraise. Utiliser l’huile de coupe. Avec la fraise conique, arrêter la découpe quand on dépasse les contours tracés. Se munir de la pièce à faire rentrer dans le trou et essayer. Remettre un coup de fraise si c’est trop juste, ou limer.

Une fois les plus gros trous faits, ébavurer avec une fraise spéciale ou utiliser la mini-perceuse avec un disque de tronçonnage pour découper le métal qui dépasse.

Découper deux morceaux de 520 mm dans la cornière. Ils viendront faire la jonction aux angles supérieurs du boîtier. La partie la plus courte du L sera sur le dessus et la plus longue verticale. Si nécessaire, ronger la partie supérieure d’une des cornières avec la queue de rat afin de laisser la place pour les deux vis de l’écran.



De la place pour les vis. En fait ce n’était pas vraiment nécessaire.

Découper deux autres morceaux de cornière de 250 mm qui serviront de renforts dans le sens de la profondeur. Une des cornière est enjambée par la carte son. Veiller à ce que celle-ci ne rentre pas en contact une fois en place. Il sera peut-être nécessaire de découper un morceau ; utiliser pour cela une lime si la quantité de matière à retirer est peu importante, sinon un disque de tronçonnage.

Serrer ensemble ces deux cornières de renfort avec la plaque. Percer d’un coup les trous traversant les deux.

Percer les trous restants à la perceuse et ébavurer au besoin. Sur le schéma, les petits trous sans diamètre indiqué font 3 mm de diamètre. Certains trous de fixation dépendent du matériel précis dont vous disposez : connecteurs, prise et interrupteur secteur, etc. Vérifiez que les trous donnés sont cohérent avec vos matéraux, ajustez-les le cas échéant.

Les trous des LED sont calibrés à 5 mm. Il est possible de les agrandir un peu à 6 mm tout en les descendant d’un demi-millimètre. Cela permet de descendre la LED à la surface du boîtier tout en la rendant rendant visible même sous incidence élevée.



Mes trous de LED vont encore plus loin et sont légèrement ovales.

Nota bene: les trous pour fixer les montants latéraux et les piliers sont légèrement décalés aux angles afin que les vis puissent se croiser plutôt que se rentrer dedans. Les trous en bas des piliers sont clairement excentrés.



Vis non-alignées, face avant.

Il peut être plus pratique de laisser de côté les trous qui traverseront les cornière longitudinales. Ils seront percés une fois les cornière placés sur le montage.

Découper les zones rectangulaires. Il peut être plus pratique de commencer par percer les coins avec une mèche de 3 mm, à 1,5 mm de chaque coin. Cette étape facilite la jonction des découpes. Couper les bords avec un disque de tronçonnage de petit diamètre. Enfin, limer les bords pour les arrondir et remettre les angles au carré.

#### Supports latéraux

Prendre une planche de 18 mm d’épaisseur, 20 mm tout au plus. Découper deux formes en trapèze rectangle de 250 mm de long et de largeurs 30 et 70 mm. On peut vérifier que le dernier bord fait bien 253 mm. Les angles droits sont sur le dessus du pédalier.

À l’aide d’une scie et de ciseaux à bois, découper sur les montants les trous pour faire passer les connecteurs du Pi ainsi que les contrôles de gain de la carte son. Se référer aux plans pour les placements, layer Structure.



Ouverture pour laisser passer les connecteurs du Pi.

Percer ensuite les plaques métalliques latérales, positionnées côté intérieur, et les visser.

Visser sur les deux formes latérales les panneaux du dessus, avant et arrière. Utiliser des vis à bois de 3 mm, pas trop longues. Elles peuvent être auto-perforantes ou simples. Dans ce cas, il vaut mieux prépercer les trous avec une mèche de 2 mm. Placer la plaque sur les montants afin de repérer précisément les-dits trous.

Placer les deux cornières longitudinales aux angles, et bien les plaquer avec des serre-joint. Percer les trous traversant les cornières, les plaque et le bois avec une mèche de 2 mm. Repasser sur le métal uniquement avec une mèche de 3.

Il est possible de percer tous les trous des cornières, même ceux qui tiendront les piliers centraux. Ajouter les dernières vis des montants, ainsi que de courtes vis (8 à 10 mm) avec écrou et rondelle pour attacher la plaque du dessus aux cornières.

#### Piliers centraux

Les piliers centraux vont servir d’appui aux deux renforts fabriqués à partir des cornières. Commencer par visser ces derniers à la plaque du dessus si ce n’est pas encore fait. Découper ensuite des piliers de 18 à 20 mm de section carrée dans du bois solide. On peut pafaitement reprendre des chutes de la planche ayant servi aux supports latéraux.

La forme verticale des piliers (vus de côté) est légèrement trapézoidale. La forme biseautée (9°) se trouve du côté du sol, la différence de longueur entre les deux faces est d’environ 3 mm.

Couper deux piliers de 30 et 33 mm pour la face avant, et deux piliers de 67 et 70 mm pour la face arrière. Déduire de ces longueurs l’épaisseur de la cornière, de façon à ce que les montants et les piliers arrivent au même niveau. D’un autre côté, ne pas hésiter à allonger d’un demi-millimètre cette longueur, quitte à la réajuster à la rappe plus tard, en situation.

Placer chaque pilier sur le montage, percer le trou dans le bois et visser. Poser ensuite à plat le montage et vérifier qu’il n’est pas bancal. Limer au besoin les pieds un peu trop longs.

Ensuite, l’épreuve du feu : poser le boîtier au sol et monter dessus. Il ne doit pas se déformer ou donner des signes de faiblesse.

### Électronique

#### Les cartes

Les cartes principale, carte audio et convertisseur 2 × 15 V sont des PCB que vous pouvez faire fabriquer à l’aide des fichiers Gerber situés dans les sous-répertoires de doc/boards. Il est aussi possible de récupérer des restes de mes plaques à prix coûtant, me contacter directement si vous êtes intéressé·e.

Pour les autres cartes, découper les rectangles suivants dans la plaque de prototypage :

- 19 × 18 trous entiers, soit 48,3 × 45,7 mm², carte de l’alimentation 5 V
- 20 × 13 trous entiers, soit 50,8 × 33,0 mm², carte des boutons de navigation
- 18 × 4 trous entiers, soit 45,7 × 10,1 mm², carte des diodes
- 18 × 4 trous entiers, soit 45,7 × 10,1 mm², carte des codeurs incrémentaux de navigation
- 48 × 3 trous entiers, soit 121,9 × 7,6 mm², carte des codeurs incrémentaux de paramètres

Les plaque de prototypage standard font 61 trous sur 38. Il est donc possible d’extraire toutes les cartes d’une seule plaque. On peut prendre des plaques à bandes ou à pastilles, ces dernières étant probablement plus pratiques pour les circuits à réaliser.

On peut utiliser une simple scie à métaux, qui fait très bien l’affaire. Immobiliser la plaque sur un établi avec un étau ou un serre-joint, en la coinçant entre deux planchettes de bois pour ne pas l’abîmer. La découpe se fera au milieu d’une rangée de pastilles, pour profiter des trous existants.

Percer des trous de fixation aux endroits indiqués sur le fichier de PCB (doc/boards/misc-boards/misc-boards.kicad_pcb) à l’aide d’une mèche de 3 mm. Sans perceuse à colonne, il est préférable de percer au centre d’une pastille, là ou le petit trou fait office de guide. Chaque trou sera fait au milieu d’un carré de 3 × 3 pastilles, sur lesquelles aucun câblage ne pourra être fait.

Après le découpage de la carte des LED, il faut fabriquer le support avant de souder les composants. Voir plus bas.

Il est aussi possible de faire graver ces cartes sous forme de PCB en extrayant et exportant les PCB « secondaires » de doc/boards/main-board. Toutefois ces cartes sont très simples et je ne pense pas qu’il soit intéressant de les faire fabriquer.

#### Soudure des PCB

##### Carte principale

Souder les composants par ordre de hauteur. D’abord les résistances à plat, puis tous les condensateurs céramique situés hors des supports à circuits intégrés.

Vérifier ensuite que les supports et les condensateurs internes peuvent cohabiter sans problème. Le cas échéant, raboter à la lime le plastique des supports afin que tout rentre correctement sans forcer. Il est possible d’incliner les condensateurs ou de les déporter légèrement, jusqu’à une certaine limite.

Souder ensuite les supports, puis les condensateurs internes. Ensuite les résistances verticales, puis les transistors. Viennent enfin les connecteurs HE10, Dupont et NSK254.

Ne posez pas tout de suite les puces dans leur support, il y des vérifications à faire avant, voir plus bas.

##### Carte audio

Cette carte demande une certaine attention. En effet, il y a deux composants montés en surface (CMS), le codec CS4272 et l’horloge MK2703. Le CS4272 est particulièrement délicat puisqu’il s’agit d’un boîtier TSSOP, aux pattes très fines (0,63 mm de pas). Ces deux composants sont à souder en premier. Il vous faudra du fil à soudure fin (0,5 mm), et en fonction de votre acuité visuelle, peut-être une loupe ou un microscope. Un très bon éclairage est nécessaire dans tous les cas.

Il existe diverses techniques de soudure de ce type de composant, impliquant généralement de commencer par souder deux pattes pour immobiliser la pièce, puis de souder le reste. Il existe de nombreux guides en photo ou vidéo pour la soudure manuelle de puces CMS. La technique par innondation de soudure marche relativement bien, mais demande un minimum de pratique pour être propre et efficace. N’hésitez pas à vous entraîner au préalable sur des plaques-adaptateurs avec des puces bon marché qui pourront être sacrifiées sans regret. Sinon revenez à la technique la plus simple, patte par patte. Le plus gros risque est de faire couler de la soudure sous la puce, derrière les pattes et de les court-circuiter sans qu’il ne soit possible de revenir en arrière. En cas de problème, il est quasiment impossible de déssouder la puce sans l’endommager (mécaniquement ou thermiquement) et de recommencer, sauf si vous disposez d’un pistolet à air chaud adapté.

Si vous ne vous sentez pas suffisamment en confiance pour l’opération, confiez-la à une personne expérimentée ou professionnelle. Toutefois, ce n’est pas si difficile, cette carte fut ma première expérience de soudure de puce TSSOP et elle fonctionne très bien.



La carte audio complètement montée et branchée.

Après avoir soudé les puces CMS, on soude les composants dans leur ordre de hauteur : les petites diodes type 1N4448, les résistances, les diodes plus grosses type Schottky, les condensateurs céramique, les supports de circuits intégrés, les condensateurs film, les connecteurs Dupont et supports tulipe pour transistors et régulateurs, les selfs, la ferrite, et finalement sans ordre prédéfini, les condensateurs électrolytiques, le régulateur 5 V, le connecteur NSK254 de l’alimentation.

Placez le quartz dans cette liste en fonction de sa taille, mais avant de souder celui-ci, assurez-vous qu’il y a un espace entre le composant et le PCB. Vous pouvez intercaler un morceau de carton pour assurer l’écart et le retirer une fois la soudure effectuée. Attention à ne pas le faire trop chauffer, il pourrait brûler.

Les transistors Q1–Q3, la référence de tension D9 et le régulateur IC4 sont montés sur support tulipe plutôt que soudés directement.

Positionner les self de façon à ce qu’elles soient à moitié debout, l’une en face de l’autre pour chaque canal d’entrée, formant un angle droit.

Une fois que tout est soudé, fixer le radiateur sur IC3.

Enfin, insérer un cavalier sur JP1 pour sélectionner le bit de poids faible de l’adresse I²C de la carte. Le mettre entre les broches 2 et 3 pour l’adresse 0, attendue par la partie logicielle.



Sélection de l’adresse I²C avec JP1.

Comme pour la carte principale, ne pas placer tout de suite les puces dans leur support.

##### Carte de conversion 15 V alternatifs vers continu

Pas grand-chose à dire sur cette carte qui alimente la partie analogique de la carte son. Ne pas oublier de fixer les radiateurs sur les régulateurs de tension. Les self L1 et L2 sont à incliner de façon à ce qu’elles forment un angle à 90°.



Redressement des ±15 V. Ne pas prêter attention aux diodes du pont qui ne sont pas du modèle indiqué sur la liste.

#### Soudure des plaques de prototypage

Pour toutes les cartes : côté composants, commencer par placer sans les souder les principaux composants à l’aide du schéma PCB. En marquer le tour au crayon à papier. On obtient ainsi des repères pour les placements.

##### Création des pistes

Pour connecter les composants entre eux sur une plaque à pastilles, il peut être nécessaire de créer des pistes, côté cuivre. Ces pistes apparaissent sur les schémas en vert (calque B.Cu, back copper layer dans KiCAD/Pcbnew). Pour m’aider, j’ai pris une capture d’écran du schéma de montage, qu’on voit habituellement côté composants. Avec un éditeur d’images, je l’ai retournée en miroir dans le sens horizontal afin d’avoir le plan de câblage dans le bon sens.

Pour créer la piste, on peut utiliser des ponts avec de la soudure, ou prendre du fil de cuivre nu. Dans ce cas utiliser plutôt du fil monobrin, préférablement étamé, ce sera plus facile. On peut aussi réutiliser des chutes de pattes de composants, ce qui est sûrement la solution la plus judicieuse ici.

Avec du fil monobrin, dérouler un peu de câble. Tirer dessus avec une pince d’une main et la bobine dans l’autre main jusqu’à ce qu’une légère élongation se fasse sentir ; arrêter immédiatement pour éviter de rompre le fil. Il devrait alors être bien droit. En couper un peu plus que la longueur désirée.

Pour le poser le fil de piste, partir de la pastille libre la plus proche, faisant partie du trajet. À l’aide d’une pince, plier l’extrémité du fil sur 1 ou 2 mm de façon à faire un petit crochet qui rentrera dans le trou d’extrémité. Plier ensuite le fil pour effectuer le chemin désiré. Pour mesurer les sections de la piste, s’aider d’un gabarit, par exemple en prenant les chutes de la plaque pour s’en servir de règle graduée en pastilles. Quand le chemin est complexe, on peut faire un contrôle de temps en temps en posant la piste sur la plaque et en ajustant. À la fin, refaire un crochet, faire les derniers ajustements et couper le bout excédentaire.

Bien regarder ce qui passe sur le trajet, il peut être nécessaire de s’écarter un peu du centre des pastilles pour laisser la place à des pattes de composant. De même, éviter de faire partir le fil directement de l’emplacement d’une patte, la soudure à cet endroit empêchera l’insertion du futur composant sans compter qu’il n’y aura peut-être pas assez de place pour les deux.

Souder aux extrémités et aux angles. Rajouter des points de soudure sur les portions un peu longues, pour consolider.

Lors de la soudure des composants, il faudra faire un petit pont pour relier la piste à la patte du composant.

##### Fils de connexion côté composants

Certaines plaques ont besoin d’avoir des fils de connection, côté composants. Prendre du fil isolé et le dénuder sur 2–3 mm auparavant. Coincer le fil dans la plaque avec une pince crocodile. Ne pas mordre directement à l’emplacement de la soudure. Faire plutôt une sorte de U renversé en plaquant le fil un peu plus loin et en le faisant rentrer verticalement. En gros, la pince doit exercer sur le fil une pression verticale légère pour le maintenir contre le trou et tenter de le faire rentrer plus loin (il est bloqué par sa gaine). Quand le fer va chauffer le fil, l’isolant va se rétracter un petit peu et le fil va avancer. Cette méthode permet d’avoir la gaine qui descend aussi bas que possible, ce qui est nécessaire pour éviter les court-circuits entre plusieurs fils plantés les uns à côté des autres.

##### Carte d’alimentation 5 V

Souder les borniers puis le bloc d’alimentation. Relier les pattes en soudant des fils de cuivre nu ou en posant de grands ponts de soudure. Se référer au schéma de PCB pour placer ces pistes.

Certaines pistes et broches (J501 et les broches 1 et 2 du bloc) véhiculent des tensions secteurs. Il sera nécessaire de gratter soigneusement le cuivre autour de ces pistes sur au moins une pastille de large (2,5 mm) afin d’éviter toute possibilité de court-circuit. Une mini-perceuse munie d’une petite fraise arrondie est parfaite pour ce travail. Bonus : recouvrir ces pistes et broches de vernis.

De même, faire attention aux trous de montage. Veiller à ce que les écrous, rondelles et entretoises restent suffisamment éloignées des pistes secteur.

##### Carte des boutons de navigation

Sur cette carte, les boutons sont sur le côté cuivre et le connecteur côté composants. Il y a deux approches possibles. La première consiste à utiliser le cuivre de la carte pour y faire certaines connexions, la masse par exemple. Cette option est relativement simple si on utilise une Veroboard plutôt qu’une plaque à pastilles ; il suffit de couper les pistes aux bons endroits. C’est la solution que j’ai retenue car je disposais de chutes de Veroboard. Dans le cas d’une plaque à pastilles, il faut constituer des pistes en ajoutant du fil de cuivre nu ou des ponts de soudure. Ces éléments conducteurs vont alors se retrouver sous les boutons. Veiller à ce que les boutons, une fois en place, reposent de manière stable et horizontale sur les pistes. De plus, il faudra veiller à laisser des trous ouverts pour insérer les pattes de ces boutons, ce qui peut être compliqué.

La deuxième option consiste à tout câbler côté composants avec du fil isolé. Dans ce cas, commencer avec les éléments près du connecteur, car le câblage va devenir assez dense à cet endroit.

Souder les boutons rangée par rangée, un par un, par le dessus. Souder entre deux boutons peut être un peu délicat, faire attention à ne pas faire fondre le plastique en baladant le fer. Veillez à ce que les boutons soient bien plaqués à la carte lors de la soudure. En effet, ils vont devoir encaisser des pressions importantes et régulières, et cela ne doit pas faire travailler les soudures.

Il n’est pas nécessaire de relier toutes les pattes. Chaque bouton en a quatre, elles sont reliées deux à deux en interne, constituant deux uniques pôles. Il suffit de souder et de connecter une patte de chaque pôle. En fonction de la solution de connexion retenue, souder les câbles au fur et à mesure, ou après soudure de l’ensemble des boutons. À vous d’évaluer ce qui va être le plus pratique à faire. Sur le connecteur, il n’y a que deux pattes de masse pour les six boutons, il vous faudra donc faire des dérivations.



Carte des boutons de navigation, côté composants.
Ici, une plaque à bandes (Veroboard) a été utilisée pour simplifier le câblage.
Les fils sont soudés des deux côtés pour des raisons pratiques.

##### Cartes des codeurs incrémentaux

Comme pour les boutons, la soudure des codeurs se fait côté cuivre. Idéalement il faudrait fixer les codeurs sur la plaque de façade et les souder une fois en place. On s’assure ainsi que le positionnement est bon par rapport au perçage. Cependant l’espace entre les codeurs et la plaque est réduit, ce qui peut rendre la manipulation ardue.

S’il est trop compliqué de faire ainsi, souder les composants au mieux, puis vérifier le placement sur la façade. Si nécessaire, agrandir avec une lime de section arrondie les trous qui nécessitent un réajustement.

Faire la liaison entre les connecteurs et les codeurs à l’aide de ponts de soudure. Pour les deux codeurs à boutons, ajouter côté composants des fils isolés reliant le connecteur aux deux bornes de l’interrupteur.



Codeurs incrémentaux, paramètres



Codeurs incrémentaux, navigation

##### Carte des LED

La carte des LED est un peu spécifique car d’une part elle est double face et d’autre part elle est accompagnée d’un support.

Le support sert à retenir les LED. Il est plaqué contre la façade, par le dessous. Compte tenu des dimensions des LED que j’ai utilisées, le support doit être une plaque d’environ 2 mm d’épaisseur. Ici, j’ai pris un reste d’aluminium de 2,5 mm. Cependant ces LED au format plat semblent difficiles à trouver aujourd’hui. Si les vôtres sont plus hautes (c’est le cas des LED standard), on peut prendre une plaque de 3–5 mm. L’essentiel, c’est que les LED ne dépassent pas du boîtier, ou à peine. Elle peut être en bois, en plastique ou dans n’importe quel autre matériau suffisamment robuste. Ses dimensions doivent correspondre à peu près à celle de la carte. Elle peut être plus grande, mais il faudra veiller à ce qu’elle ne rentre pas en collision avec un autre élément du boîtier.

Une fois le support prêt, attacher la carte dessus avec un serre-joint, le côté cuivre. Percer les trous de fixation. Ce procédé garantit que les trous seront bien en face les uns des autres. Puis, en maintenant carte et support attachés, marquer sur ce dernier à l’aide d’une mine les trous dans lesquels seront placées les pattes des LED.

Détacher le support et marquer le centre de chaque LED. Percer les trous d’accueil de ces LED, d’un diamètre de 5 mm. Il faut être précis car en terme d’esthétique, le moindre écart va être visible. Vérifier ensuite l’alignement avant et après perçage avec le panneau du dessus du boîtier.

On passe ensuite les LED sur le circuit, toujours sans les souder. On assemble tout : la plaque dans laquelle on coince la tête des LED, le circuit qui leur tient les pattes, et les boulons avec leur entretoise qui maintiennent les deux supports à distance suffisante.

Il faut choisir les entretoises pour laisser de la place entre le circuit et la base de la tête des LED. En effet, les LED sont fixées côté pastilles, et à moins d’avoir une plaque double face, il faudra souder de ce côté, entre la plaque et les têtes. Des entretoises de 5 mm conviennent bien, mais on peut aussi en prendre de 10 mm si la soudure par l’intérieur semble trop difficile. Au besoin, ajuster la hauteur avec des rondelles. S’assurer également de disposer de vis de longueur suffisante, en comptant les épaisseurs du panneau et des diverses rondelles.

Bien aligner les LED avant de les souder. Une fois les LED fixées, on peut démonter la plaque. Souder les pistes et le reste des composants. On peut aussi faire les opérations dans l’ordre inverse, ça n’a pas vraiment d’importance.



Montage ayant servi au prototype de Pédale Vite



Carte LED, montée.

#### Test des connexions

Avant de fixer les circuits intégré, il faut tester les connexions. Utiliser un multimètre en mode testeur de fils ou ohm-mètre. C’est important de le faire avant de fixer les circuits ingégrés ou les connecteurs, parce que les circuits peuvent avoir des contacts internes qui vont venir fausser les mesures.

Avoir devant soi un plan récapitulant les broches de chaque connecteur. Pour chacun d’entre eux, vérifier les choses suivantes :

- Pour chaque broche de masse, vérifier qu’aucune autre broche n’est en contact avec elle, sauf peut-être d’autres broches de masse.
- Idem pour les broches d’alimentation, vérifier sur les supports des circuits intégrés que ces broches aboutissent bien. On retrouvera tout de même des connexions avec d’autres broches via les résistances de tirage (pull-up). Vérifier que ça arrive sur les boutons, et vérifier les résistances indiquées.
- Pour chaque paire de broches voisines, vérifier qu’il n’y ait pas de contact, ou alors que les résistances indiquées soient cohérentes.
- Quand il y a deux paquets de soudure suspects l’un à côté de l’autre sur la plaque, vérifier qu’ils ne sont pas en contact.
- Pour les autres broches type GPIO, vérifier qu’elles sont connectées aux bonnes broches sur les supports ou connecteurs.
- En bonus, on peut trituer les fils isolés lors des tests pour vérifier que la connexion ne bouge pas.

Ces tests ne donnent certainement pas une garantie de fonctionnement, mais s’ils sont fait rigoureuseuement, permettent de débusquer la grande majorité des erreurs et minimisent les risques de court-circuit.

Une fois les vérifications effectuées, on peut insérer les circuits intégrés. Sur ceux en boîtiers DIP, les pattes ne sont pas tout à fait verticales et ne rentrent pas telles quelles dans les supports. Il faudra donc achever de les plier. Cela peut être fait patte par patte, ou d’un seul coup en prenant le composant dans un étau à l’horizontal et en serrant très précautionneusement les mors pour rendre les pattes bien droites.

#### Câblage

Pour relier le Pi et la carte principale, on peut prendre une nappe IDE à l’ancienne, qui sont des HE10 de 40 broches. Il y a souvent un détrompeur qui bouche un des trous, il suffit de le percer avec une pointe type couteau ou ciseaux. La broche femelle apparaît derrière. On peut vérifier avec un multimètre et deux broches mâles que la connexion se fait bien entre les deux trous débouchés. Attention, il faut que ce soit une nappe de 40 fils, et surtout pas les nappes plus récentes Ultra-DMA de 80 fils. Leurs connexions ne sont pas équivalentes, et parfois même un fil est coupé. En terme de connexion, le fil qui se trouve du côté de la carte micro-SD sur le Pi doit aboutir côté gauche sur la carte principale (le repère coloré indique la première broche).

Pour les autres câblages, se reporter à la feuille de calcul qui indique qui est connecté avec qui (chaque lettre identifie un fil), avec quel type de connecteur, et quelle longueur de câble est nécessaire.

Vous pouvez entortiller les câbles à plusieurs conducteurs. Attention cependant, plus l’entortillement est prononcé, plus le câble se raccourcit.

Certains connecteurs disposent de détrompeurs, il convient donc de faire attention à ce que la partie femelle soit orientée de la même façon que la partie mâle. En revanche, les connecteurs Dupont ne sont pas orientés, et c’est au branchement qu’il faut faire attention à l’orientation. Peindre une tache de couleur sur un des angles de chaque connecteur mâle et femelle afin de faire la correspondance facilement.

Certains câbles peuvent avoir des fils qui se croisent, faire bien attention au brochage.

Le câblage de l’écran est spécifique, puisque trois prises sont interconnectées.

Les boutons et pédales partagent quelques fils de masse. Préparer les câbles en les sertissant d’un seul côté. Ils seront soudés et connectés plus tard.

##### Câblage audio et masses

Les connexions audio doivent utiliser du câble blindé à double conducteur, en plus du blindage. Le blindage doit être relié à la masse (voir plus bas). Les câbles multi-conducteurs qui n’ont pas de masse, comme ceux des potentiomètres de gain, doivent êtres entortillés. De manière générale, utiliser un câblage aussi court que possible afin de limiter l’exposition aux parasites.

Pour éviter les boucles de masses et les ronflettes induites, les masses des circuits sont câblées en étoile, ou au pire, en arborescence. Les liaisons entre différentes « sections » de masse doivent être uniques. Sinon, cela forme des boucles.

Dans Pédale Vite, les masses sont organisées de la façon suivantes :

- La carte audio dispose de deux plans de masse indépendants. L’une correspond au circuit analogique, l’autre au circuit numérique. Ces deux masses ne devraient être connectées qu’en un seul point, le cavalier JP2.
- La masse de la partie analogique doit être connectée à l’extérieur uniquement par la première entrée (gauche) de la partie jack du combo jack-XLR. Les fils de masse de tous les autres connecteurs doivent être débranchés à une de leur extrémité. Ils doivent cependant y rester connectés en un point, car la liaison à la masse assure l’efficacité du blindage.
- Les masses des autres connecteurs audio sont connectées au chassis, soit naturellement dans le cas des prises jack non-isolées, soit en soudant la broche de masse à la broche en contact avec le chassis dans le cas des combo en plastique. Ceci est aussi valable pour la partie XLR du combo de la première entrée. Attention d’ailleurs à celle-ci : j’avais intercalé une cosse entre le combo et le boîtier, rendant le combo imparfaitement plaqué contre la paroi. Du coup les petites dents reliées à la borne G et censées mordre dans le boîtier faisaient mauvais contact, entraînant un bourdonnement (1 Ω, c’est déjà trop). J’ai dû rajouter une deuxième cosse pour faire la liaison explicitement par câble.
- Toutes les alimentations sont isolées et n’induisent pas de liaison explicite à la masse ou à la terre.
- La terre venant de la prise secteur est reliée au chassis, et donc à la masse. Idéalement il faudrait faire courir un fil allant se brancher sur la masse de première entrée audio afin de respecter la topologie en étoile, mais on peut considérer que la façade arrière du boîtier comme un plan de masse, elle est suffisament conductrice. On pourra donc connecter la terre au boîtier au niveau de l’une des vis de la prise secteur, via une cosse.
- Les différents panneaux du boîtier doivent être interconnectés. Il est possible que les cornières en aluminium soient anodisées, et donc isolantes. Il faudra donc assurer la liaison entre tous les panneaux avec du fil et des cosses insérées sur les vis, coincées par les écrous. Il faudra éventuellement creuser un des piliers centraux afin de faire passer la cosse qui fera contact avec la plaque du dessous.
- La masse de la carte principale est reliée à celle du Pi par le connecteur 40 broches. Cette masse est propagée à l’écran et à la partie numérique de la carte son. Les commutateurs sont isolés.
- Ne souder qu’une des extrémités des fils de masse des connecteurs jack des pédales d’expression, car ils sont déjà reliés à la masse globale par le boîtier.
- Les cartes dont les plans sont livrés ici ainsi que celle du Pi sont isolées au niveau des trous de fixation, ce qui ne provoque pas de liaison entre masse et boîtier. Ce n’est malheureusement pas le cas de l’écran. Il sera donc nécessaire de couper le plan de masse au niveau de chaque « oreille » de fixation, des deux côtés du PCB. Utiliser pour cela un cutter bien affûté ou l’angle d’une lime. Vérifier au multimètre que chaque oreille se retrouve bien isolée.
- L’écran a une double connexion avec le Pi : une directement par le câble HDMI, qui véhicule une masse, et l’autre par les câbles d’alimentation et de signaux pour le capteur tactile (via la carte principale). Bien qu’il soit tentant de déconnecter la masse d’alimentation pour ne laisser que celle du HDMI, il vaut mieux garder les deux. En effet les fils HDMI sont probablement trop fins pour véhiculer correctement le courant de retour servant pour le rétroéclairage et le contrôleur.
- Sur la carte son, les deux masses analogique et numérique ne sont pas explicitement reliées. Il est possible de le faire avec un cavalier au niveau de JP2, situé près du connecteur d’alimentation. Une fois que tous les éléments seront installés dans le boîtier (voir plus bas), tester avec un multimètre le contact entre les deux broches de JP2. S’il n’existe aucun contact stable (il y a tout de même un condensateur d’évacuation des hautes fréquences qui peut perturber le multimètre) — et ce devrait être le cas, ajouter le cavalier. Sinon, laisser JP2 sans cavalier.

Ces considérations devraient permettre d’obtenir une masse sans boucle.



Carte des masses (traits gras).

 

Connecteurs audio d’entrée (gauche) et de sortie (droite).
Ne pas faire attention aux résistances qui ont été soudées par goût de l’expérimentation.



Connexion des masses analogique et numérique avec JP2 sur la carte audio.

 
 
 

Interconnexion des plaques du boîtier.



Connecteurs des pédales d’expression.

 

Trous de montage violemment isolés de la masse du circuit de l’écran.

##### Alimentation du Pi

Le Raspberry Pi 4 s’alimente par une prise USB-C ou par le GPIO. Nous allons l’alimenter par l’USB-C, la nappe reliant le GPIO n’étant probablement pas suffisamment robuste pour véhiculer les 3 A nécessaires à son fonctionnement.

Étant donné qu’il est très difficile de trouver une fiche USB-C à câbler soi-même, nous allons prendre un cordon d’alimentation USB-A vers USB-C et le couper. Il suffit de conserver une quinzaine de cm depuis la prise USB-C.

Il s’agit ensuite d’identifier les conducteurs. Récupérer l’autre morceau du câble, celui qui se termine par la prise USB-A, car cette prise est plus grosse et il sera plus aisé d’en tester les broches. Vu de face (https://en.wikipedia.org/wiki/USB#/media/File:USB.svg), les broches du connecteur orientées vers le haut, le pôle négatif de l’alimentation se trouve tout à gauche, et le positif tout à droite. En premier lieu, il y a de grandes chances que le blindage soit relié au pôle négatif. Pour le pôle +5 V, tester la continuité entre chaque fil et la broche. Ne pas se fier à la couleur des isolants.

Une fois que les deux fils sont repérés, les dénuder sur 3 mm. Les sertir de petits embouts de câblage si vous avez le matériel nécessaire, car ces fils sont souvent assez fins et risquent de mal tenir dans les borniers. Sinon, dénudez plus de fils et faite un pliage avec le conducteur de façon à avoir plus de matière. Replier les éventuels autres fils le long du câble et les y attacher avec du ruban adhésif isolant.

Enfin, connecter le câble au bornier de la carte 5 V en respectant la polarité.



Alimentation du Pi. Le câble 5 V est en blanc.

### Assemblage

#### Premier assemblage

On peut maintenant fixer au boîtier la plupart des éléments : cartes, prises, interrupteurs… Comme le Pi est positionné très près du panneau du dessus et que son PCB est relativement flexible, il est nécessaire de couper à ras les pattes de ses connecteurs USB et RJ45, qui sont plus proéminents que le reste. Le lecteur de carte micro-SD est également proeminent. Son enveloppe est reliée à la masse et ne pose donc pas de problème, mais elle risque de provoquer une boucle de masse si elle rentre en contact. Pour éviter tout risque, tapisser l’endroit qui accueillera le Pi avec du ruban adhésif isolant.



Intérieur du boîtier sans cablage ni Pi.

Dans le même ordre d’idée, il faudra recouvrir d’isolant la partie de la cornière située juste en-dessous de la carte son.

De même, il sera nécessaire de recouvrir d’isolant la plaque du dessous au niveau du transformateur torique. En effet, s’il se formait une boucle conductrice traversant le tore, ce serait l’équivalent d’une spire en court-circuit et cela peut mettre en danger le transformateur.



Isolation de protection de la vis du transformateur, sur la plaque du fond.

En parlant de transformateur, j’ai jugé nécessaire d’ajouter une grosse rondelle sur la vis d’attache, pour éviter qu’un jour celle-ci ne traverse la plaque sous le poids du transfo.



Rondelle pour rigidifier la partie de la plaque soutenant le transformateur.

Hauteur des entretoises nécessaires pour chaque carte :

- LEDs : 5–10 mm
- Boutons de navigation : 10 mm
- Écran : 4 mm
- Alimentation 5V : 5 mm
- Raspberry Pi 4 : 3 mm
- Carte son : 12–13 mm
- Carte principale : 5 mm
- 2 × 15 V AC → DC : 5 mm

Il est sans doute préférable de ne pas monter le Pi définitivement à cette étape. En effet, pour installer le logiciel il sera nécessaire d’accéder à la carte SD qui deviendra difficilement accessible une fois que tout sera monté.

#### Câbles d’alimentation

Glisser préalablement un fusible dans la cartouche, plus un de rechange. Commencer par vérifier avec un multimètre le brochage de la prise secteur et de l’interrupteur. Il s’agit d’établir qui est en contact avec qui et dans quelle position.

Pour cette partie, prendre du câble électrique multibrin conçu pour le secteur. Les puissances véhiculées ne sont pas très fortes, mais il faut tout de même une épaisseure minimale d’isolant.

Il y a plusieurs câbles à réaliser : deux pour relier la phase et le neutre entre la prise et l’interrupteur, un pour relier la terre au boîtier, et deux pour relier l’interrupteur au module d’alimentation 5 V. Le transformateur 15 V dispose déjà de ses câbles, qui devront être branchés sur l’interrupteur également. Les broches sortant de l’interrupteur devront donc accueillir deux câbles en dérivation, l’un vers le module 5 V, l’autre vers le transformateur.

Si vous disposez du matériel permettant de sertir des cosses Faston, couper les câbles aux dimensions requises et les sertir. Ne pas oublier de prendre les deux câbles dans la cosse pour les sorties d’interrupteur.

Une fois les cosses attachées, ajouter un boîtier isolant. Il pourra être nécessaire de légèrement plier les bornes mâles pour éviter de toucher le fond du boîtier.



Câblage secteur avec cosses Faston isolées.

Sans cosses Faston, il faudra souder les câbles. Penser à glisser avant soudure deux voire trois morceaux de gaine thermo-rétractable par contact soudé afin de ne pas laisser exposé de conducteur secteur (sauf terre).

Fixer les deux sorties du transformateur dans les borniers de la carte 15 V. Ces deux sorties doivent être branchées en série et avec la même polarité. Sur le circuit, les deux borniers centraux sont connectées ensemble. En cas de doute, tester le transformateur avec un multimètre. Si la tension en série est nulle ou presque, inverser un des deux circuits.



Secondaire du transformateur 2 × 15 V connecté à la carte de rectification 2 × 15 V.

#### Soudure des câbles des interrupteurs

Il y a moins de fils de masse qui sortent des connecteurs que de fils véhiculant du signal : quatre pour les pédales et deux pour les boutons de l’interface d’utilisation. Souder les fils de masse aux interrupteurs les plus proches du connecteur et passer la masse de proche en proche en soudant des fils intermédiaires.

Les interrupteurs des pédales demandent un traitement attentif et délicat. En premier lieu, si on utilise des DPDT, il faut partir du principe que la position de contact de chaque interrupteur est unique. Il n’y a pas de marque ou de signe distincif fiable donnant une orientation. La cosse commune (masse) est au centre et c’est tout ce que l’on sait. Il faut tester individuellement chaque interrupteur à l’aide d’un multimètre pour connaître la paire de broche correspondant à un contact en position enfoncée.

D’autre part, si le modèle d’interrupteur donné dans la liste de matériaux est plutôt robuste, fiable, et sans problème de montage ou de soudure, en revanche certains autres modèles peuvent se révéler assez fragiles. Dans ce cas, lors du vissage il faut faire attention à ne pas trop appuyer sur le boîtier plastique car celui-ci peut se disloquer ou se détacher. Lors de la soudure, ce même boîtier plastique peut se ramollir et fondre car la masse de métal du connecteur est importante et nécessite un apport de chaleur significatif. Si jamais la patte bouge dans le boîtier ramolli, le contact peut être foutu. Il faut alors déssouder le tout et retenter sa chance sur la deuxième voie. Tester une nouvelle fois au multimètre le fonctionnement de l’interrupteur une fois les soudures correctement effectuées.

Quand tous les fils des interrupteurs sont soudés, on peut les regrouper par connecteur.



Connexion des commutateurs au pied.

#### Derniers ajustements et fermeture

Finir de brancher les câbles. Tous.



Carte principale, hyper-branchée.
Ne pas faire attention à l’inversion des fils bleu et vert sur le connecteur audio. Il y avait une erreur dans le prototype de la carte.



Connecteurs de sortie sur la carte audio. La sortie symétrique utilise la partie 1–2–3.

Personnellement, je n’ai pas monté les potentiomètres et boutons de gain de la carte son car je n’en ai pas besoin pour l’instant. À la place, j’ai utilisé des cavaliers pour sélectionner le niveau microphone plutôt que ligne sur la prise XLR, et fixé le gain global avec une résistance.



La paresse l’emporta. Pas (encore) de bouton pour les gains.

Pour un gain d’entrée voulu, la résistance en ohms est donné par la formule suivante :

R = 2000 / (Glin − 1) = 2000 / (10GdB/20 − 1)

Où Glin représente le gain linéaire et GdB le même gain exprimé en décibels. Pour un gain unitaire, il faudrait une résistance infinie et donc laisser les connecteurs Gain pot sans rien dessus. Dans la pratique, il est plus judicieux de ne pas dépasser 10 kΩ afin de ne pas introduire trop de bruit thermique.

Pour fixer la résistance, il suffit de sertir ses deux pattes avec des fiches femelle Dupont et de les introduire dans un boîtier.



Résistance dans un boîtier Dupont.



Connecteurs d’entrée sur la carte audio. Le niveau micro est sélectionné avec deux cavaliers, les emplacements pour les commutateurs d’atténuation ont été laissés vides, et une résistance remplace le potentiomètre de gain sur la première entrée.



L’intérieur est fin prêt. Sur cette version, il manque quand même le câblage de l’écran tactile.

Quand tout est prêt et que le boîtier peut être fermé, ajuster la cosse de masse de la plaque du fond pour qu’elle tombe au-dessus (ou en-dessous ?) du trou dans le pilier. Poser la plaque. Insérer des vis de 40 mm dans les pieds en gomme et les visser sur dans les piliers et les angles sans trop forcer. Le pied en gomme ne doit plus être libre de tourner, n’allez pas au-delà. Soyez soigneux avec ces vis (ou plutôt les pas de vis des trous) car il est possible que vous ayiez à les enlever et les remettre de nombreuses fois pour faire les derniers ajustements et plus tard, de la maintenance. Je vous conseille d’ailleurs de ne pas fermer le boîtier tant que le pédalier n’est pas parfaitement opérationnel, et de retirer le Pi pour l’installation logicielle.



Huit pieds pour un boîtier.



Arrière de Pédale Vite.

Si au cours de vos tests vous vous rendez compte que vous avez inversé des pédales, des boutons, des sens de rotation des codeurs incrémentaux, il est toujours possible de les inverser soit au niveau des câbles (il est facile de substituer deux fils sur un connecteur), soit au niveau du logiciel.

Note : le Pi 4 est connu pour chauffer beaucoup. En cas de charge de calcul trop importante, des dispositifs internes de protection thermique peuvent s’activer et réduire sa vitesse. Dans le cas de Pédale Vite, toute la puissance du processeur n’est pas utilisée. En pratique, la température interne reste toujours en dessous de 65 °C, selon des tests effectués à 17 °C de température ambiante avec une charge très importante, à la limite de la stabilité (90 % d’occupation). On peut extrapoler que jusqu’à 40 °C, il n’y a pratiquement aucun risque que le Pi ne ralentisse sa cadence pour se préserver. Il n’y a donc pas besoin de dispositif de refroidissement supplémentaire (dissipateurs ou ventilateurs).

## IV. Installation logicielle

Cette partie est simple mais un peu laborieuse car demandant de nombreuses interventions manuelles. Cependant la plupart d’entre elles peuvent être scriptées ; j’essaierai un jour de le faire pour simplifier la tâche, mais cela demande une certaine somme de travail.

### Préparation du système

La version minimum de Raspberry Pi OS recommandée est Buster (catégorisée comme Legacy), datée du 2019-09-26. Préférez une version 32 bits les versions 64 bits n’ont pas encore été testées, et quoi qu’il arrive, en version Lite.

#### Bullseye (2022) et versions supérieures

Il est préférable de passer par le Raspberry Pi Imager (https://www.raspberrypi.com/software/) afin de personnaliser l’image du système avec un compte utilisateur accessible en SSH. Télécharger et installer l’Imager. Choisir « Raspberry Pi OS (32-bit) » comme Operating System, ou « Use custom » tout à la fin de la liste si vous avez précédemment téléchargé une version particulière.

Cliquer sur l’icône représentant un pignon (Avanced Options), cocher Enable SSH en autorisant le mode par mot de passe, cocher Set username and password et remplir les deux champs juste en dessous. Sauver.

Dans Choose storage, sélectionner le lecteur de la carte micro-SD à écrire. Finalement, cliquer sur Write.

#### Buster

Télécharger Raspberry Pi OS (https://www.raspberrypi.com/software/operating-systems/). Décompresser quelque part le fichier .img contenu dans l’archive.

Commencer par formater la carte, si ce n’est pas déjà fait :

- Aller sur le site sdcard.org, rubrique Downloads > SD Card Formatter > SD Formatter for Windows Download (en ce qui me concerne).
- Accepter la licence, télécharger l’archive, installer le programme et le lancer.
- Insérer la carte SD, cliquer Refresh, sélectionner le bon lecteur.
- Cliquer sur Options, passer « Format size adjustement » à « ON ».
- Cliquer sur Format et attendre que ce soit fini. En principe c’est rapide.

Sous Windows, télécharger Win32DiskImager (https://sourceforge.net/projects/win32diskimager/) (ImageWriter), l’installer et le lancer. Sélectionner l’image (fichier .img) Raspbian décompressée. S’assurer que Device pointe sur le bon lecteur. Cliquer sur Write, confirmer et attendre que l’image finisse d’être copiée sur la carte.

Autoriser ensuite l’accès SSH dès le premier boot. Pour cela, aller à la racine de la partition nommée boot et créer un fichier vierge (son contenu n’a pas d’importance) intitulé ssh.

#### Tronc commun

Le système est maintenant prêt à être lancé pour la première fois. Retirer la carte micro-SD de la machine et l’insérer dans le lecteur du Pi. Cette étape peut être difficile si le Pi est déjà monté dans le boîtier. Si c’est le cas, tenir la carte à l’envers à la toute extrémité d’une paire de fines pinces à long bec. S’armer de patience et faire glisser la carte délicatement en la collant contre le PCB du Pi, par le dessous. Veiller à ne pas endommager la carte.

Une fois ceci fait, brancher une prise réseau et l’alimentation.

### Démarrage et mise à jour du système

Allumer le Pi, attendre un peu que le système se charge et que SSH se mette en route. En principe le Pi est prévu pour se faire attribuer une adresse IP par DHCP, à vous de voir avec votre installation quelle adresse lui est donnée. Si ce n’est pas possible, il faut brancher un écran et un clavier avant le premier démarrage et commencer depuis le terminal local.

Se loguer avec les identifiants de base (pi / raspberry, ou ce que vous avez choisi avec le Raspberry Pi Imager).

Si nécessaire, on peut commencer par régler les préférences de langue et de clavier :

sudo raspi-config

Sélectionner 5. Localisation Options et régler les préférences voulues. Finalement, flèche gauche pour sélectionner Finish. Inutile de redémarrer tout de suite même si les messages de la console vous le conseillent.

Important : à partir de là, et jusqu’à la fin de l’installation, le Pi va nécessiter d’être connecté aux internets.

Mettre à jour le système :

sudo apt-get -y update
sudo apt-get -y dist-upgrade

L’opération va prendre un peu de temps, allez donc faire quelques exercices isométriques (http://george-abitbol.fr/v/722d9335) en attendant.

Maintenant, on peut redémarrer:

sudo shutdown -r now

### Configuration de base

Commençons par faire quelques réglages. On va avoir besoin d’activer les interfaces SPI et I2C pour communiquer avec les différents composants nécessaires.

sudo nano /boot/config.txt

Modifier les lignes suivantes en les commentant ou décommentant comme suit en ajoutant ou retirant caractère # en début de ligne :

dtparam=i2c_arm=on
dtparam=spi=on
#dtparam=audio=on
#dtoverlay=vc4-fkms-v3d

Donc on vire le son par défaut au passage. La dernière ligne se retrouve à plusieurs endroit, faites en sorte qu’elle soit commentée partout. Ajouter les lignes suivantes dans la section [all] tout à la fin :

# Disable rainbow image at boot
disable_splash=1

# Waveshare 4 inch HDMI LCD
hdmi_group=2
hdmi_mode=87
hdmi_timings=480 0 40 10 80 800 0 13 3 32 0 0 0 60 0 32000000 3
disable_overscan=1
framebuffer_priority=2
# Looks like the touchscreen driver uses the SPI interface exclusively
#dtoverlay=ads7846,cs=1,penirq=12,penirq_pull=2,speed=50000,keep_vref_on=0,swapxy=0,pmax=255,xohms=150,xmin=200,xmax=3900,ymin=200,ymax=3900
display_hdmi_rotate=1

# No Bluetooth, no WiFi
dtoverlay=disable-bt
dtoverlay=disable-wifi

Attention, l’instruction dtoverlay=ads7846…ymax=3900 tient sur une seule ligne. Ctrl+X pour sauver et quitter. Ensuite on demande de charger le module I2C lors du boot :

sudo nano /etc/modules

Ajouter les lignes suivantes à la fin du fichier :

i2c-bcm2708
i2c-dev

On peut préparer le terrain pour le branchement d’un éventuel système de stockage USB :

sudo mkdir /mnt/sda1
sudo chmod 775 /mnt/sda1

### Optimisation du temps de démarrage

Éditer le fichier :

sudo nano /etc/modprobe.d/raspi-blacklist.conf

Ajouter les lignes suivantes pour désactiver WiFi et Bluetooth :

#wifi
blacklist brcmfmac
blacklist brcmutil
#bluetooth
blacklist btbcm
blacklist hci_uart

Puis taper :

sudo apt-get remove -y --purge pi-bluetooth

Et on redémarre une nouvelle fois pour prendre en compte toutes les modifications :

sudo shutdown -r now

### Installation des dépendances logicielles

Installer git, Jack2, ALSA et autoconf :

sudo apt-get -y install libjack-jackd2-dev libasound2-dev \
    git autoconf raspberrypi-kernel raspberrypi-kernel-headers

### Installation de Clang (faculatif)

Il est possible d’installer une verion récente de la suite de compilation Clang. Cette étape est facultative, mais Clang permet une accélération substantielle (environ +25 % selon mes mesures faites à l’époque) du programme Pédale Vite par rapport à GCC, le compilateur installé par défaut. Ici, nous allons installer Clang 14.0.6, la dernière version en date d’écriture de ce texte, mais il est probable que des versions plus récentes soient disponibles (http://releases.llvm.org) à l’heure où vous lisez ces lignes. Si c’est le cas, remplacer le 14.0.6 à la première des lignes suivantes par le numéro de version en question. Il est aussi possible de rester sur Clang 14.0.6, qui conviendra très bien.

Note : 14.0.6 est la dernière version qui fonctionne sous Buster. Les versions suivantes nécessitent une version plus récente de la libc6 que celle disponible via le système de mise à jour.

Vérifier au préalable qu’il y a suffisamment d’espace sur le disque si celui-ci est de faible capacité : installer Clang nécessite environ 3 Go de libre.

clangversion="14.0.6"
cd ~
wget https://github.com/llvm/llvm-project/releases/download/llvmorg-$clangversion/clang+llvm-$clangversion-armv7a-linux-gnueabihf.tar.xz
tar -xvf clang+llvm-$clangversion-armv7a-linux-gnueabihf.tar.xz
rm clang+llvm-$clangversion-armv7a-linux-gnueabihf.tar.xz
mv clang+llvm-$clangversion-armv7a-linux-gnueabihf clang_$clangversion
sudo mv clang_$clangversion /usr/local
echo 'export PATH=/usr/local/clang_'$clangversion'/bin:$PATH' >> .bashrc
echo 'export LD_LIBRARY_PATH=/usr/local/clang_'$clangversion'/lib:$LD_LIBRARY_PATH' >> .bashrc
. .bashrc
clang++ --version

La partie commençant par wget et finissant par .xz tient sur une seule ligne, ainsi que la deuxième ligne echo. En principe, tout devrait marcher correctement, cependant j’ai eu des problèmes à lancer des exécutables utilisant la libc++ intégrée à Clang, qui n’était pas trouvée. Les lignes suivantes pallieront le problème :

echo '/usr/local/clang_'$clangversion'/lib/' > ./clang.conf
sudo mv ./clang.conf /etc/ld.so.conf.d/
echo '/usr/local/clang_'$clangversion'/lib/armv7l-unknown-linux-gnueabihf/' > ./libc.conf
sudo mv ./libc.conf /etc/ld.so.conf.d/
sudo ldconfig

Apparamment, mettre à jour libc.conf n’est nécessaire qu’à partir de Clang 15.

### Installation de Pédale Vite

On commence par télécharger le code dans ~/Documents.

cd ~
mkdir Documents
cd Documents
git clone https://github.com/EleonoreMizo/pedalevite.git

Configuration du projet :

cd pedalevite/build/unix
./autogen.sh
./configure-v2-release

Si Clang a été installé à l’étape précédente, remplacer la dernière ligne par :

./configure-v2-release CXX='clang++' CC='clang'

Finalement (on reprend le tonc commun), on compile :

make -j4

Vérifier que tout s’est bien passé et qu’il y a un exécutable pedalevite dans le répertoire courant. On installe ensuite le logiciel dans son répertoire, ainsi que quelques autres fichiers :

sudo mkdir -p /opt/pedalevite/bin
sudo mkdir -p /opt/pedalevite/etc/config
sudo mkdir -p /opt/pedalevite/etc/font
sudo mkdir -p /opt/pedalevite/var/audiodump
sudo cp ./pedalevite /opt/pedalevite/bin/pedalevite
sudo cp ../../bin/cmd_rofs.sh /opt/pedalevite/bin/cmd_rofs.sh
sudo cp ../../etc/font/* /opt/pedalevite/etc/font

Le Pi peut éventuellement être connecté à toutes les cartes et périphériques nécessaires (cf. les instructions de montage). Une fois ceci fait, on peut lancer Pédale Vite pour tester :

sudo /opt/pedalevite/bin/pedalevite

Le programme doit se mettre en route et tourner normalement. Ctrl+C pour l’interrompre, ou le quitter via les menus de l’interface d’utilisation.

### Démarrage automatique de Pédale Vite

Créer le fichier :

sudo nano /etc/init.d/pedalevite

Lui ajouter le contenu suivant :

#!/bin/sh
# kFreeBSD do not accept scripts as interpreters, using #!/bin/sh and sourcing.
if [ true != "$INIT_D_SCRIPT_SOURCED" ] ; then
    set "$0" "$@"; INIT_D_SCRIPT_SOURCED=true . /lib/init/init-d-script
fi
### BEGIN INIT INFO
# Provides:          pedalevite
# Required-Start:    $local_fs
# Required-Stop:     $local_fs
# Default-Start:     2 3 4 5
# Default-Stop:      0 1 6
# Short-Description: Starts and stops Pedale Vite
# Description:       This service is used to process the sound from a guitar
### END INIT INFO

case "$1" in
    start)
        echo "Mounting Pedale Vite directory as R/W..."
	mount --bind /opt/pedalevite/ /opt/pedalevite/
	mount -o remount,rw /opt/pedalevite/
        echo "Starting Pedale Vite..."
        /opt/pedalevite/bin/pedalevite &
        echo -n performance | sudo tee /sys/devices/system/cpu/cpu0/cpufreq/scaling_governor > /dev/null
        echo -1 | sudo tee /proc/sys/kernel/sched_rt_runtime_us > /dev/null
        systemctl stop getty@tty1.service
        ;;
    stop)
        echo "Stopping Pedale Vite..."
        killall pedalevite
        umount /opt/pedalevite/
        ;;
    *)
        echo "Usage: /etc/init.d/pedalevite start|stop"
        exit 1
        ;;
esac

exit 0

Puis :

sudo chmod +x /etc/init.d/pedalevite
sudo update-rc.d pedalevite defaults

Pédale Vite se lancera automatiquement au prochain démarrage du Pi. Il peut être lancé immédiatement :

sudo /etc/init.d/pedalevite start

### Passage du système en lecture seule et autres optimisations

Cette partie doit être traitée consciencieusement afin de ne pas laisser le système dans un état incohérent.

#### Script de retour au mode lecture-écriture

Commencer par ajouter un petit script qui permettra de revenir facilement à un système en lecture et écriture par la suite. L’exécution manuelle de ce script sera impérative avant toute mise à jour, compilation ou autres opérations de maintenance nécessitant un accès en écriture au disque.

cd ~
nano fs-rw.sh

Ajouter dans ce nouveau fichier :

#!/bin/sh
sudo mount -o remount,rw /
sudo mount -o remount,rw /boot

Lui donner les permissions d’exécution :

chmod +x ./fs-rw.sh

#### Plat principal

Retirer les choses qui ne sont pas nécessaire ni même adaptées à des opérations en lecture seule:

sudo apt-get remove -y --purge triggerhappy logrotate dphys-swapfile fake-hwclock
sudo apt-get -y autoremove --purge

Installer busybox syslog à la place de rsyslog :

sudo apt-get -y install busybox-syslogd
sudo dpkg --purge rsyslog

On édite les paramètres de boot :

sudo nano /boot/cmdline.txt

Ajouter fsck.mode=skip ro logo.nologo tout à la fin de la ligne (il n’y en a qu’une seule dans le texte qui suit) :

dwc_otg.lpm_enable=0 console=serial0,115200 console=tty1 root=/dev/mmcblk0p2 rootfstype=ext4 elevator=deadline fsck.repair=yes rootwait fsck.mode=skip ro logo.nologo

Remplacer certains sous-répertoires de var par des liens symboliques sur le lecteur RAM :

sudo rm -rf /var/spool
sudo ln -s /tmp /var/spool
sudo rm -rf /var/lib/lightdm /var/cache/lightdm
sudo ln -s /tmp /var/lib/lightdm
sudo ln -s /tmp /var/cache/lightdm

Éditer var.conf :

sudo nano /usr/lib/tmpfiles.d/var.conf

Remplacer la permission du spool 0755 par 1777 :

d /var/spool 1777 - - -

Déplacer dhcpd.resolv.conf dans tmpfs :

sudo touch /tmp/dhcpcd.resolv.conf
sudo rm /etc/resolv.conf
sudo ln -s /tmp/dhcpcd.resolv.conf /etc/resolv.conf

Éditer fstab :

sudo nano /etc/fstab

Ajouter ,ro après les defaults pour les partitions du disque :

proc            /proc           proc    defaults             0       0
/dev/mmcblk0p1  /boot           vfat    defaults,ro          0       2
/dev/mmcblk0p2  /               ext4    defaults,ro,noatime  0       1

Il se peut que ces lignes commencent par PARTUUID=. Ajouter également les ligne :

tmpfs           /tmp            tmpfs   nosuid,nodev         0       0
tmpfs           /var/lib/systemd/timesync tmpfs   nosuid,nodev         0       0
tmpfs           /var/log        tmpfs   nosuid,nodev         0       0
tmpfs           /var/tmp        tmpfs   nosuid,nodev         0       0

Éditer rc.local :

sudo nano /etc/rc.local

Ajouter le chmod avant le exit 0 :

  printf "My IP address is %s\n" "$_IP"
fi

chmod g+w,o+w /tmp
exit 0

Retirer les tentatives de mise à jour automatiques :

sudo systemctl disable apt-daily.timer
sudo systemctl disable apt-daily-upgrade.timer
sudo systemctl disable man-db.timer

Facultatif : pour rebasculer automatiquement en lecture seule quand on se déconnecte, éditer ou créer le fichier :

sudo nano /etc/bash.bash_logout

Ajouter les lignes suivantes à la fin :

mount -o remount,ro /
mount -o remount,ro /boot

Redémarrer. Pédale Vite est à présent opérationnel.

À ce point, il est toutefois conseillé de vérifier si la date se met à jour correctement une fois connecté à internet. Si ce n’est pas le cas, voir la section dépannage.

#### Quelques scripts pratiques

Facultatif. Attation aux sauts de ligne.

cd ~
echo '#!/bin/sh'$'\n\n''sudo mount -o remount,rw /'$'\n''sudo mount -o remount,rw /boot' > fs-rw.sh ; chmod +x fs-rw.sh
echo '#!/bin/sh'$'\n\n''sudo timedatectl set-ntp 1' > updatedate.sh ; chmod +x updatedate.sh
cd ~/Documents/pedalevite/build/unix
echo '#!/bin/sh'$'\n\n''sudo cp /opt/pedalevite/etc/config/current /opt/pedalevite/etc/config/current.bak-`date --utc +%Y-%m-%d-%H%M`' > backup-config.sh ; chmod +x backup-config.sh
echo '#!/bin/sh'$'\n\n''sudo jackd -P70 -p16 -t2000 -dalsa -p64 -n3 -r44100 -s &' > run-jack.sh ; chmod +x run-jack.sh
echo '#!/bin/sh'$'\n\n''sudo mount -t vfat /dev/sda1 /mnt/sda1' > usb-mount.sh ; chmod +x usb-mount.sh
echo '#!/bin/sh'$'\n\n''sudo umount /mnt/sda1' > usb-umount.sh ; chmod +x usb-umount.sh

## V. Maintenance

### Tests et dépannage

À venir…

#### Problèmes connus

##### Réseau non disponible

Pour une raison inconnue, le système n’arrive pas à se connecter au réseau au démarrage. En général, un redémarrage règle le problème.

##### Le programme Pédale Vite refuse de redémarrer après un crash

Quand Pédale Vite se lance, il crée un fichier temporaire indiquant qu’une instance du programme est lancée, ce qui empêche de lancer plusieurs instances à la fois. Ce fichier est supprimé quand Pédale Vite se termine, normalement ou par Ctrl + C. Cependant en cas de crash, le fichier n’est pas effacé et Pédale Vite se termine immédiatement en affichant :

Pedale Vite is already running!

Il suffit de le supprimer manuellement :

sudo rm /var/lock/pedalevite-unique

##### Au démarrage, la mise à jour de l’EEPROM du RPi4 échoue

Ce problème peut arriver pendant les démarrages qui suivent une mise à jour du système. La cause de l’erreur est le fonctionnement en lecture seule du système de fichiers. Pour y remédier, il suffit de passer le système en lecture-écriture et de forcer la mise à jour :

sudo mount -o remount,ro /
sudo mount -o remount,ro /boot
sudo systemctl restart rpi-eeprom-update.service

On peut vérifier que l’opération s’est bien passée :

sudo systemctl status rpi-eeprom-update.service

##### La date n’est pas mise à jour quand la machine est connectée à internet

Quand bien même correctement configuré, timesyncd peut avoir des difficultés à se connecter à un serveurs NTP. Cela peut arriver après une mise à jour. Commencer par passer le disque en lecture/écriture :

sudo mount -o remount,rw /

Vérifier les paramètres de synchronisation de la date avec la commande suivante :

timedatectl status

NTP service doit être sur active. Si ce n’est pas le cas, tapez :

sudo timedatectl set-ntp 1

Revérifier en répétant la commande d’avant. Dans tous les cas, il est possible que System clock synchronized soit coincé sur no, ce qui indique un problème d’accès aux serveurs NTP. Dans ce cas :

timedatectl timesync-status

indique :

       Server: (null) (3.debian.pool.ntp.org)
Poll interval: 0 (min: 32s; max 34min 8s)
 Packet count: 0

Cela peut venir d’un problème avec les serveurs DNS (par exemple ceux attribués par défaut par le fournisseur d’accès internet) qui ne résolvent pas les adresses de serveurs NTP, pour je ne sais quelles raisons. On peut essayer de fixer d’autres DNS explicitement:

sudo rm /etc/resolv.conf
sudo nano /etc/resolv.conf

Ajouter les lignes suivantes. Vous pouvez y mettre n’importe quelle adresse de serveur DNS qui fonctionne :

domain home
nameserver 80.67.169.12
nameserver 80.67.169.40

Redémarrer la machine ou seulement les services adéquats.

Note importante : il peut être nécessaire de refaire cette opération après une mise à jour du système.

##### Le son clique ou les canaux s’inversent régulièrement

Il s’agit probablement d’un problème lié à la répartition du temps pour les threads temps-réels. Enter les commandes suivantes et examiner leur résultat :

cat /proc/sys/kernel/sched_rt_period_us
cat /proc/sys/kernel/sched_rt_runtime_us

La valeur de runtime devrait être égale à celle de period, ou alors -1. Si ce n’est pas le cas, exécuter la commande suivante :

echo -1 | sudo tee /proc/sys/kernel/sched_rt_runtime_us > /dev/null

### Code source

Bien que le matériel tienne une place de choix dans Pédale Vite, il s’agit quand même essentiellement d’un projet logiciel. Cette partie décrit succintement l’architecture du programme ainsi que ce qu’il faut savoir pour l’adapter facilement à des modifications du matériel. Pour mettre à jour le code depuis le dépôt Git :

cd ~/Documents/pedalevite
git pull

Sans oublier auparavant de passer le système en lecture-écriture avec :

~/fs-rw.sh

#### Compilation

Le logiciel est écrit en C++. Le compilateur doit supporter C++14 au minimum. Les fichiers de projet se trouvent dans le répertoire pedalevite/build.

##### Linux

Le sous-répertoire unix contient ce qu’il faut pour compiler sur le Pi et à destination du Pi. Makefile.am est le fichier à modifier pour ajouter les fichiers source. configure-v2-debug et configure-v2-release permettent de choisir la configuration de compilation. Un coup de make -j4 recompile le projet. make check -j4 permet de recompiler en plus le programme des tests unitaires (à configurer auparavant). Voir aussi les instructions d’installation logicielle.

##### Windows

win contient les projets pour Visual Studio 2019. Les sources sont divisées en plusieurs catégories :

- mfxlib est un projet regroupant la plupart des sources sous forme de bibliothèque statique. C’est une entité partagée entre les autres projets.
- pedalevite est un programme émulant le pédalier avec une carte son ASIO, le clavier et l’écran de l’ordinateur. Ce programme est de loin la manière la plus simple de modifier et tester le logiciel de Pédale Vite.
- test contient quelques tests unitaires de classes ou de fonctionnalités diverses.

Ces trois projets sont intégrés dans la solution pedalevite.sln.

Si la carte son de votre machine n’a pas de drivers ASIO, il est tout à fait possible de faire tourner ASIO4ALL. Par défaut les canaux d’entrée de l’émulateur Pédale Vite sont les numéros 3 et 4 (ce sont les entrées niveau instrument de ma carte). Il vous faudra probablement les changer en modifiant la valeur de chn_idx_in vers la fin de pedalevite/src/main.cpp :

#elif (MAIN_API == MAIN_API_ASIO)
	mfx::adrv::DAsio  snd_drv;
	chn_idx_in = 2;
#else

L’émulation utilise les touches suivantes :

A Z E R T Y ou Q W E R T Y | Pédales 0 à 5, rangée du haut
Q S D F G H ou A S D F G H | Pédales 6 à 11, rangée du bas
0 1 2… 8 9 du pavé numérique | Différentes valeurs pour la pédale d’expression 0
1 2, 3 4, … …, 9 0 | −1 et +1 des 5 codeurs incrémentaux
W X C ou Z X C et V B N | −1, +1 et bouton des 2 codeurs incrémentaux de navigation
Return | Select de l’interface d’utilisation
Esc | Esc de l’interface d’utilisation
Flèches directionnelles | Flèches de l’interface d’utilisation
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

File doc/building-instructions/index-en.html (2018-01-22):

# Pédale Vite — Building instructions

## Table of content

1. Introduction
2. Required materials
  1. Drawings
  2. Materials
  3. Tools
3. Step-by-step building
  1. Enclosure
  2. Electronics
  3. Assembly
4. Software setup
  1. Preparing the system
  2. Startup and base configuration
  3. System update
  4. Installing the audio interface
  5. Software dependencies
  6. Installing Pédale Vite
  7. Pédale Vite autostart
  8. Boot time optimisation
  9. NOOBS removal
  10. Read-only operating system and other optimisations
5. Maintenance
  1. Tests and troubleshooting
  2. Source code
6. Possible improvements and variations
7. Version history

## I. Introduction

Pédale Vite is a DIY (“do it yourself”) multi-effect pedalboard for guitar and bass. This manual decribes how to build it and install all required components.

I want to make it clear, this project is within reach of everyone. One does not need to be a DIY genius. One does not need to be dexterous. No specific ability is required. All used skills (soldering, drilling…) are easy and quick to learn.

However the realisation requires a significant amount of work, count about ten days of work. This is approximately the time I’ve spend to build Pédale Vite. And I’m far from being well organised and dexterous. I’m pretty sure seasoned people could halve this time without hassle.
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

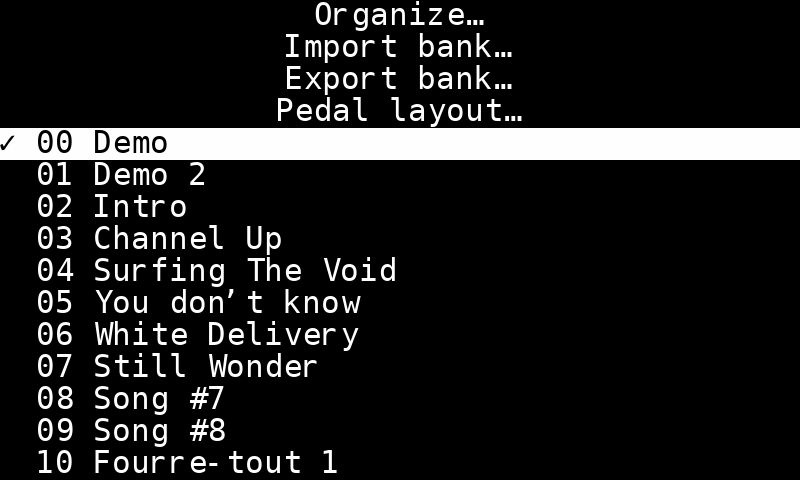
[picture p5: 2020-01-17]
doc/user-manual/bank-menu.png

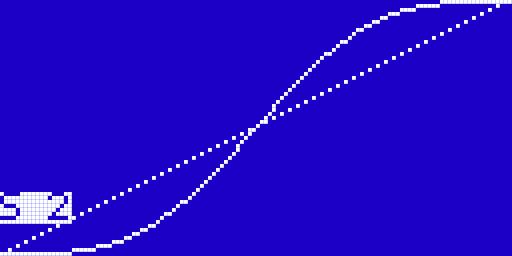
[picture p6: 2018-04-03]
doc/v1/user-manual/control-edit-curve.png

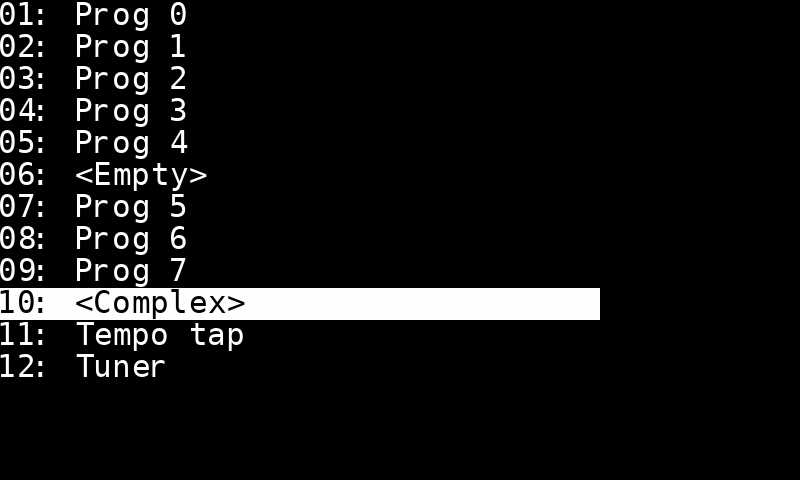
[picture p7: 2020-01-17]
doc/user-manual/pedalboard-layout.png

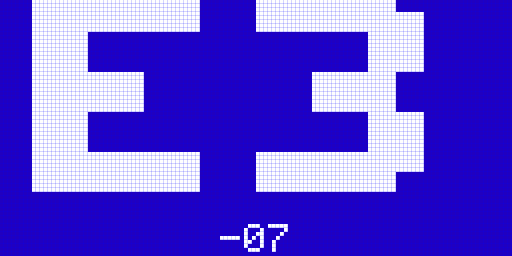
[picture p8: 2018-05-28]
doc/v1/user-manual/tuner-note.png

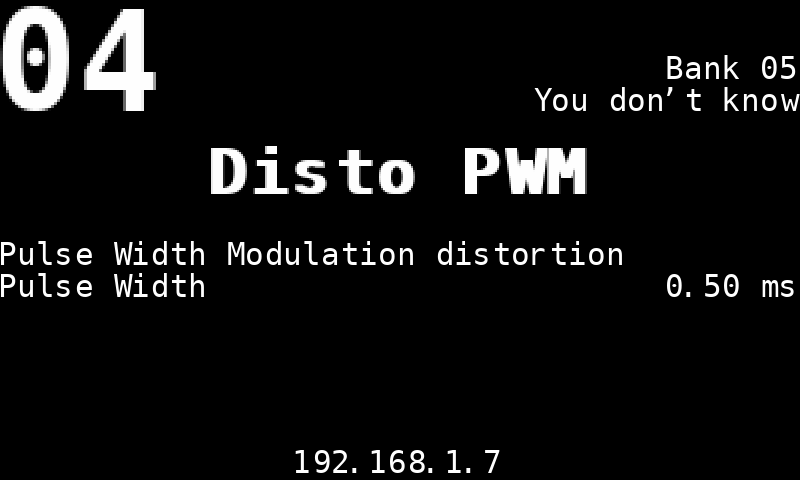
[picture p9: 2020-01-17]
doc/user-manual/prog-cur.png

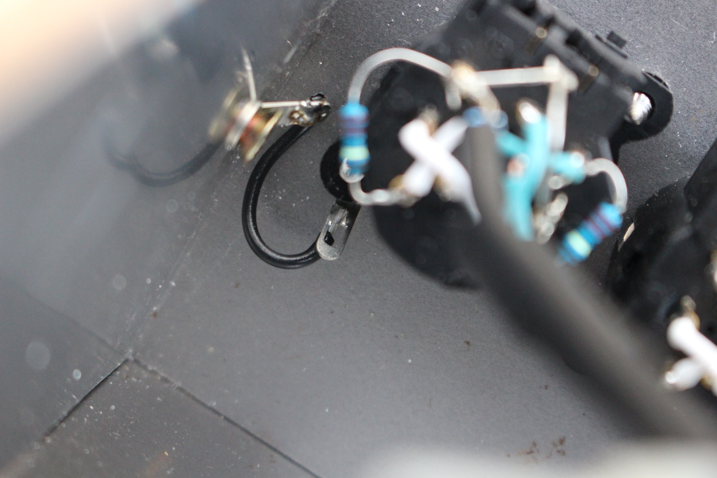
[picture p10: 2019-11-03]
doc/building-instructions/enclosure-shielding-1.jpg

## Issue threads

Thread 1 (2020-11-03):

Onset Detector 2 is currently disabled because not so good

mikelange49, 2020-11-03:
Hi Eleonore.

Congrats for your hard work, looks very impressive !

I'm a plugin developer and I'm interessed in the time-based method from Luca Turchet's "Hard Real-Time Onset Detection of Percussive Sounds".

I'd like to know why you disabled it ("because not so good").

Thanks.
Mickael

EleonoreMizo, 2020-11-08:
Hi mikelange49,

Actually I’m quite disappointed with all the onset detectors I tried so far (there are a few other ones I didn’t commit). They miss a stroke here and there, or emit false positives. I haven’t tried much the spectral-based ones because of the additional latency and much higher CPU load. Only the first OnsetDetect in the Pedale Vite effect list gives almost usable results. Maybe the other algorithms require an accurate tuning to give their best, but this is problematic as I want to use them with a few different instruments (guitars and bass). Or perhaps they are designed for drums or general-purpose use, and not specifically for plucked string instruments. I tried the time-based Luca Truchet’s algorithm (not the spectral part, I don’t need the exact onset location at the moment) with the numerical constants given in the article and tried to refine the settings, but couldn’t find something working really better than the first OnsetDetect. Maybe I should give it another try.

mikelange49, 2020-11-08:
Hey thanks a lot for your response.
I have the same problem.
Let me know if you find something better...
Cheers

Le dim. 8 nov. 2020 à 10:02, EleonoreMizo <notifications@github.com> a
écrit :

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

mikelange49, 2020-11-20:
Hey Eleonore, me again...

I've finally built your pv_osdet2 as a VST plugin.
But when I open it in Reaper :

- first I get this error :

[image: image.png]

- I click Retry, then after a while, I get this (the parameters seem to
have no name)

[image: image.png]

then the plugin doesn't seem to run (but I'm not sure).

I put a breakpoint on OnsetDetect2::do_process_block, attach Visual Studio
to Reaper, but I never hit it.

Any ideas ?

Thanks

Le dim. 8 nov. 2020 à 10:51, Mickael BAUDOUIN <mickael.baudouin@gmail.com>
a écrit :

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

EleonoreMizo, 2020-11-20:
Hmm… I think it comes from the VST wrapper. I think I haven’t tested it with effects using only control signals as output yet. I bet it will give you the same issue with `pv_osdet`. I’ll check this and try to fix it soon.

EleonoreMizo, 2020-11-20:
Fixed in 672fb47b07c44cc085048584415426c61475f8c9

mikelange49, 2020-11-22:
Thanks !
It works !
Here's a paper that might interest you on Onset Detection for Guitars and
Bass'
https://core.ac.uk/download/pdf/45290303.pdf

Regards.
PS are you french ? I am...
Please feel free to write me at mickael.baudouin@gmail.com

Le ven. 20 nov. 2020 à 18:09, EleonoreMizo <notifications@github.com> a
écrit :

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

EleonoreMizo, 2020-12-01:
Oui je le suis :) Cet article, que je n’ai que survolé pour l’instant, m’a l’air intéressant, merci beaucoup. Cependant je ne sais pas du tout à quel point il est adapté à du temps réel puisqu’il semble faire la détection dans le domaine spectral. En tout cas, je mets ça sur le coin de la table et je m’y plongerai en détail un peu plus tard, quand j’aurai un moment à y consacrer.

mikelange49, 2020-12-01:
Oui, en effet, mais je pense qu'on peut le mixer avec l'algorithme
Time-based de Lucas Turchet comme indiqué dans le pseudo code page 6 de son
papier.
Comme ça on a le meilleur des deux mondes. Un algorithme time-based pour
détecter les onsets au plus tôt (mais avec beaucoup de faux positifs après)
et un algorithme spectral-based pour éliminer les faux positifs ensuite
(plutôt NINOS en l'occurrence pour la guitare).
C'est ce que je suis en train d'essayer de faire en Juce dans mon plugin.
Je te tiendrai au courant si ça t'intéresse.
Bonne soirée.

Le mar. 1 déc. 2020 à 09:31, EleonoreMizo <notifications@github.com> a
écrit :

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

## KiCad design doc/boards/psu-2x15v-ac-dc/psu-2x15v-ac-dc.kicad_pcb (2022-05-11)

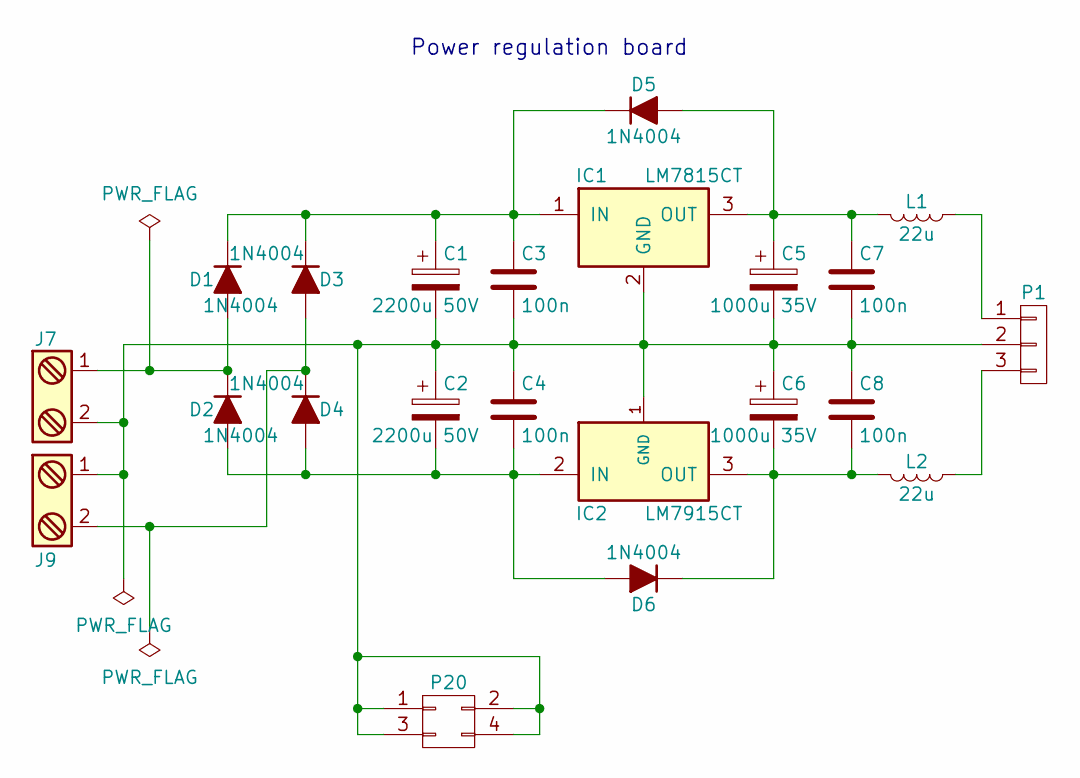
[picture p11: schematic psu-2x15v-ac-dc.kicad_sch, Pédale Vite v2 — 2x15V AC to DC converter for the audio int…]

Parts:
C1, C2: 2200u 50V; CP_Radial_D18.0mm_P7.50mm
C3, C4, C7, C8: 100n; C_Disc_D3.4mm_W2.1mm_P2.50mm
C5, C6: 1000u 35V; CP_Radial_D12.5mm_P5.00mm
D1, D2, D3, D4, D5, D6: 1N4004; D_DO-41_SOD81_P7.62mm_Horizontal
IC1: LM7815CT; TO-220_Vertical
IC2: LM7915CT; TO-220_Vertical
J7, J9: Screw_Terminal_1x02; TerminalBlock_Pheonix_MKDS1.5-2pol
L1, L2: 22u; Neosid_Inductor_Sd8
P1: CONN_01X03; Molex_KK-6410-03_03x2.54mm_Straight
P20: CONN_02X02; Pin_Header_Straight_2x02_Pitch2.54mm

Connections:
unnamed: C1.1, C3.1, D1.1 (K), D3.1 (K), D5.1 (K), IC1.1 (IN)
unnamed: C1.2, C2.1, C3.2, C4.1, C5.2, C6.1, C7.2, C8.1, IC1.2 (GND), IC2.1 (GND), J7.2, J9.1, P1.2, P20.1, P20.2, P20.3, P20.4
unnamed: C2.2, C4.2, D2.2 (A), D4.2 (A), D6.2 (A), IC2.2 (IN)
unnamed: C5.1, C7.1, D5.2 (A), IC1.3 (OUT), L1.2
unnamed: C6.2, C8.2, D6.1 (K), IC2.3 (OUT), L2.2
unnamed: D1.2 (A), D2.1 (K), J7.1
unnamed: D3.2 (A), D4.1 (K), J9.2
unnamed: L1.1, P1.1
unnamed: L2.1, P1.3

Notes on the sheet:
Power regulation board

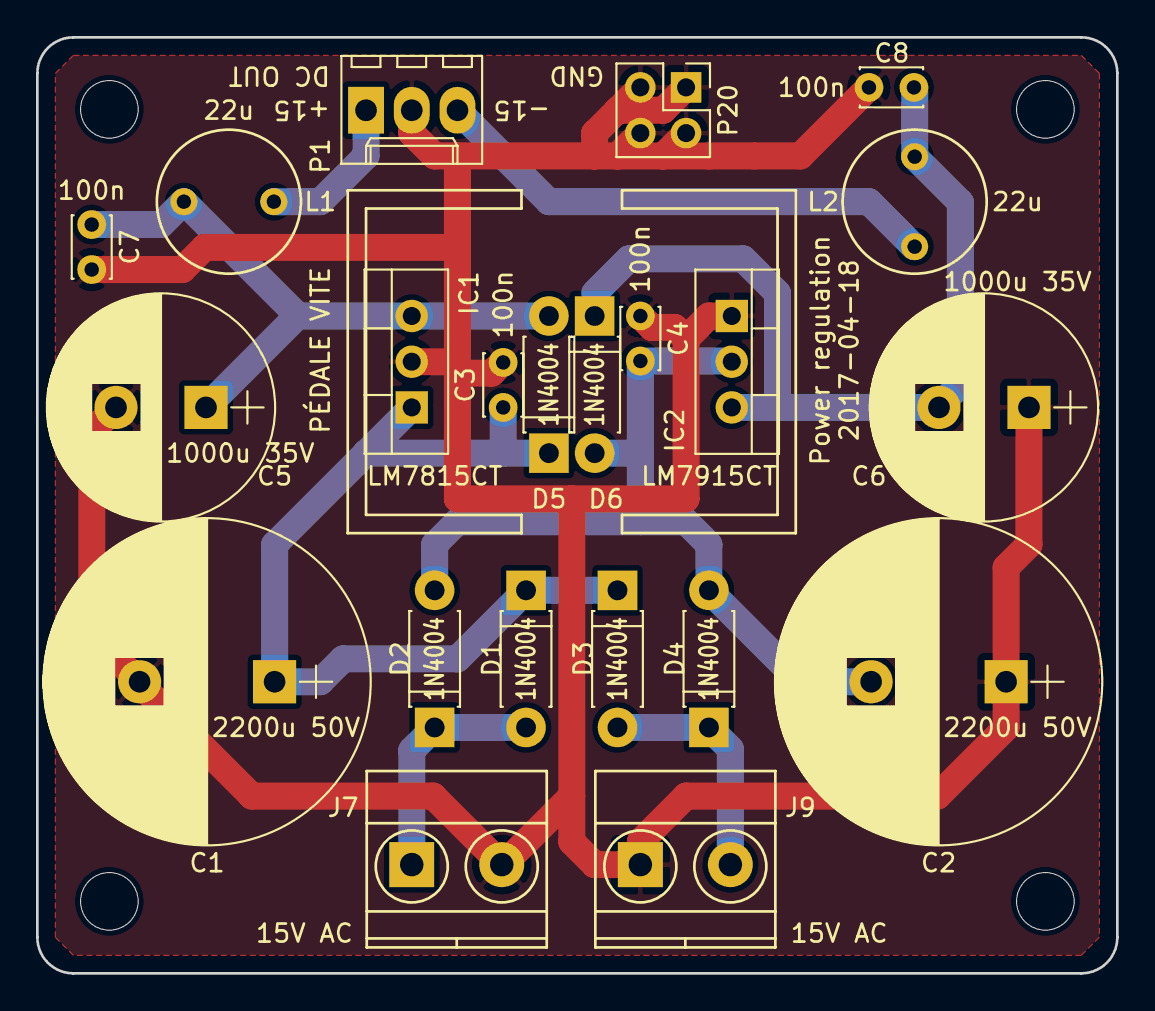
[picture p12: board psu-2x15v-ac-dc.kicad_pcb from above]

Board: 2 copper layers, 60.0 x 52.0 mm, 22 parts (0 on the bottom side), 9 nets.

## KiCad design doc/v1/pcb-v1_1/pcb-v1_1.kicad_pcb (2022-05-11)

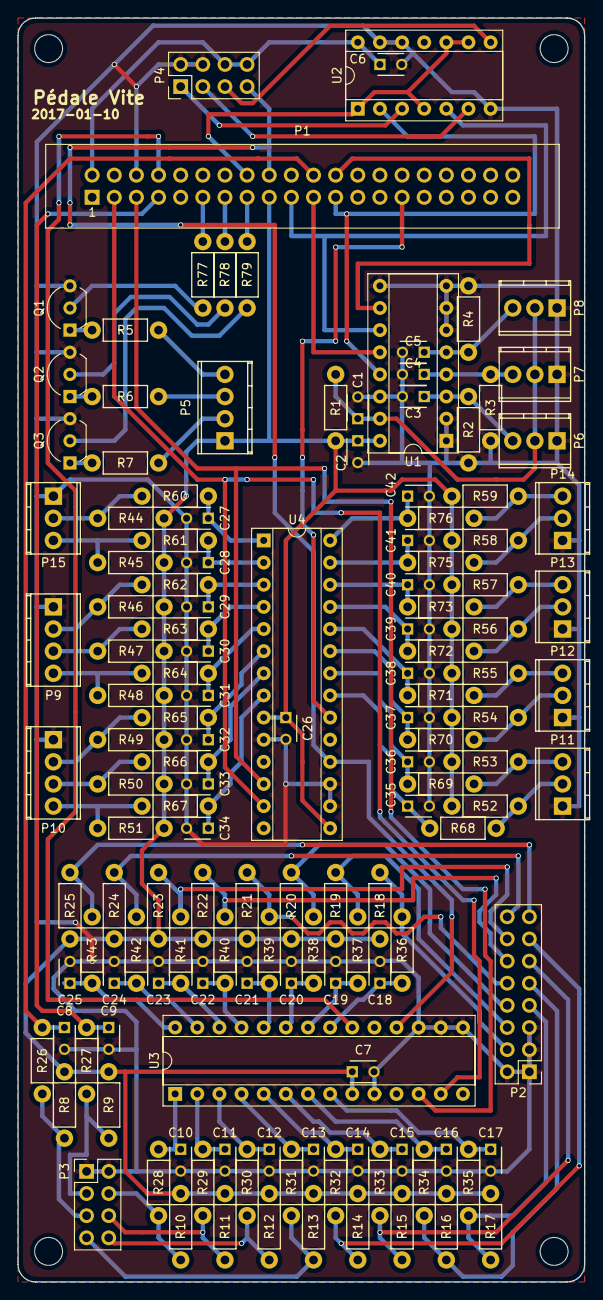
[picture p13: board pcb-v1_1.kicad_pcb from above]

Board: 2 copper layers, 65.0 x 145.0 mm, 142 parts (0 on the bottom side), 100 nets.

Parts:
C1, C2: 1u; C_Disc_D3_P2.5
C3, C4, C5, C6, C7, C8, C9, C10, C11, C12, C13, C14, C15, C16, C17, C18, C19, C20, C21, C22, C23, C24, C25, C26, C27, C28, C29, C30, C31, C32, C33, C34, C35, C36, C37, C38, C39, C40, C41, C42: 100n; C_Disc_D3_P2.5
P1: Raspberry_Pi_2_3; IDC_Header_Straight_40pins
P2: CONN_02X08; Pin_Header_Straight_2x08_Pitch2.54mm
P3, P4: CONN_02X04; Pin_Header_Straight_2x04_Pitch2.54mm
P5, P9, P10: CONN_01X04; TerminalBlock_Pheonix_MPT-2.54mm_4pol
P6, P7, P8, P11, P12, P13, P14, P15: CONN_01X03; TerminalBlock_Pheonix_MPT-2.54mm_3pol
Q1, Q2, Q3: BC547; TO-92_Inline_Wide
R1: 1k5; Resistor_Horizontal_RM7mm
R2, R3, R4: 1M; Resistor_Horizontal_RM7mm
R5, R7: 56; Resistor_Horizontal_RM7mm
R6: 39; Resistor_Horizontal_RM7mm
R8, R9, R10, R11, R12, R13, R14, R15, R16, R17, R18, R19, R20, R21, R22, R23, R24, R25, R26, R27, R28, R29, R30, R31, R32, R33, R34, R35, R36, R37, R38, R39, R40, R41, R42, R43, R44, R45, R46, R47, R48, R49, R50, R51, R52, R53, R54, R55, R56, R57, R58, R59, R60, R61, R62, R63, R64, R65, R66, R67, R68, R69, R70, R71, R72, R73, R75, R76, R77, R78, R79: 10k; Resistor_Horizontal_RM7mm
U1: MCP3008; DIP-16_W7.62mm_Socket
U2: 74LS08; DIP-14_W7.62mm_Socket
U3, U4: MCP23017; DIP-28_W7.62mm_Socket

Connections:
+3V3: C2.1, C7.1, C26.1, P1.17, P5.1, R1.1, R8.1, R9.1, R10.1, R11.1, R12.1, R13.1, R14.1, R15.1, R16.1, R17.1, R18.1, R19.1, R20.1, R21.1, R22.1, R23.1, R24.1, R25.1, R44.1, R45.1, R46.1, R47.1, R48.1, R49.1, R50.1, R51.1, R52.1, R53.1, R54.1, R55.1, R56.1, R57.1, R58.1, R59.1, U1.16, U3.9, U4.9, U4.15
+5V: C6.1, P1.2, P4.6, P4.8, U2.14
Escape: C8.1, P1.22, R26.1
GND: C1.2, C2.2, C3.2, C4.2, C5.2, C6.2, C7.2, C8.2, C9.2, C10.2, C11.2, C12.2, C13.2, C14.2, C15.2, C16.2, C17.2, C18.2, C19.2, C20.2, C21.2, C22.2, C23.2, C24.2, C25.2, C26.2, C27.2, C28.2, C29.2, C30.2, C31.2, C32.2, C33.2, C34.2, C35.2, C36.2, C37.2, C38.2, C39.2, C40.2, C41.2, C42.2, P1.6, P2.1, P2.2, P2.3, P2.5, P3.1, P3.2, P4.2, P4.4, P6.1, P7.1, P8.1, P9.1, P10.1, P11.1, P12.1, P13.1, P14.1, P15.1, Q1.3, Q2.3, Q3.3, R2.2, R3.2, R4.2, U1.1, U1.2, U1.6, U1.7, U1.8, U1.9, U1.14, U2.7, U2.12, U2.13, U3.10, U3.15, U3.16, U3.17, U4.10, U4.16, U4.17
I2C_SCL: P1.5, U3.12, U4.12
I2C_SDA: P1.3, U3.13, U4.13
Int1: P1.8, U3.20
Int2: P1.29, U4.20
LED_0R: P1.11, R77.2
LED_1G: P1.13, R78.2
LED_2R: P1.15, R79.2
unnamed: C1.1, P6.2, P7.2, P8.2, R1.2, U1.15
unnamed: C3.1, P6.3, R2.1, U1.3
unnamed: C4.1, P7.3, R3.1, U1.4
unnamed: C5.1, P8.3, R4.1, U1.5
unnamed: C10.1, R28.1, U3.1
unnamed: C11.1, R29.1, U3.2
unnamed: C12.1, R30.1, U3.3
unnamed: C13.1, R31.1, U3.4
unnamed: C14.1, R32.1, U3.5
unnamed: C15.1, R33.1, U3.6
unnamed: C16.1, R34.1, U3.7
unnamed: C17.1, R35.1, U3.8
unnamed: C18.1, R36.1, U3.21
unnamed: C19.1, R37.1, U3.22
unnamed: C20.1, R38.1, U3.23
unnamed: C21.1, R39.1, U3.24
unnamed: C22.1, R40.1, U3.25
unnamed: C23.1, R41.1, U3.26
unnamed: C24.1, R42.1, U3.27
unnamed: C25.1, R43.1, U3.28
unnamed: C27.1, R60.1, U4.1
unnamed: C28.1, R61.1, U4.2
unnamed: C29.1, R62.1, U4.3
unnamed: C30.1, R63.1, U4.4
unnamed: C31.1, R64.1, U4.5
unnamed: C32.1, R65.1, U4.6
unnamed: C33.1, R66.1, U4.7
unnamed: C34.1, R67.1, U4.8
unnamed: C35.1, R68.1, U4.21
unnamed: C36.1, R69.1, U4.22
unnamed: C37.1, R70.1, U4.23
unnamed: C38.1, R71.1, U4.24
unnamed: C39.1, R72.1, U4.25
unnamed: C40.1, R73.1, U4.26
unnamed: C41.1, R75.1, U4.27
unnamed: C42.1, R76.1, U4.28
unnamed: P2.4, R18.2, R36.2
unnamed: P2.6, R19.2, R37.2
unnamed: P2.7, R17.2, R35.2
unnamed: P2.8, R20.2, R38.2
unnamed: P2.9, R16.2, R34.2
unnamed: P2.10, R21.2, R39.2
unnamed: P2.11, R15.2, R33.2
unnamed: P2.12, R22.2, R40.2
unnamed: P2.13, R14.2, R32.2
unnamed: P2.14, R23.2, R41.2
unnamed: P2.15, R25.2, R43.2
unnamed: P2.16, R24.2, R42.2
unnamed: P3.3, R9.2, R27.2
unnamed: P3.4, R10.2, R28.2
unnamed: P3.5, R8.2, R26.2
unnamed: P3.6, R11.2, R29.2
unnamed: P3.7, R13.2, R31.2
unnamed: P3.8, R12.2, R30.2
unnamed: P4.1, U2.3
unnamed: P4.3, U2.6
unnamed: P4.5, U2.8
unnamed: P5.2, R7.1
unnamed: P5.3, R6.1
unnamed: P5.4, R5.1
unnamed: P9.2, R46.2, R62.2
unnamed: P9.3, R47.2, R63.2
unnamed: P9.4, R48.2, R64.2
unnamed: P10.2, R49.2, R65.2
unnamed: P10.3, R50.2, R66.2
unnamed: P10.4, R51.2, R67.2
unnamed: P11.2, R52.2, R68.2
unnamed: P11.3, R53.2, R69.2
unnamed: P12.2, R54.2, R70.2
unnamed: P12.3, R55.2, R71.2
unnamed: P13.2, R56.2, R72.2
unnamed: P13.3, R57.2, R73.2
unnamed: P14.2, R58.2, R75.2
unnamed: P14.3, R59.2, R76.2
unnamed: P15.2, R44.2, R60.2
unnamed: P15.3, R45.2, R61.2
unnamed: Q1.1, R5.2
unnamed: Q1.2, R77.1
unnamed: Q2.1, R6.2
unnamed: Q2.2, R78.1
unnamed: Q3.1, R7.2
unnamed: Q3.2, R79.1
SPI_CE0: P1.24, U1.10
SPI_MISO: P1.21, U1.12
SPI_MOSI: P1.19, U1.11, U2.5
SPI_SCLK: P1.23, U1.13, U2.2
Select: C9.1, P1.7, R27.1
~Disp_CS: P1.16, U2.1, U2.4, U2.9, U2.10
~Reset: P1.18, P4.7, U3.18, U4.18

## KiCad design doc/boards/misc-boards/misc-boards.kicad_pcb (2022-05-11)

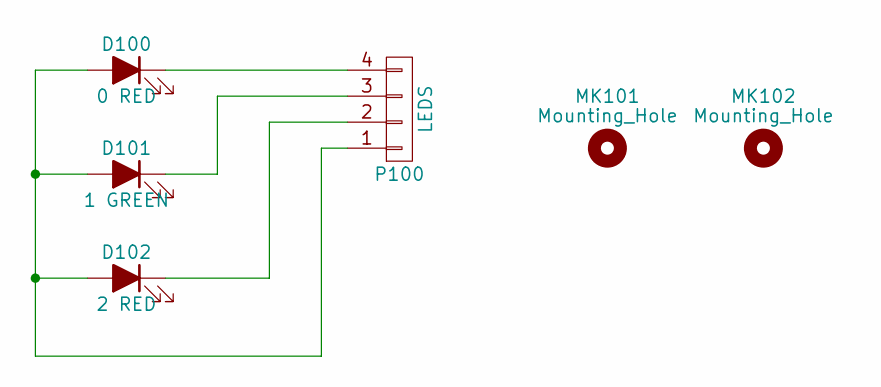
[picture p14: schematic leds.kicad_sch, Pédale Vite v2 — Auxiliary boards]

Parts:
D100: 0 RED; LED_D5.0mm
D101: 1 GREEN; LED_D5.0mm
D102: 2 RED; LED_D5.0mm
MK101, MK102: Mounting_Hole; MountingHole_3.2mm_M3
P100: LEDS; Socket_MOLEX-KK-RM2-54mm_Lock_4pin_straight

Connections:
unnamed: D100.1 (K), P100.4
unnamed: D100.2 (A), D101.2 (A), D102.2 (A), P100.1
unnamed: D101.1 (K), P100.3
unnamed: D102.1 (K), P100.2

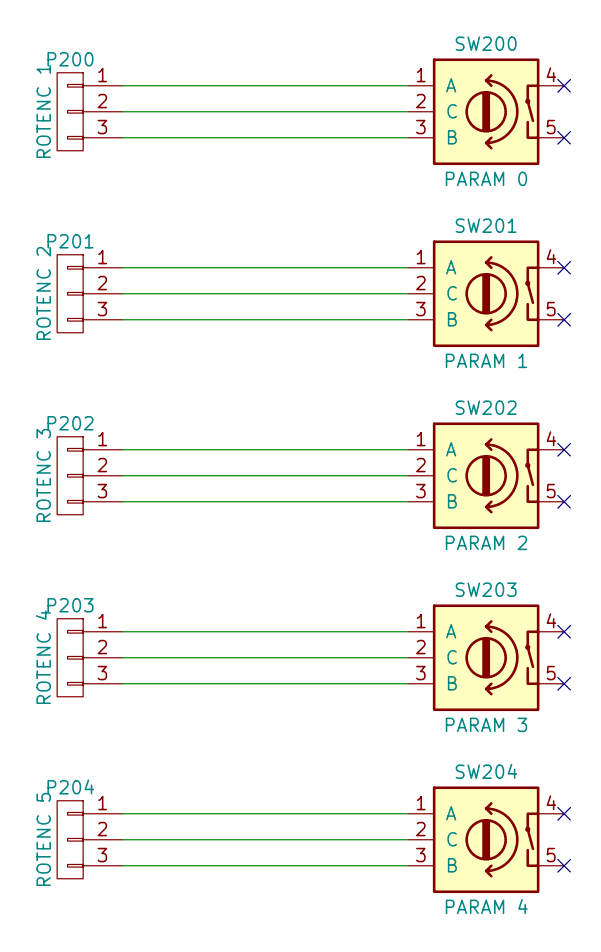
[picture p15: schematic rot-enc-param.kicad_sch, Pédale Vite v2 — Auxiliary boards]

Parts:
P200: ROTENC 1; Socket_MOLEX-KK-RM2-54mm_Lock_3pin_straight
P201: ROTENC 2; Socket_MOLEX-KK-RM2-54mm_Lock_3pin_straight
P202: ROTENC 3; Socket_MOLEX-KK-RM2-54mm_Lock_3pin_straight
P203: ROTENC 4; Socket_MOLEX-KK-RM2-54mm_Lock_3pin_straight
P204: ROTENC 5; Socket_MOLEX-KK-RM2-54mm_Lock_3pin_straight
SW200: PARAM 0; RotaryEncoder_Bourns_PEC11R-Switch_Vertical
SW201: PARAM 1; RotaryEncoder_Bourns_PEC11R-Switch_Vertical
SW202: PARAM 2; RotaryEncoder_Bourns_PEC11R-Switch_Vertical
SW203: PARAM 3; RotaryEncoder_Bourns_PEC11R-Switch_Vertical
SW204: PARAM 4; RotaryEncoder_Bourns_PEC11R-Switch_Vertical

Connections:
unnamed: P200.1, SW200.1 (A)
unnamed: P200.2, SW200.2 (C)
unnamed: P200.3, SW200.3 (B)
unnamed: P201.1, SW201.1 (A)
unnamed: P201.2, SW201.2 (C)
unnamed: P201.3, SW201.3 (B)
unnamed: P202.1, SW202.1 (A)
unnamed: P202.2, SW202.2 (C)
unnamed: P202.3, SW202.3 (B)
unnamed: P203.1, SW203.1 (A)
unnamed: P203.2, SW203.2 (C)
unnamed: P203.3, SW203.3 (B)
unnamed: P204.1, SW204.1 (A)
unnamed: P204.2, SW204.2 (C)
unnamed: P204.3, SW204.3 (B)

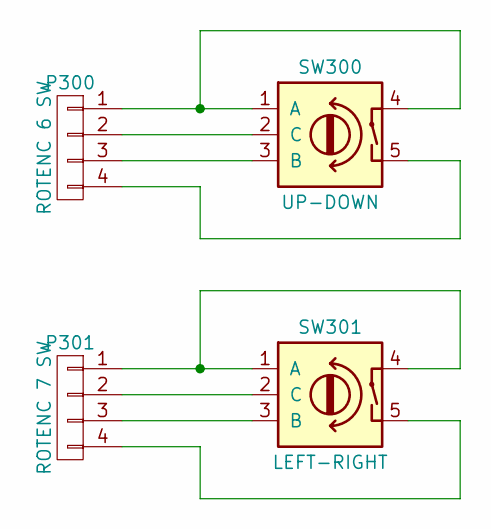
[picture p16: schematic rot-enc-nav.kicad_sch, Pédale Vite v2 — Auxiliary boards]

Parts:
P300: ROTENC 6 SW; Socket_MOLEX-KK-RM2-54mm_Lock_4pin_straight
P301: ROTENC 7 SW; Socket_MOLEX-KK-RM2-54mm_Lock_4pin_straight
SW300: UP-DOWN; RotaryEncoder_Bourns_PEC11R-Switch_Vertical
SW301: LEFT-RIGHT; RotaryEncoder_Bourns_PEC11R-Switch_Vertical

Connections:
unnamed: P300.1, SW300.1 (A), SW300.4
unnamed: P300.2, SW300.2 (C)
unnamed: P300.3, SW300.3 (B)
unnamed: P300.4, SW300.5
unnamed: P301.1, SW301.1 (A), SW301.4
unnamed: P301.2, SW301.2 (C)
unnamed: P301.3, SW301.3 (B)
unnamed: P301.4, SW301.5

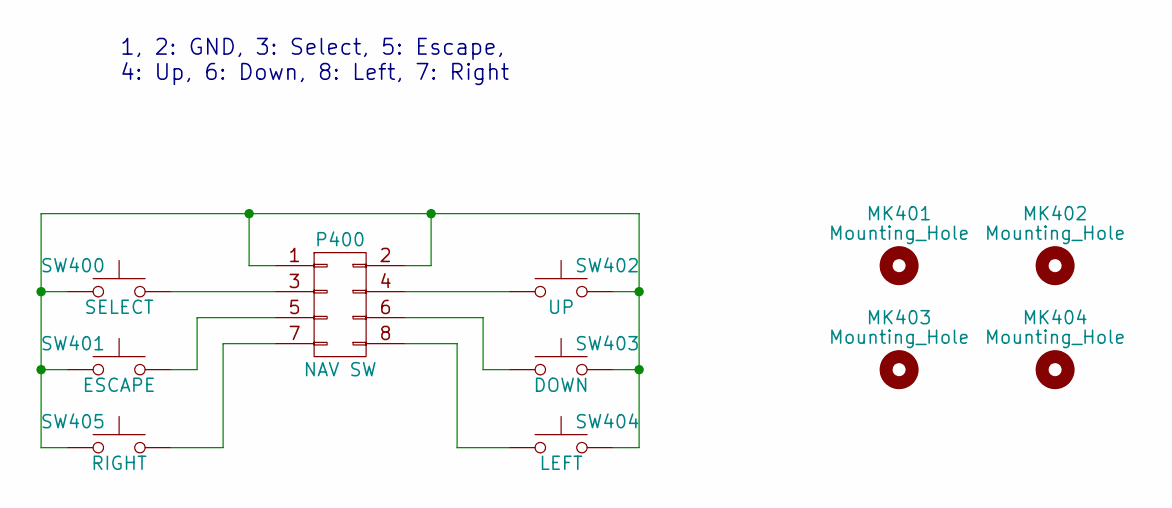
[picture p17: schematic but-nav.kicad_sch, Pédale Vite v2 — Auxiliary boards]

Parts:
MK401, MK402, MK403, MK404: Mounting_Hole; MountingHole_3.2mm_M3
P400: NAV SW; Pin_Header_Straight_2x04_Pitch2.54mm
SW400: SELECT; SW_MEC_5GTH9
SW401: ESCAPE; SW_MEC_5GTH9
SW402: UP; SW_MEC_5GTH9
SW403: DOWN; SW_MEC_5GTH9
SW404: LEFT; SW_MEC_5GTH9
SW405: RIGHT; SW_MEC_5GTH9

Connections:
unnamed: P400.1, P400.2, SW400.2, SW401.2, SW402.2, SW403.2, SW404.2, SW405.2
unnamed: P400.3, SW400.1
unnamed: P400.4, SW402.1
unnamed: P400.5, SW401.1
unnamed: P400.6, SW403.1
unnamed: P400.7, SW405.1
unnamed: P400.8, SW404.1

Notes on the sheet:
1, 2: GND, 3: Select, 5: Escape, 4: Up, 6: Down, 8: Left, 7: Right

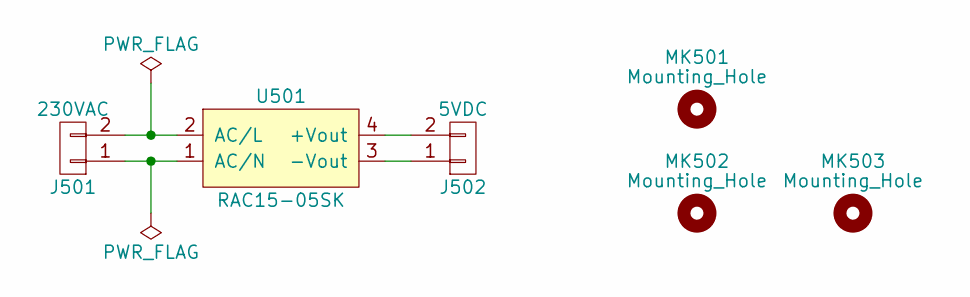
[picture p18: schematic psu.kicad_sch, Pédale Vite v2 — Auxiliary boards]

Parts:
J501: 230VAC; TerminalBlock_Altech_AK300-2_P5.00mm
J502: 5VDC; TerminalBlock_Altech_AK300-2_P5.00mm
MK501, MK502, MK503: Mounting_Hole; MountingHole_3.2mm_M3
U501: RAC15-05SK; Converter_ACDC_RECOM_RAC15-xxSK_THT

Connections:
unnamed: J501.1, U501.1 (AC/N)
unnamed: J501.2, U501.2 (AC/L)
unnamed: J502.1, U501.3 (-Vout)
unnamed: J502.2, U501.4 (+Vout)

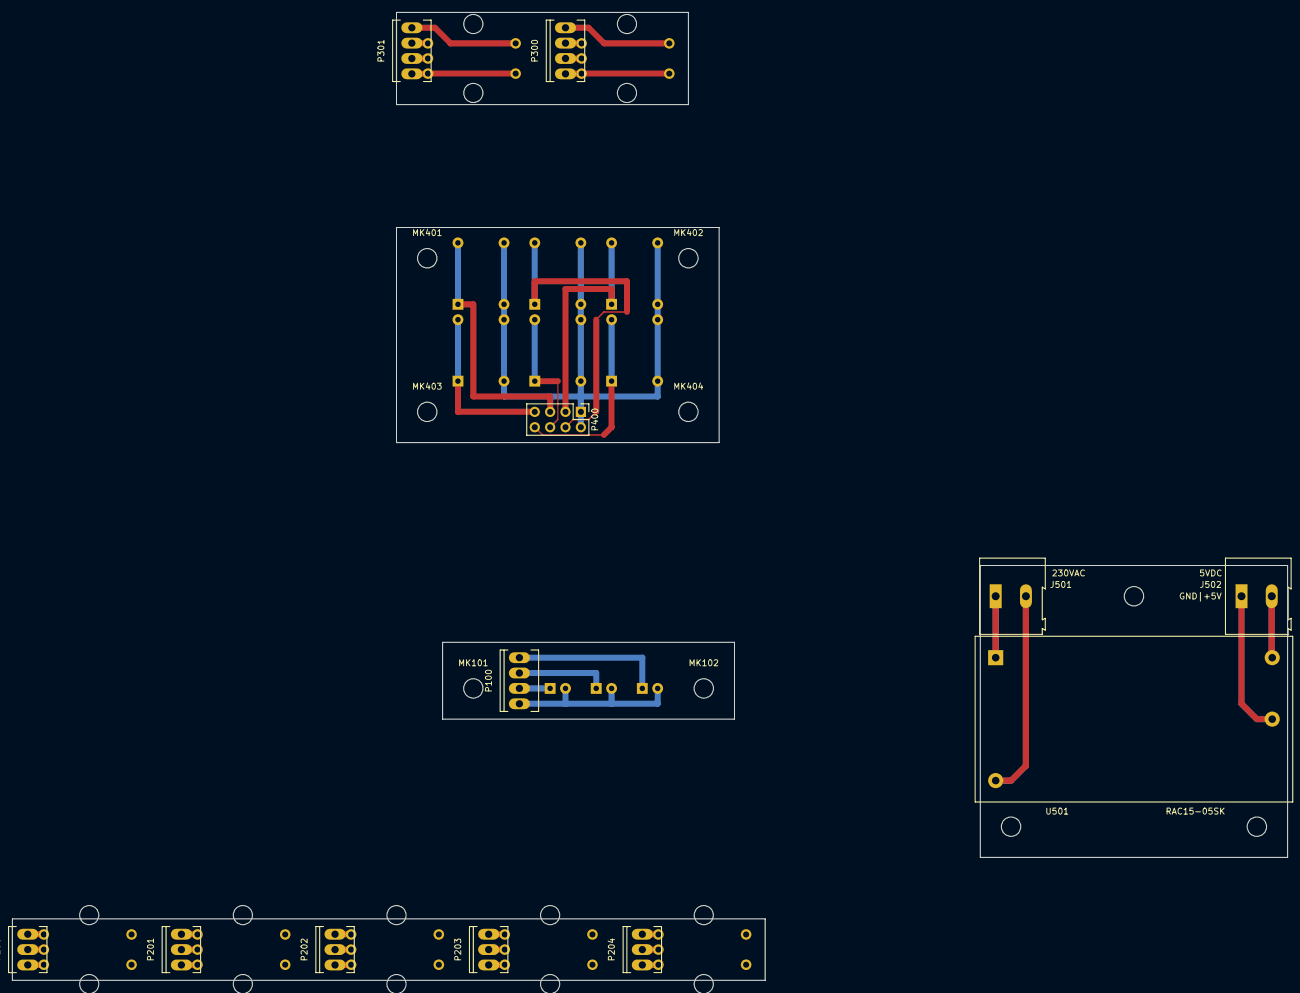
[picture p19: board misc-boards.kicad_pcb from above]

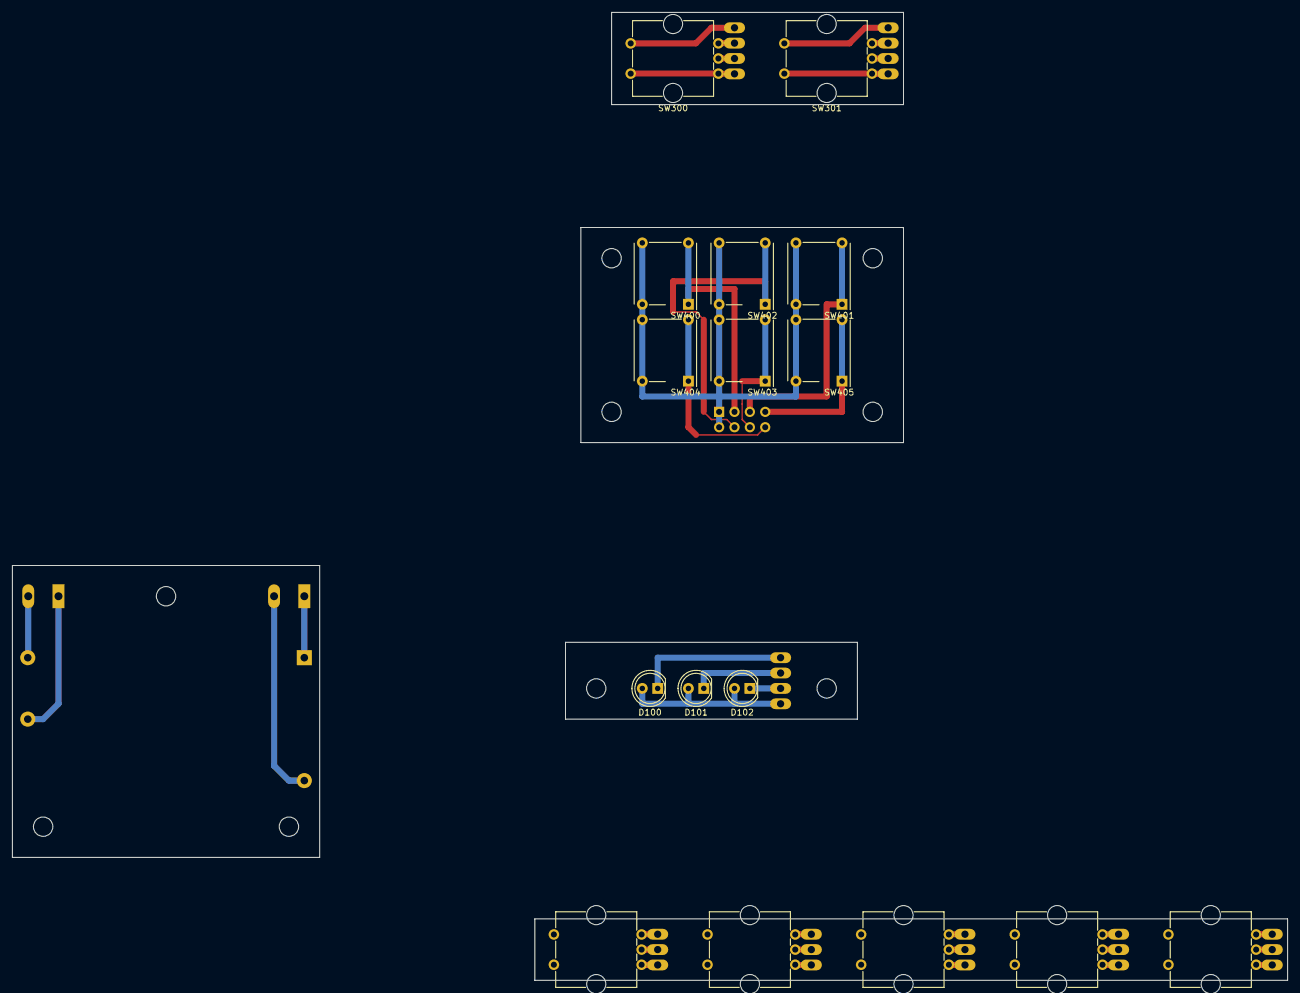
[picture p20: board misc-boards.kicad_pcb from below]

Board: 2 copper layers, 210.8 x 160.0 mm, 37 parts (16 on the bottom side), 38 nets.

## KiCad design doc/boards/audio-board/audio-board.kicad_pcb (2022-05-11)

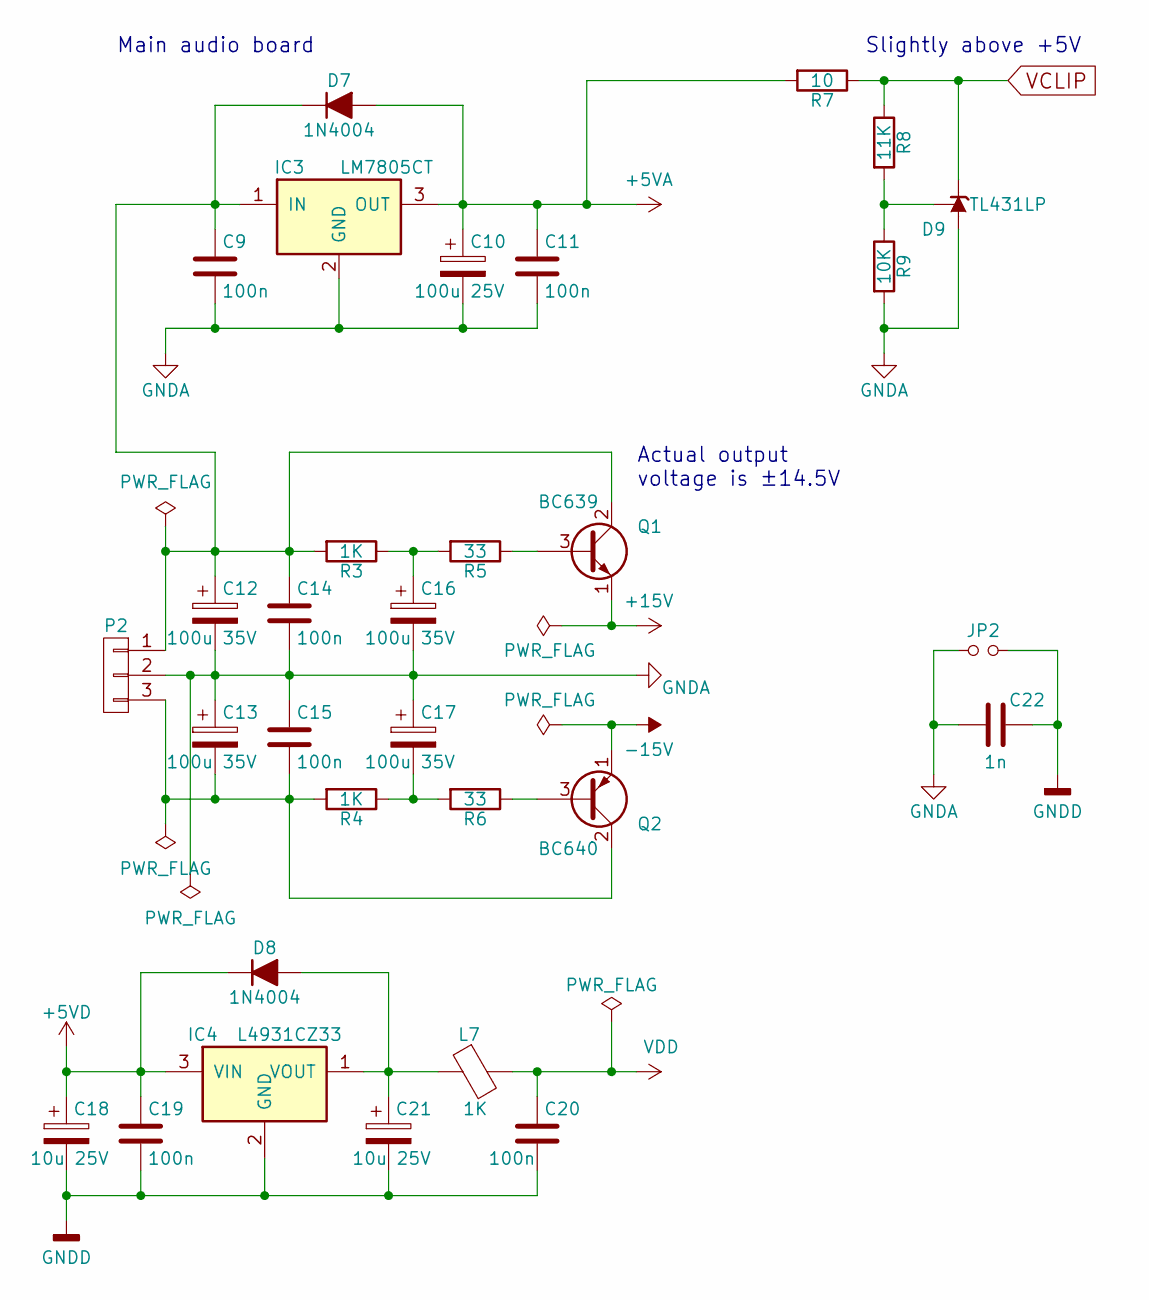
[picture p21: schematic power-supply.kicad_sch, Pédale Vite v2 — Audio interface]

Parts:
C9, C11, C14, C15, C19, C20: 100n; C_Disc_D3.4mm_W2.1mm_P2.50mm
C10: 100u 25V; CP_Radial_D6.3mm_P2.50mm
C12, C13, C16, C17: 100u 35V; CP_Radial_D8.0mm_P3.50mm
C18, C21: 10u 25V; CP_Radial_D5.0mm_P2.00mm
C22: 1n; C_Disc_D3.4mm_W2.1mm_P2.50mm
D7, D8: 1N4004; D_DO-41_SOD81_P7.62mm_Horizontal
D9: TL431LP; TO-92_Inline_Wide
IC3: LM7805CT; TO-220_Vertical
IC4: L4931CZ33; TO-92_Inline_Wide
JP2: Jumper_NO_Small; Pin_Header_Straight_1x02_Pitch2.54mm
L7: 1K; CP_Radial_Tantal_D6.0mm_P5.00mm
P2: CONN_01X03; Molex_KK-6410-03_03x2.54mm_Straight
Q1: BC639; TO-92_Inline_Wide
Q2: BC640; TO-92_Inline_Wide
R3, R4: 1K; R_Axial_DIN0207_L6.3mm_D2.5mm_P7.62mm_Horizontal
R5, R6: 33; R_Axial_DIN0207_L6.3mm_D2.5mm_P7.62mm_Horizontal
R7: 10; R_Axial_DIN0207_L6.3mm_D2.5mm_P7.62mm_Horizontal
R8: 11K; R_Axial_DIN0207_L6.3mm_D2.5mm_P7.62mm_Horizontal
R9: 10K; R_Axial_DIN0207_L6.3mm_D2.5mm_P7.62mm_Horizontal

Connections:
+5VA: C10.1, C11.1, D7.2 (A), IC3.3 (OUT), R7.2; also elsewhere on the board
+5VD: C18.1, C19.1, D8.1 (K), IC4.3 (VIN); also elsewhere on the board
-15V: Q2.1 (E); also elsewhere on the board
GNDA: C9.2, C10.2, C11.2, C12.2, C13.1, C14.2, C15.1, C16.2, C17.1, C22.2, D9.2 (A), IC3.2 (GND), JP2.1, P2.2, R9.2; also elsewhere on the board
GNDD: C18.2, C19.2, C20.2, C21.2, C22.1, IC4.2 (GND), JP2.2; also elsewhere on the board
unnamed: C9.1, C12.1, C14.1, D7.1 (K), IC3.1 (IN), P2.1, Q1.2 (C), R3.2
unnamed: C13.2, C15.2, P2.3, Q2.2 (C), R4.2
unnamed: C16.1, R3.1, R5.2
unnamed: C17.2, R4.1, R6.2
unnamed: C21.1, D8.2 (A), IC4.1 (VOUT), L7.1
unnamed: D9.1 (REF), R8.2, R9.1
unnamed: Q1.3 (B), R5.1
unnamed: Q2.3 (B), R6.1
VCLIP: D9.3 (K), R7.1, R8.1; also elsewhere on the board
VDD: C20.1, L7.2; also elsewhere on the board

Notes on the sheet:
Main audio board
Actual output voltage is ±14.5V
Slightly above +5V

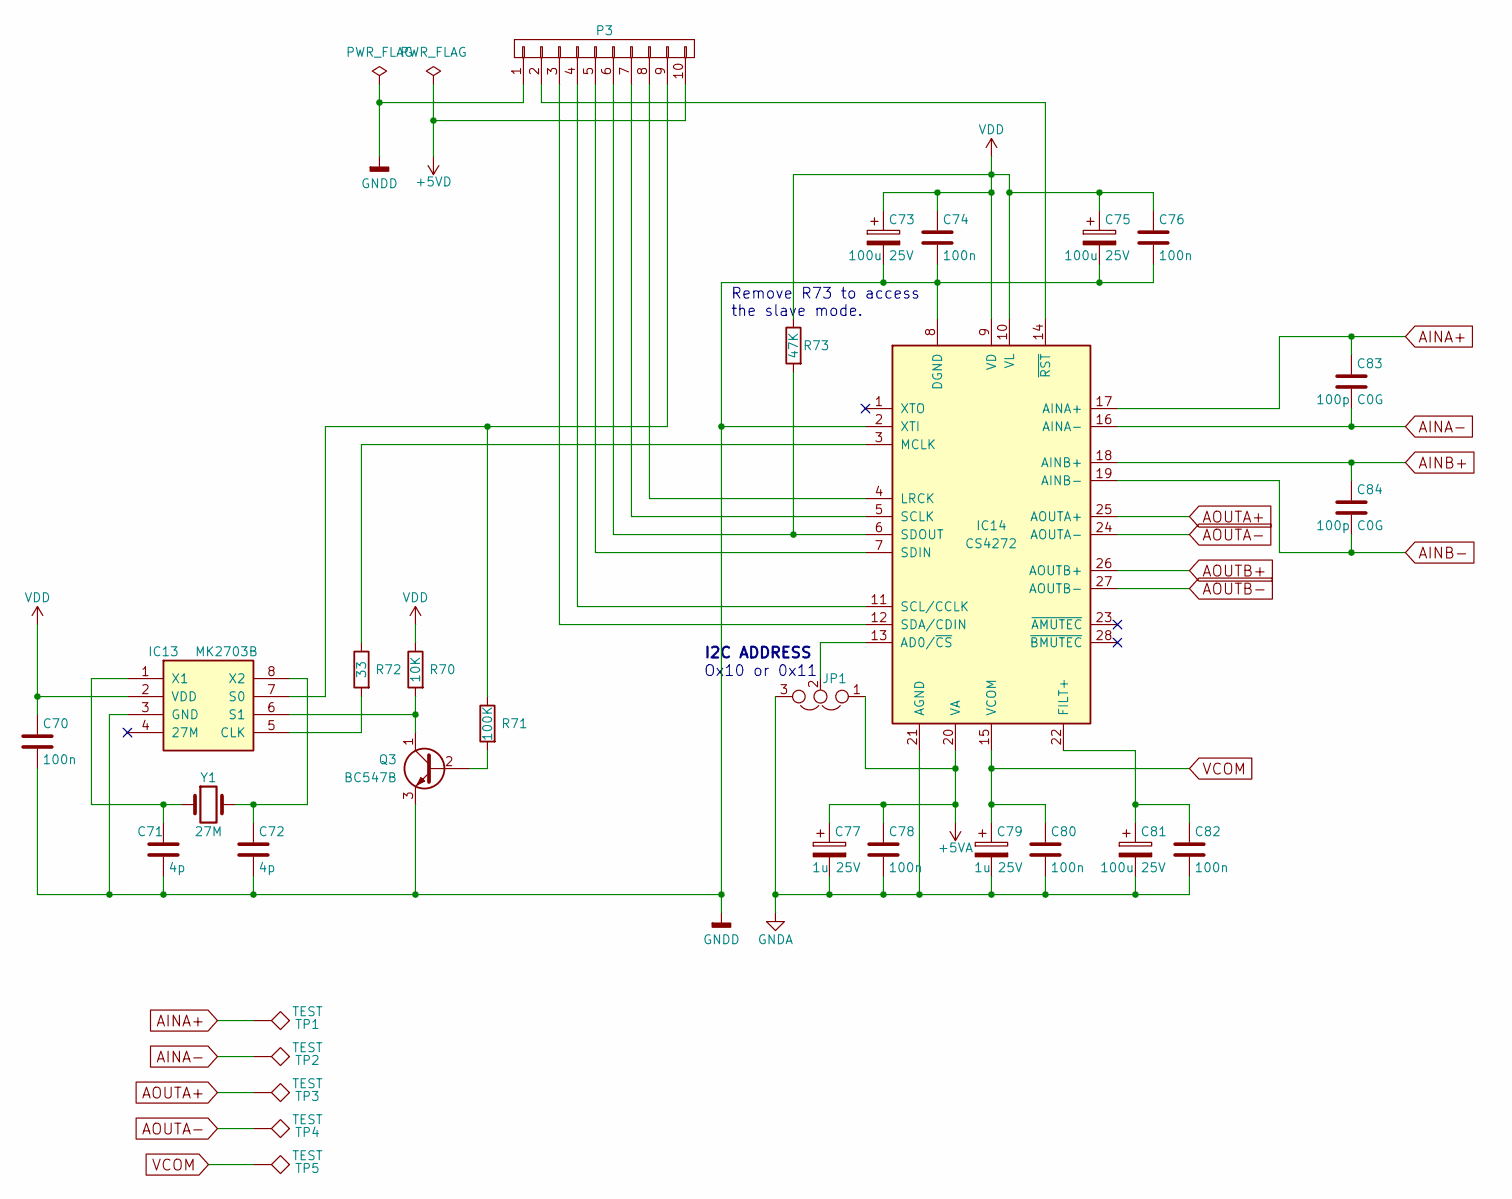
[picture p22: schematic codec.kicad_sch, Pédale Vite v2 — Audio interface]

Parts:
C70, C74, C76, C78, C80, C82: 100n; C_Disc_D3.4mm_W2.1mm_P2.50mm
C71, C72: 4p; C_Disc_D3.4mm_W2.1mm_P2.50mm
C73, C75, C81: 100u 25V; CP_Radial_D6.3mm_P2.50mm
C77, C79: 1u 25V; CP_Radial_D5.0mm_P2.00mm
C83, C84: 100p C0G; C_Disc_D3.4mm_W2.1mm_P2.50mm
IC13: MK2703B; SOIC-8_3.9x4.9mm_Pitch1.27mm
IC14: CS4272; TSSOP-28_4.4x9.7mm_Pitch0.65mm_manual_soldering
JP1: Jumper_NC_Dual; Pin_Header_Straight_1x03_Pitch2.54mm
P3: CONN_01X10; Pin_Header_Straight_1x10_Pitch2.54mm
Q3: BC547B; TO-92_Inline_Wide
R70: 10K; R_Axial_DIN0207_L6.3mm_D2.5mm_P7.62mm_Horizontal
R71: 100K; R_Axial_DIN0207_L6.3mm_D2.5mm_P7.62mm_Horizontal
R72: 33; R_Axial_DIN0207_L6.3mm_D2.5mm_P2.54mm_Vertical
R73: 47K; R_Axial_DIN0207_L6.3mm_D2.5mm_P7.62mm_Horizontal
TP1, TP2, TP3, TP4, TP5: TEST; Measurement_Point_Round-TH_Small
Y1: 27M; Crystal_HC49-U_Vertical

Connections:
+5VA: C77.1, C78.1, IC14.20 (VA), JP1.1; also elsewhere on the board
+5VD: P3.10; also elsewhere on the board
AINA+: C83.1, IC14.17 (AINA+), TP1.1; also elsewhere on the board
AINA-: C83.2, IC14.16 (AINA-), TP2.1; also elsewhere on the board
AINB+: C84.1, IC14.18 (AINB+); also elsewhere on the board
AINB-: C84.2, IC14.19 (AINB-); also elsewhere on the board
AOUTA+: IC14.25 (AOUTA+), TP3.1; also elsewhere on the board
AOUTA-: IC14.24 (AOUTA-), TP4.1; also elsewhere on the board
AOUTB+: IC14.26 (AOUTB+); also elsewhere on the board
AOUTB-: IC14.27 (AOUTB-); also elsewhere on the board
GNDA: C77.2, C78.2, C79.2, C80.2, C81.2, C82.2, IC14.21 (AGND), JP1.3; also elsewhere on the board
GNDD: C70.2, C71.2, C72.2, C73.2, C74.2, C75.2, C76.2, IC13.3 (GND), IC14.2 (XTI), IC14.8 (DGND), P3.1, Q3.3 (E); also elsewhere on the board
unnamed: C71.1, IC13.1 (X1), Y1.1
unnamed: C72.1, IC13.8 (X2), Y1.2
unnamed: C81.1, C82.1, IC14.22 (FILT+)
unnamed: IC13.5 (CLK), R72.2
unnamed: IC13.6 (S1), Q3.1 (C), R70.2
unnamed: IC13.7 (S0), P3.9, R71.1
unnamed: IC14.3 (MCLK), R72.1
unnamed: IC14.4 (LRCK), P3.8
unnamed: IC14.5 (SCLK), P3.7
unnamed: IC14.6 (SDOUT), P3.6, R73.2
unnamed: IC14.7 (SDIN), P3.5
unnamed: IC14.11 (SCL/CCLK), P3.4
unnamed: IC14.12 (SDA/CDIN), P3.3
unnamed: IC14.13 (AD0/~CS), JP1.2
unnamed: IC14.14 (~RST), P3.2
unnamed: Q3.2 (B), R71.2
VCOM: C79.1, C80.1, IC14.15 (VCOM), TP5.1; also elsewhere on the board
VDD: C70.1, C73.1, C74.1, C75.1, C76.1, IC13.2 (VDD), IC14.9 (VD), IC14.10 (VL), R70.1, R73.1; also elsewhere on the board

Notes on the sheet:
Ox10 or 0x11
I2C ADDRESS
Remove R73 to access the slave mode.

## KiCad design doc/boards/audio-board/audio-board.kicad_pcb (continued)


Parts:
C30, C31, C40, C41: 10u 50V; CP_Radial_D8.0mm_P3.50mm
C32, C33: 1n; C_Rect_L7.2mm_W4.5mm_P5.00mm_FKS2_FKP2_MKS2_MKP2
C34: 470u 25V; CP_Radial_D10.0mm_P5.00mm
C35, C36: 1u tant; CP_Radial_D5.0mm_P2.50mm
C37, C38: 10u 35V; CP_Radial_D5.0mm_P2.00mm
C39, C42, C45: 100n; C_Disc_D3.4mm_W2.1mm_P2.50mm
C43, C44, C46, C47: 1n; C_Disc_D6.0mm_W2.5mm_P5.00mm
C48: 3n3; C_Disc_D6.0mm_W2.5mm_P5.00mm
D10, D11, D12, D13, D18, D19, D20, D21: 1N4448; D_DO-35_SOD27_P7.62mm_Horizontal
D14, D15, D16, D17: 1N5817; D_DO-35_SOD27_P7.62mm_Horizontal
IC5: INA103; DIP-16_W7.62mm_Socket
IC6, IC7, IC8: NE5532; DIP-8_W7.62mm_Socket
L3, L4: 1u2; R_Axial_DIN0309_L9.0mm_D3.2mm_P5.08mm_Vertical
R10, R11, R31, R33: 2K2; R_Axial_DIN0207_L6.3mm_D2.5mm_P7.62mm_Horizontal
R12, R13: 15; R_Axial_DIN0207_L6.3mm_D2.5mm_P7.62mm_Horizontal
R14, R15: 50; R_Axial_DIN0207_L6.3mm_D2.5mm_P7.62mm_Horizontal
R16: 604; R_Axial_DIN0207_L6.3mm_D2.5mm_P7.62mm_Horizontal
R17, R18: 100K; R_Axial_DIN0207_L6.3mm_D2.5mm_P7.62mm_Horizontal
R19, R20, R22, R24, R36, R37: 100; R_Axial_DIN0207_L6.3mm_D2.5mm_P7.62mm_Horizontal
R21, R23: 10k; R_Axial_DIN0207_L6.3mm_D2.5mm_P7.62mm_Horizontal
R25: 20; R_Axial_DIN0207_L6.3mm_D2.5mm_P7.62mm_Horizontal
R26, R27: 10K; R_Axial_DIN0207_L6.3mm_D2.5mm_P7.62mm_Horizontal
R28, R29: 1K; R_Axial_DIN0207_L6.3mm_D2.5mm_P7.62mm_Horizontal
R30, R32: 2K4; R_Axial_DIN0207_L6.3mm_D2.5mm_P7.62mm_Horizontal
R34, R35: 1K2; R_Axial_DIN0207_L6.3mm_D2.5mm_P7.62mm_Horizontal
R38, R39: 1K1; R_Axial_DIN0207_L6.3mm_D2.5mm_P7.62mm_Horizontal
TP6, TP7, TP8, TP9: TEST; Measurement_Point_Round-TH_Small

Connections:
-15V: C36.2, C39.2, C42.2, C45.2, D10.2 (A), D11.2 (A), D18.2 (A), D19.2 (A), IC5.8 (V-), IC6.4 (V-), IC7.4 (V-), IC8.4 (V-); also elsewhere on the board
AINA+: C48.1, D14.1 (K), D16.2 (A), R36.1, R38.1; also elsewhere on the board
AINA-: C48.2, D15.1 (K), D17.2 (A), R37.1, R39.1; also elsewhere on the board
GNDA: C32.2, C33.1, C35.2, C36.1, D14.2 (A), D15.2 (A), IC5.7 (Ref), R10.2, R11.1, R17.2, R18.1, R21.1, R23.1; also elsewhere on the board
IN1G1: IC7.2 (-), R28.2; also elsewhere on the board
IN1G2: R25.2; also elsewhere on the board
IN1SWA1: C34.1, R16.1; also elsewhere on the board
IN1SWA2: IC5.2 (+Gain_Sense), IC5.6 (+RG), R16.2; also elsewhere on the board
IN1SWB1: IC6.1, R22.1, TP8.1; also elsewhere on the board
IN1SWB2: C40.2; also elsewhere on the board
IN1SWB3: C30.1; also elsewhere on the board
IN1SWB4: IC6.7, R24.1, TP9.1; also elsewhere on the board
IN1SWB5: C41.2; also elsewhere on the board
IN1SWB6: C31.1; also elsewhere on the board
IN1TRSR: D18.1 (K), D20.2 (A), IC6.5 (+); also elsewhere on the board
IN1TRSRN: R20.1, TP7.1; also elsewhere on the board
IN1TRST: D19.1 (K), D21.2 (A), IC6.3 (+); also elsewhere on the board
IN1TRSTN: R19.1, TP6.1; also elsewhere on the board
unnamed: C30.2, R10.1, R12.2
unnamed: C31.2, R11.2, R13.2
unnamed: C32.1, L3.2, R12.1, R14.2
unnamed: C33.2, L4.2, R13.1, R15.2
unnamed: C34.2, IC5.14 (G=100)
unnamed: C37.1, R17.1, R19.2
unnamed: C37.2, IC5.12 (-Gain_Drive)
unnamed: C38.1, R18.2, R20.2
unnamed: C38.2, IC5.5 (+Gain_Drive)
unnamed: C40.1, IC7.3 (+), R26.2
unnamed: C41.1, IC7.5 (+), R27.2
unnamed: C43.2, IC8.3 (+), R30.1, R34.2
unnamed: C44.2, IC8.5 (+), R32.1, R35.2
unnamed: C46.1, IC8.1, R36.2
unnamed: C46.2, IC8.2 (-), R31.1, R38.2
unnamed: C47.1, IC8.7, R37.2
unnamed: C47.2, IC8.6 (-), R33.1, R39.2
unnamed: D10.1 (K), D12.2 (A), IC5.16 (-Input), L3.1, R14.1
unnamed: D11.1 (K), D13.2 (A), IC5.1 (Input+), L4.1, R15.1
unnamed: IC5.10 (Output), IC5.11 (Sense)
unnamed: IC5.13 (-RG), IC5.15 (-Gain_Sense)
unnamed: IC6.2 (-), R21.2, R22.2
unnamed: IC6.6 (-), R23.2, R24.2
unnamed: IC7.1, R28.1, R30.2, R33.2
unnamed: IC7.6 (-), R25.1, R29.2
unnamed: IC7.7, R29.1, R31.2, R32.2
VCLIP: D16.1 (K), D17.1 (K); also elsewhere on the board
VCOM: C43.1, C44.1, R26.1, R27.1, R34.1, R35.1; also elsewhere on the board

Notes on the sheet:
High impedance guitar buffer
Gain stage
+20/+40 DB
XLR MIC/LINE
Gain potentiometer: Type C (inv log), 2k5, taken between pins 2 and 3 (cursor and CW pin) Gain = 1 + (R28 + R29) / Rpot If 2k5 is not available, scale R25, R28, R29 depending on the actual pot value.
Microphone preamplifier
ADC bias & anti-aliasing filter
GAIN


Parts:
C50, C51, C60, C61: 10u 50V; CP_Radial_D8.0mm_P3.50mm
C52, C53: 1n; C_Rect_L7.2mm_W4.5mm_P5.00mm_FKS2_FKP2_MKS2_MKP2
C54: 470u 25V; CP_Radial_D10.0mm_P5.00mm
C55, C56: 1u tant; CP_Radial_D5.0mm_P2.50mm
C57, C58: 10u 35V; CP_Radial_D5.0mm_P2.00mm
C59, C62, C65: 100n; C_Disc_D3.4mm_W2.1mm_P2.50mm
C63, C64, C66, C67: 1n; C_Disc_D6.0mm_W2.5mm_P5.00mm
C68: 3n3; C_Disc_D6.0mm_W2.5mm_P5.00mm
D30, D31, D32, D33, D38, D39, D40, D41: 1N4448; D_DO-35_SOD27_P7.62mm_Horizontal
D34, D35, D36, D37: 1N5817; D_DO-35_SOD27_P7.62mm_Horizontal
IC9: INA103; DIP-16_W7.62mm_Socket
IC10, IC11, IC12: NE5532; DIP-8_W7.62mm_Socket
L5, L6: 1u2; R_Axial_DIN0309_L9.0mm_D3.2mm_P5.08mm_Vertical
R40, R41, R61, R63: 2K2; R_Axial_DIN0207_L6.3mm_D2.5mm_P7.62mm_Horizontal
R42, R43: 15; R_Axial_DIN0207_L6.3mm_D2.5mm_P7.62mm_Horizontal
R44, R45: 50; R_Axial_DIN0207_L6.3mm_D2.5mm_P7.62mm_Horizontal
R46: 604; R_Axial_DIN0207_L6.3mm_D2.5mm_P7.62mm_Horizontal
R47, R48: 100K; R_Axial_DIN0207_L6.3mm_D2.5mm_P7.62mm_Horizontal
R49, R50, R52, R54, R66, R67: 100; R_Axial_DIN0207_L6.3mm_D2.5mm_P7.62mm_Horizontal
R51, R53: 10k; R_Axial_DIN0207_L6.3mm_D2.5mm_P7.62mm_Horizontal
R55: 20; R_Axial_DIN0207_L6.3mm_D2.5mm_P7.62mm_Horizontal
R56, R57: 10K; R_Axial_DIN0207_L6.3mm_D2.5mm_P7.62mm_Horizontal
R58, R59: 1K; R_Axial_DIN0207_L6.3mm_D2.5mm_P7.62mm_Horizontal
R60, R62: 2K4; R_Axial_DIN0207_L6.3mm_D2.5mm_P7.62mm_Horizontal
R64, R65: 1K2; R_Axial_DIN0207_L6.3mm_D2.5mm_P7.62mm_Horizontal
R68, R69: 1K1; R_Axial_DIN0207_L6.3mm_D2.5mm_P7.62mm_Horizontal
TP10, TP11, TP12, TP13: TEST; Measurement_Point_Round-TH_Small

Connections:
-15V: C56.2, C59.2, C62.2, C65.2, D30.2 (A), D31.2 (A), D38.2 (A), D39.2 (A), IC9.8 (V-), IC10.4 (V-), IC11.4 (V-), IC12.4 (V-); also elsewhere on the board
AINB+: C68.1, D34.1 (K), D36.2 (A), R66.1, R68.1; also elsewhere on the board
AINB-: C68.2, D35.1 (K), D37.2 (A), R67.1, R69.1; also elsewhere on the board
GNDA: C52.2, C53.1, C55.2, C56.1, D34.2 (A), D35.2 (A), IC9.7 (Ref), R40.2, R41.1, R47.2, R48.1, R51.1, R53.1; also elsewhere on the board
IN2G1: IC11.2 (-), R58.2; also elsewhere on the board
IN2G2: R55.2; also elsewhere on the board
IN2SWA1: C54.1, R46.1; also elsewhere on the board
IN2SWA2: IC9.2 (+Gain_Sense), IC9.6 (+RG), R46.2; also elsewhere on the board
IN2SWB1: IC10.1, R52.1, TP12.1; also elsewhere on the board
IN2SWB2: C60.2; also elsewhere on the board
IN2SWB3: C50.1; also elsewhere on the board
IN2SWB4: IC10.7, R54.1, TP13.1; also elsewhere on the board
IN2SWB5: C61.2; also elsewhere on the board
IN2SWB6: C51.1; also elsewhere on the board
IN2TRSR: D38.1 (K), D40.2 (A), IC10.5 (+); also elsewhere on the board
IN2TRSRN: R50.1, TP11.1; also elsewhere on the board
IN2TRST: D39.1 (K), D41.2 (A), IC10.3 (+); also elsewhere on the board
IN2TRSTN: R49.1, TP10.1; also elsewhere on the board
unnamed: C50.2, R40.1, R42.2
unnamed: C51.2, R41.2, R43.2
unnamed: C52.1, L5.2, R42.1, R44.2
unnamed: C53.2, L6.2, R43.1, R45.2
unnamed: C54.2, IC9.14 (G=100)
unnamed: C57.1, R47.1, R49.2
unnamed: C57.2, IC9.12 (-Gain_Drive)
unnamed: C58.1, R48.2, R50.2
unnamed: C58.2, IC9.5 (+Gain_Drive)
unnamed: C60.1, IC11.3 (+), R56.2
unnamed: C61.1, IC11.5 (+), R57.2
unnamed: C63.2, IC12.3 (+), R60.1, R64.2
unnamed: C64.2, IC12.5 (+), R62.1, R65.2
unnamed: C66.1, IC12.1, R66.2
unnamed: C66.2, IC12.2 (-), R61.1, R68.2
unnamed: C67.1, IC12.7, R67.2
unnamed: C67.2, IC12.6 (-), R63.1, R69.2
unnamed: D30.1 (K), D32.2 (A), IC9.16 (-Input), L5.1, R44.1
unnamed: D31.1 (K), D33.2 (A), IC9.1 (Input+), L6.1, R45.1
unnamed: IC9.10 (Output), IC9.11 (Sense)
unnamed: IC9.13 (-RG), IC9.15 (-Gain_Sense)
unnamed: IC10.2 (-), R51.2, R52.2
unnamed: IC10.6 (-), R53.2, R54.2
unnamed: IC11.1, R58.1, R60.2, R63.2
unnamed: IC11.6 (-), R55.1, R59.2
unnamed: IC11.7, R59.1, R61.2, R62.2
VCLIP: D36.1 (K), D37.1 (K); also elsewhere on the board
VCOM: C63.1, C64.1, R56.1, R57.1, R64.1, R65.1; also elsewhere on the board

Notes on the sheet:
ADC bias & anti-aliasing filter
Gain stage
High impedance guitar buffer
Microphone preamplifier
XLR MIC/LINE
GAIN
+20/+40 DB


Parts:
C90, C91, C100, C101: 100u 25V; CP_Radial_D10.0mm_P5.00mm
C92, C102: 2n2; C_Disc_D6.0mm_W2.5mm_P5.00mm
C93, C103: 6n8; C_Disc_D6.0mm_W2.5mm_P5.00mm
C94, C104: 470p; C_Disc_D6.0mm_W2.5mm_P5.00mm
C95, C105: 1n5; C_Disc_D6.0mm_W2.5mm_P5.00mm
C96, C97, C98: 100n; C_Disc_D3.4mm_W2.1mm_P2.50mm
IC15, IC16, IC17: NE5532; DIP-8_W7.62mm_Socket
R80, R100: 1K54; R_Axial_DIN0207_L6.3mm_D2.5mm_P7.62mm_Horizontal
R81, R101: 510; R_Axial_DIN0207_L6.3mm_D2.5mm_P7.62mm_Horizontal
R82, R102: 1K3; R_Axial_DIN0207_L6.3mm_D2.5mm_P7.62mm_Horizontal
R83, R103: 430; R_Axial_DIN0207_L6.3mm_D2.5mm_P7.62mm_Horizontal
R84, R104: 2K; R_Axial_DIN0207_L6.3mm_D2.5mm_P7.62mm_Horizontal
R85, R105: 620; R_Axial_DIN0207_L6.3mm_D2.5mm_P7.62mm_Horizontal
R86, R89, R106, R109: 1K; R_Axial_DIN0207_L6.3mm_D2.5mm_P7.62mm_Horizontal
R87, R107: 220; R_Axial_DIN0207_L6.3mm_D2.5mm_P7.62mm_Horizontal
R88, R108: 820; R_Axial_DIN0207_L6.3mm_D2.5mm_P7.62mm_Horizontal
R90, R91, R92, R110, R111, R112: 100; R_Axial_DIN0207_L6.3mm_D2.5mm_P7.62mm_Horizontal

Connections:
-15V: C96.1, C97.1, C98.1, IC15.4 (V-), IC16.4 (V-), IC17.4 (V-); also elsewhere on the board
AOUTA+: C90.1; also elsewhere on the board
AOUTA-: C91.1; also elsewhere on the board
AOUTB+: C100.1; also elsewhere on the board
AOUTB-: C101.1; also elsewhere on the board
GNDA: C92.2, C93.2, C95.2, C102.2, C103.2, C105.2, IC17.3 (+), IC17.5 (+), R83.2, R86.2, R103.2, R106.2; also elsewhere on the board
unnamed: C90.2, R80.2
unnamed: C91.2, R81.2
unnamed: C92.1, R80.1, R82.2, R84.2
unnamed: C93.1, R81.1, R83.1, R85.2
unnamed: C94.1, IC15.1, IC16.3 (+), R82.1, R88.1, R90.2
unnamed: C94.2, IC15.2 (-), R84.1
unnamed: C95.1, IC15.3 (+), R85.1
unnamed: C100.2, R100.2
unnamed: C101.2, R101.2
unnamed: C102.1, R100.1, R102.2, R104.2
unnamed: C103.1, R101.1, R103.1, R105.2
unnamed: C104.1, IC15.7, IC16.5 (+), R102.1, R108.1, R110.2
unnamed: C104.2, IC15.6 (-), R104.1
unnamed: C105.1, IC15.5 (+), R105.1
unnamed: IC16.2 (-), R86.1, R87.2
unnamed: IC16.6 (-), R106.1, R107.2
unnamed: IC17.1, R89.1, R91.2
unnamed: IC17.2 (-), R88.2, R89.2
unnamed: IC17.6 (-), R108.2, R109.2
unnamed: IC17.7, R109.1, R111.2
OUT1ASYMT: R90.1; also elsewhere on the board
OUT1XLR2: R91.1; also elsewhere on the board
OUT1XLR3: R92.1; also elsewhere on the board
OUT2ASYMT: R110.1; also elsewhere on the board
OUT2XLR2: R111.1; also elsewhere on the board
OUT2XLR3: R112.1; also elsewhere on the board

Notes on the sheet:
Anti-aliasing filter
Symetric amplifier


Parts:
P4: IN1XLR; Pin_Header_Straight_1x03_Pitch2.54mm
P5: IN2XLR; Pin_Header_Straight_1x03_Pitch2.54mm
P6: IN1TRS; Pin_Header_Straight_2x03_Pitch2.54mm
P7: IN2TRS; Pin_Header_Straight_2x03_Pitch2.54mm
P8: IN1SWA; Pin_Header_Straight_1x02_Pitch2.54mm
P9: IN2SWA; Pin_Header_Straight_1x02_Pitch2.54mm
P10: IN1SWB; Pin_Header_Straight_2x03_Pitch2.54mm
P11: IN2SWB; Pin_Header_Straight_2x03_Pitch2.54mm
P14: IN1G; Pin_Header_Straight_1x02_Pitch2.54mm
P15: IN2G; Pin_Header_Straight_1x02_Pitch2.54mm
P16: OUT1ASYM; Pin_Header_Straight_1x02_Pitch2.54mm
P17: OUT2ASYM; Pin_Header_Straight_1x02_Pitch2.54mm
P18: OUT1XLR; Pin_Header_Straight_1x03_Pitch2.54mm
P19: OUT2XLR; Pin_Header_Straight_1x03_Pitch2.54mm

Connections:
GNDA: P4.1, P5.1, P6.1, P6.2, P7.1, P7.2, P16.1, P17.1, P18.1, P19.1; also elsewhere on the board
IN1G1: P14.1; also elsewhere on the board
IN1G2: P14.2; also elsewhere on the board
IN1SWA1: P8.1; also elsewhere on the board
IN1SWA2: P8.2; also elsewhere on the board
IN1SWB1: P10.1; also elsewhere on the board
IN1SWB2: P10.3; also elsewhere on the board
IN1SWB3: P4.2, P10.5; also elsewhere on the board
IN1SWB4: P10.2; also elsewhere on the board
IN1SWB5: P10.4; also elsewhere on the board
IN1SWB6: P4.3, P10.6; also elsewhere on the board
IN1TRSR: P6.5; also elsewhere on the board
IN1TRSRN: P6.6; also elsewhere on the board
IN1TRST: P6.3; also elsewhere on the board
IN1TRSTN: P6.4; also elsewhere on the board
IN2G1: P15.1; also elsewhere on the board
IN2G2: P15.2; also elsewhere on the board
IN2SWA1: P9.1; also elsewhere on the board
IN2SWA2: P9.2; also elsewhere on the board
IN2SWB1: P11.1; also elsewhere on the board
IN2SWB2: P11.3; also elsewhere on the board
IN2SWB3: P5.2, P11.5; also elsewhere on the board
IN2SWB4: P11.2; also elsewhere on the board
IN2SWB5: P11.4; also elsewhere on the board
IN2SWB6: P5.3, P11.6; also elsewhere on the board
IN2TRSR: P7.5; also elsewhere on the board
IN2TRSRN: P7.6; also elsewhere on the board
IN2TRST: P7.3; also elsewhere on the board
IN2TRSTN: P7.4; also elsewhere on the board
OUT1ASYMT: P16.2; also elsewhere on the board
OUT1XLR2: P18.2; also elsewhere on the board
OUT1XLR3: P18.3; also elsewhere on the board
OUT2ASYMT: P17.2; also elsewhere on the board
OUT2XLR2: P19.2; also elsewhere on the board
OUT2XLR3: P19.3; also elsewhere on the board

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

Board: 2 copper layers, 173.0 x 85.0 mm, 261 parts (0 on the bottom side), 149 nets.

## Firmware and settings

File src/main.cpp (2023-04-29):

// Running jack: sudo jackd -P70 -p16 -t2000 -dalsa -p64 -n3 -r44100 -s &
//
// -march=armv8-a doesn't work with std::thread on this GCC version,
// see the Jonathan Wakely's comment (2015-10-05) for bug #42734 on gcc.gnu.org 



#if ! defined (PV_VERSION)
	#error PV_VERSION should be defined.
#endif



// No I/O, audio only. Useful to debug soundcard-related problems.
#undef MAIN_USE_VOID

// Define this to record a video capture of the display in addition to the
// audio streams
#undef MAIN_REC_VIDEO



#include "fstb/def.h"
#if fstb_SYS == fstb_SYS_WIN
	#define WIN32_LEAN_AND_MEAN
	#define NOMINMAX
#endif

#define MAIN_DISP_ST7920  (1)
#define MAIN_DISP_PCD8544 (2)
#define MAIN_DISP_LINUXFB (3)
#if (PV_VERSION == 2)
	#define MAIN_DISP MAIN_DISP_LINUXFB
#else
	#define MAIN_DISP MAIN_DISP_ST7920
#endif

#define MAIN_API_JACK   (1)
#define MAIN_API_ALSA   (2)
#define MAIN_API_ASIO   (3)
#define MAIN_API_MANUAL (4)
#define MAIN_API_PVAB   (5)
#if 0 // For debugging complex audio things
	#define MAIN_API MAIN_API_MANUAL
#elif fstb_SYS == fstb_SYS_LINUX
	#if (PV_VERSION == 2)
		#define MAIN_API MAIN_API_PVAB
	#else
//		#define MAIN_API MAIN_API_JACK
		#define MAIN_API MAIN_API_ALSA
	#endif
#else
	#define MAIN_API MAIN_API_ASIO
#endif

#include "fstb/AllocAlign.h"
#include "fstb/fnc.h"
#include "mfx/adrv/CbInterface.h"
#include "mfx/adrv/DriverInterface.h"
#include "mfx/dsp/mix/Align.h"
#include "mfx/doc/SerRText.h"
#include "mfx/doc/SerWText.h"
#include "mfx/pi/dist1/Param.h"
#include "mfx/pi/dtone1/Param.h"
#include "mfx/pi/dwm/DryWetDesc.h"
#include "mfx/pi/dwm/Param.h"
#include "mfx/pi/freqsh/FreqShiftDesc.h"
#include "mfx/pi/freqsh/Param.h"
#include "mfx/pi/iifix/Param.h"
#include "mfx/pi/param/Tools.h"
#include "mfx/pi/trem1/Param.h"
#include "mfx/pi/trem1/Waveform.h"
#include "mfx/pi/wah1/Param.h"
#include "mfx/piapi/EventTs.h"
#include "mfx/ui/FontDataDefault.h"
#include "mfx/ui/TimeShareThread.h"
#include "mfx/uitk/NText.h"
#include "mfx/uitk/NWindow.h"
#include "mfx/uitk/ParentInterface.h"
#include "mfx/CmdLine.h"
#include "mfx/Model.h"
#include "mfx/ModelObserverDefault.h"
#include "mfx/PageSet.h"
#include "mfx/PluginPool.h"
#include "mfx/ProcessingContext.h"
#include "mfx/Stop.h"
#include "mfx/View.h"
#include "mfx/WaMsgQueue.h"
#include "mfx/WorldAudio.h"

#if fstb_SYS == fstb_SYS_LINUX
	#if (MAIN_API == MAIN_API_JACK)
		#include "mfx/adrv/DJack.h"
	#elif (MAIN_API == MAIN_API_ALSA)
		#include "mfx/adrv/DAlsa.h"
	#elif (MAIN_API == MAIN_API_MANUAL)
		#include "mfx/adrv/DManual.h"
	#elif (MAIN_API == MAIN_API_PVAB)
		#include "mfx/adrv/DPvabI2sDma.h"
	#else
		#error Wrong MAIN_API value
	#endif // MAIN_API
	#include "mfx/hw/FileIOPi3.h"
	#include "mfx/hw/UniqueRscLinux.h"

 #if ! defined (MAIN_USE_VOID)
  #if MAIN_DISP == MAIN_DISP_LINUXFB
	#include "mfx/hw/DisplayLinuxFrameBuf.h"
  #elif MAIN_DISP == MAIN_DISP_PCD8544
	#include "mfx/hw/DisplayPi3Pcd8544.h"
  #else
	#include "mfx/hw/DisplayPi3St7920.h"
  #endif
	#include "mfx/hw/GpioPin.h"
   #include "mfx/hw/Higepio.h"
	#include "mfx/hw/LedPi3.h"
	#include "mfx/hw/UserInputPi3.h"

 #endif // MAIN_USE_VOID

	#include <arpa/inet.h>
	#include <net/if.h>
	#include <netinet/in.h>
	#include <sys/types.h>
	#include <sys/socket.h>
	#include <sys/ioctl.h>
	#include <unistd.h>
	#include <signal.h>

#elif (fstb_SYS == fstb_SYS_WIN)
	#include "mfx/hw/FileIOWindows.h"
	#include "mfx/hw/IoWindows.h"

	#if (MAIN_API == MAIN_API_ASIO)
		#include "mfx/adrv/DAsio.h"
	#elif (MAIN_API == MAIN_API_MANUAL)
		#include "mfx/adrv/DManual.h"
	#else
		#error Wrong MAIN_API value
	#endif

	#include <Windows.h>
	#include <winsock2.h>
	#include <ws2tcpip.h>

	#if defined (_MSC_VER)
		#include	<crtdbg.h>
		#include	<new.h>
		#include	<new>
	#endif	// _MSC_VER

#else // fstb_SYS
	#error Unsupported operating system

#endif // fstb_SYS

#if defined (MAIN_USE_VOID)
	#include "mfx/ui/DisplayVoid.h"
	#include "mfx/ui/LedVoid.h"
	#include "mfx/ui/UserInputVoid.h"
#endif // MAIN_USE_VOID

#if defined (MAIN_REC_VIDEO)
	#include "mfx/VideoRecorder.h"
#endif // MAIN_REC_VIDEO

#include <algorithm>
#include <array>
#include <atomic>
#include <chrono>
#include <memory>
#include <mutex>
#include <thread>

#include <cmath>
#include <cstdint>
#include <cstdio>
#include <cstdlib>
#include <cstring>
#include <ctime>



class Context
:	public mfx::ModelObserverDefault
,	public mfx::adrv::CbInterface
{
public:
	mfx::Stop &    _stop;
	double         _sample_freq;
	int            _max_block_size;
#if (fstb_SYS == fstb_SYS_LINUX)
	mfx::hw::Higepio &
	               _io;
	mfx::ui::TimeShareThread
	               _thread_spi;
#endif // fstb_SYS_LINUX
	const int      _tuner_subspl  = 4;

	// Audio engine
	mfx::ProcessingContext
	               _proc_ctx;
	mfx::ProcessingContext
	               _tune_ctx;
	mfx::ui::UserInputInterface::MsgQueue
	               _queue_input_to_gui;
	mfx::ui::UserInputInterface::MsgQueue
	               _queue_input_to_cmd;
	mfx::ui::UserInputInterface::MsgQueue
	               _queue_input_to_audio;

	// Controller
#if defined (MAIN_USE_VOID)
	mfx::ui::DisplayVoid
	               _display;
	mfx::ui::UserInputVoid
	               _user_input;
	mfx::ui::LedVoid
	               _leds;
#elif (fstb_SYS == fstb_SYS_LINUX)
 #if (MAIN_DISP == MAIN_DISP_LINUXFB)
	mfx::hw::DisplayLinuxFrameBuf
 #elif (MAIN_DISP == MAIN_DISP_PCD8544)
	mfx::hw::DisplayPi3Pcd8544
 #else
	mfx::hw::DisplayPi3St7920
 #endif
	               _display;
	mfx::hw::UserInputPi3
	               _user_input;
	mfx::hw::LedPi3
	               _leds;
#else // fstb_SYS
	mfx::hw::IoWindows
	               _all_io;
	mfx::ui::DisplayInterface &
	               _display;
	mfx::ui::UserInputInterface &
	               _user_input;
	mfx::ui::LedInterface &
	               _leds;
#endif
#if defined (MAIN_REC_VIDEO)
	mfx::VideoRecorder
	               _vid_rec;
#endif // MAIN_REC_VIDEO
#if (fstb_SYS == fstb_SYS_LINUX)
	mfx::hw::FileIOPi3
	               _file_io;
#else // fstb_SYS_LINUX
	mfx::hw::FileIOWindows
	               _file_io;
#endif // fstb_SYS_LINUX

	mfx::Model     _model;

	// View
	mfx::View      _view;
	mfx::PageSet   _page_set;

#if (fstb_SYS == fstb_SYS_LINUX)
	explicit       Context (mfx::adrv::DriverInterface &snd_drv, mfx::Stop &stop, mfx::hw::Higepio &io);
#else // fstb_SYS_LINUX
	explicit       Context (mfx::adrv::DriverInterface &snd_drv, mfx::Stop &stop);
#endif // fstb_SYS_LINUX
	void           set_proc_info (double sample_freq, int max_block_size);
protected:
	// mfx::ModelObserverDefault
	void           do_set_tuner (bool active_flag) final;
	// mfx::adrv:CbInterface
	void           do_process_block (float * const * dst_arr, const float * const * src_arr, int nbr_spl) noexcept final;
	void           do_notify_dropout () noexcept final;
	void           do_request_exit () noexcept final;
private:
	static void    init_empty_bank (mfx::doc::Bank &bank);
#if (fstb_SYS == fstb_SYS_LINUX)
	static void    signal_handler (int sig);
	static Context *
	               _instance_ptr;
#endif
};

#if (fstb_SYS == fstb_SYS_LINUX)

Context * Context::_instance_ptr = nullptr;

void	Context::signal_handler (int sig)
{
	fprintf (stderr, "\nSignal %d received, exiting...\n", sig);
	_instance_ptr->request_exit ();
}

#endif

#if (fstb_SYS == fstb_SYS_LINUX)
Context::Context (mfx::adrv::DriverInterface &snd_drv, mfx::Stop &stop, mfx::hw::Higepio &io)
#else // fstb_SYS_LINUX
Context::Context (mfx::adrv::DriverInterface &snd_drv, mfx::Stop &stop)
#endif // fstb_SYS_LINUX
:	_stop (stop)
,	_sample_freq (0)
,	_max_block_size (0)
#if (fstb_SYS == fstb_SYS_LINUX)
,	_io (io)
,	_thread_spi (std::chrono::milliseconds (10))
#endif // fstb_SYS_LINUX
,	_proc_ctx ()
,	_queue_input_to_gui ()
,	_queue_input_to_cmd ()
,	_queue_input_to_audio ()
#if defined (MAIN_USE_VOID)
,	_display ()
,	_user_input ()
,	_leds ()
#elif (fstb_SYS == fstb_SYS_LINUX)
 #if (MAIN_DISP == MAIN_DISP_LINUXFB)
,	_display ("/dev/fb0")
 #else // MAIN_DISP
,	_display (_thread_spi, _io)
 #endif // MAIN_DISP
,	_user_input (_thread_spi, _io)
,	_leds (_io)
#else // fstb_SYS
,	_all_io (_stop)
,	_display (_all_io)
,	_user_input (_all_io)
,	_leds (_all_io)
#endif // fstb_SYS
#if defined (MAIN_REC_VIDEO)
,	_vid_rec (_display)
#endif // MAIN_REC_VIDEO
,	_file_io (_leds)
,	_model (_queue_input_to_cmd, _queue_input_to_audio, _user_input, _file_io)
,	_view ()
,	_page_set (
		_model, _view,
#if defined (MAIN_REC_VIDEO)
		_vid_rec,
#else // MAIN_REC_VIDEO
		_display,
#endif // MAIN_REC_VIDEO
		_queue_input_to_gui, _user_input, _leds, _stop, snd_drv
	)
{
#if (fstb_SYS == fstb_SYS_LINUX)
	_instance_ptr = this;
	signal (SIGINT,  &signal_handler);
	signal (SIGTERM, &signal_handler);
	signal (SIGQUIT, &signal_handler);
	signal (SIGHUP,  &signal_handler);
#endif

#if ! (fstb_SYS == fstb_SYS_LINUX)
	_all_io.set_model (_model);
#endif

	// First, scans the input queue to check if the ESC button
	// is pressed. If it is the case, we request exiting the program.
	_user_input.set_msg_recipient (
		mfx::ui::UserInputType_SW,
		1 /*** To do: constant ***/,
		&_queue_input_to_gui
	);
	mfx::ui::UserInputInterface::MsgCell * cell_ptr = nullptr;
	bool           scan_flag = true;
	do
	{
		cell_ptr = _queue_input_to_gui.dequeue ();
		if (cell_ptr != nullptr)
		{
			const mfx::ui::UserInputType  type  = cell_ptr->_val.get_type ();
			const int                     index = cell_ptr->_val.get_index ();
			const float                   val   = cell_ptr->_val.get_val ();
			if (type == mfx::ui::UserInputType_SW && index == 1 /*** To do: constant ***/)
			{
fprintf (stderr, "Reading ESC button...\n");
				if (val > 0.5f)
				{
					stop.request (mfx::Stop::Type::QUIT);
					fprintf (stderr, "Exit requested.\n");
				}
				scan_flag = false;
			}
			_user_input.return_cell (*cell_ptr);
		}
	}
	while (cell_ptr != nullptr && scan_flag);

	// Assigns message queues to input devices
	_user_input.assign_queues_to_input_dev (
		_queue_input_to_cmd,
		_queue_input_to_gui,
		_queue_input_to_audio
	);

	// Lists public plug-ins
	_model.create_plugin_lists ();

	_model.set_observer (&_view);
	_view.add_observer (*this);
	_view.set_pi_lists (_model.use_aud_pi_list (), _model.use_sig_pi_list ());

	const int      ret_val = _model.load_from_disk ();
	if (ret_val != 0)
	{

		/*** To do: error message? ***/

		mfx::doc::PedalboardLayout layout;
		layout.set_default_conf ();
		_model.set_pedalboard_layout (layout);

		mfx::doc::Bank bank;
		init_empty_bank (bank);
		for (int b = 0; b < mfx::Cst::_nbr_banks; ++b)
		{
			_model.set_bank (b, bank);
		}
		_model.select_bank (0);
		_model.activate_prog (0);
	}

#if 0
	{
		// Serialization consistency test
		mfx::doc::SerWText ser_w;
		ser_w.clear ();
		_view.use_setup ().ser_write (ser_w);
		ser_w.terminate ();
		const std::string result = ser_w.use_content ();

		mfx::doc::SerRText ser_r;
		ser_r.start (result);
#if __cplusplus >= 201402
		auto sss_uptr (std::make_unique <mfx::doc::Setup> ());
#else // __cplusplus
		std::unique_ptr <mfx::doc::Setup> sss_uptr (new mfx::doc::Setup);
#endif // __cplusplus
		sss_uptr->ser_read (ser_r);
		ser_r.terminate ();

		ser_w.clear ();
		_view.use_setup ().ser_write (ser_w);
		ser_w.terminate ();
		const std::string result2 = ser_w.use_content ();

		assert (result == result2);
	}
#endif

//	_model.set_chn_mode (mfx::ChnMode_1M_1S);

	mfx::uitk::PageSwitcher &  page_switcher = _page_set.use_page_switcher ();
	page_switcher.switch_to (mfx::uitk::pg::PageType_PROG_CUR, nullptr);

/**********************************************************************************************************************************************************************************************************************************/
// Debugging code
//	_model.select_bank (2);
//	_model.activate_prog (3);
/**********************************************************************************************************************************************************************************************************************************/
}



void	Context::set_proc_info (double sample_freq, int max_block_size)
{
	_sample_freq    = sample_freq;
	_max_block_size = max_block_size;
	_model.set_process_info (_sample_freq, _max_block_size);
}



void	Context::do_set_tuner (bool active_flag)
{
	if (active_flag)
	{
		mfx::uitk::PageSwitcher &  page_switcher =
			_page_set.use_page_switcher ();
		const mfx::uitk::Page & page_mgr = _page_set.use_page_mgr ();
		page_switcher.call_page (
			mfx::uitk::pg::PageType_TUNER,
			nullptr,
			page_mgr.get_cursor_node ()
		);
	}
}



void	Context::do_process_block (float * const * dst_arr, const float * const * src_arr, int nbr_spl) noexcept
{
	_model.process_block (dst_arr, src_arr, nbr_spl);
}



void	Context::do_notify_dropout () noexcept
{
	mfx::MeterResultSet &   meters = _model.use_meters ();
	meters._dsp_overload_flag.exchange (true);
}



void	Context::do_request_exit () noexcept
{
	_stop.request (mfx::Stop::Type::QUIT);
}



void	Context::init_empty_bank (mfx::doc::Bank &bank)
{
	for (auto &prog : bank._prog_arr)
	{
		prog._name = mfx::Cst::_empty_prog_name;
	}
}



static int MAIN_main_loop (Context &ctx, mfx::adrv::DriverInterface &snd_drv)
{
	fprintf (stderr, "Entering main loop...\n");

	int            ret_val         =  0;
	int            loop_count      =  0;
	int            overload_count  =  0;
	const int      overload_limit  = 10;
	int            recovery_count  =  0;
	const int      recovery_limit  = 10;
	const int      recovery_limit2 = 50; // For the restart
	int            restart_count   =  0;
	int            restart_limit   = 32;

	while (ret_val == 0 && ! ctx._stop.is_exit_requested ())
	{
		int            wait_ms = 100; // Milliseconds

#if 0 // When doing manual time sharing
		while (! ctx._thread_spi.process_single_task ())
		{
			continue;
		}
#endif

		ctx._model.process_messages ();

		const bool     tuner_flag = ctx._view.is_tuner_active ();

		mfx::MeterResultSet &   meters = ctx._model.use_meters ();

		// Watchdog for audio overloads
		const bool     overload_flag = meters._dsp_overload_flag.exchange (false);
		if (overload_flag)
		{
			wait_ms        = 10;
			recovery_count = 0;
			++ overload_count;
			if (   overload_count > overload_limit
			    && restart_count  < restart_limit)
			{
				snd_drv.restart ();
				overload_count = 0;
				++ restart_count;
			}
		}
		else
		{
			++ recovery_count;
			if (recovery_count > recovery_limit)
			{
				if (recovery_count > recovery_limit2)
				{
					restart_count = 0;
				}
				overload_count = 0;
			}
		}

		// LEDs
		if (! tuner_flag)
		{
			constexpr int  nbr_led = 3;
			std::array <float, nbr_led>   lum_arr = { 0, 0, 0 };
			if (meters.check_signal_clipping ())
			{
				lum_arr [0] = 1;
			}
			if (overload_flag)
			{
				if (restart_count >= restart_limit)
				{
					lum_arr [0] = sqrtf (0.375f);
					lum_arr [1] = sqrtf (0.125f);
					lum_arr [2] = sqrtf (0.5f  );
				}
				else
				{
					lum_arr [2] = 1;
				}
			}
			for (int led_index = 0; led_index < nbr_led; ++led_index)
			{
				float           val = lum_arr [led_index];
				val = val * val;  // Gamma 2.0
				ctx._leds.set_led (led_index, val);
			}
		}

// Pollutes the logs when run in init.d
#if defined (MAIN_USE_VOID) || ! (fstb_SYS == fstb_SYS_LINUX)
		const float  usage_max  = meters._dsp_use._peak;
		const float  usage_avg  = meters._dsp_use._rms;
		const float  period_now = ctx._model.get_audio_period_ratio ();
		char         cpu_0 [127+1] = "Time usage: ------ % / ------ %";
		if (usage_max >= 0 && usage_avg >= 0)
		{
			fstb::snprintf4all (
				cpu_0, sizeof (cpu_0),
				"Time usage: %6.2f %% / %6.2f %%, Speed: %6.2f %%",
				usage_avg * 100, usage_max * 100, 100 / period_now
			);
		}

		fprintf (stderr, "%s\r", cpu_0);
		fflush (stderr);
#endif

		ctx._page_set.use_page_mgr ().process_messages ();

		bool        wait_flag = true;

#if 1

		if (wait_flag)
		{
			static const std::chrono::milliseconds wait_duration (wait_ms);
			std::this_thread::sleep_for (wait_duration);
		}

	#if (MAIN_API == MAIN_API_MANUAL)

		{
			mfx::adrv::DManual & snd_drv_man =
				dynamic_cast <mfx::adrv::DManual &> (snd_drv);
			size_t         sample_index = snd_drv_man.get_sample_index ();
			const int      nbr_spl      = ctx._max_block_size;
			const int      nbr_blocks   = fstb::ceil_int (ctx._sample_freq * wait_ms / (1000.0 * nbr_spl));

#if 0
			const int      sec          = int (sample_index / size_t (ctx._sample_freq));
			const size_t   sec_spl     = sec * size_t (ctx._sample_freq);
			if (sec_spl <= sample_index && sample_index < sec_spl + nbr_spl * nbr_blocks)
			{
				printf ("%d ", sec);
				fflush (stdout);
			}
#endif

			float *        in_ptr_arr [mfx::adrv::DriverInterface::_nbr_chn];
			const float *  out_ptr_arr [mfx::adrv::DriverInterface::_nbr_chn];
			snd_drv_man.get_buffers (in_ptr_arr, out_ptr_arr);
			const double   freq = 82.40689; // E
			const double   mul  = 2 * fstb::PI * freq / ctx._sample_freq;
			const float    amp  = 0.1f;
			for (int b = 0; b < nbr_blocks; ++b)
			{
				for (int i = 0; i < nbr_spl; ++i)
				{
					const float     val = float (sin ((sample_index + i) * mul)) * amp; 
					for (int chn = 0; chn < mfx::adrv::DriverInterface::_nbr_chn; ++ chn)
					{
						in_ptr_arr [chn] [i] = val;
					}
				}

				snd_drv_man.process_block ();

				sample_index += nbr_spl;
			}
		}

	#endif

#else

/********************************************* TEMP *********************************/

		const int      nbr_spl = 64;
		float          buf [4] [nbr_spl];
	#if 0
		memset (&buf [0] [0], 0, sizeof (buf [0]));
		memset (&buf [1] [0], 0, sizeof (buf [1]));
	#else
		static double  angle_pos  = 0;
		const double   angle_step = 2 * fstb::PI * 200 / ctx._sample_freq;
		for (int i = 0; i < nbr_spl; ++i)
		{
			const float       val = float (sin (angle_pos));
			buf [0] [i] = val;
			buf [1] [i] = val;
			angle_pos += angle_step;
		}
		angle_pos = fmod (angle_pos, 2 * fstb::PI);
	#endif
		const float *  src_arr [2] = { buf [0], buf [1] };
		float *        dst_arr [2] = { buf [2], buf [3] };

		ctx._model.process_block (dst_arr, src_arr, nbr_spl);

/********************************************* TEMP *********************************/

#endif


/********************************************* TEMP *********************************/
#if 0
		if (loop_count == 10)
		{
			ctx._user_input.send_message (0, mfx::ui::UserInputType_POT, 0, 0.5f);
//			ctx._user_input.send_message (0, mfx::ui::UserInputType_SW, 2, 1);
		}
#endif
/********************************************* TEMP *********************************/

		++ loop_count;
		fstb::unused (loop_count);
	}

	fprintf (stderr, "Exiting main loop.\n");

	return ret_val;
}



#if defined (_MSC_VER)

static int __cdecl	MAIN_new_handler_cb (size_t dummy)
{
	fstb::unused (dummy);

	throw std::bad_alloc ();
//	return (0);
}
void MAIN_prog_init ()
{
	::_set_new_handler (::MAIN_new_handler_cb);
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
int main (int argc, char *argv [], char *envp [])
{
#else
int WINAPI WinMain (::HINSTANCE instance, ::HINSTANCE prev_instance, ::LPSTR cmdline_0, int cmd_show)
{
	fstb::unused (instance, prev_instance, cmdline_0, cmd_show);
#endif

#if defined (_MSC_VER)
	MAIN_prog_init ();
#endif

	mfx::Stop      stop;

	int            ret_val = 0;

	try
	{
#if fstb_SYS == fstb_SYS_LINUX
		stop.use_cmd_line ().set (argc, argv, envp);

		mfx::hw::UniqueRscLinux unique_lock ("pedalevite-unique");
#endif

#if fstb_SYS == fstb_SYS_LINUX && ! defined (MAIN_USE_VOID)

	mfx::hw::Higepio  io;

	io.set_pin_mode (mfx::hw::GpioPin::_nav_cancel, mfx::hw::bcm2837gpio::PinFnc_IN);
	if (io.read_pin (mfx::hw::GpioPin::_nav_cancel) == 0)
	{
		fprintf (stderr, "Emergency exit\n");
		throw 0;
	}

	io.set_pin_mode (mfx::hw::GpioPin::_reset, mfx::hw::bcm2837gpio::PinFnc_OUT);

	io.write_pin (mfx::hw::GpioPin::_reset, 0);
	std::this_thread::sleep_for (std::chrono::milliseconds (100));
	io.write_pin (mfx::hw::GpioPin::_reset, 1);
	std::this_thread::sleep_for (std::chrono::milliseconds (100));

#endif

	mfx::dsp::mix::Align::setup ();

	int            chn_idx_in  = 0;
	int            chn_idx_out = 0;

#if (MAIN_API == MAIN_API_JACK)
	mfx::adrv::DJack  snd_drv;
#elif (MAIN_API == MAIN_API_ALSA)
	mfx::adrv::DAlsa  snd_drv;
#elif (MAIN_API == MAIN_API_ASIO)
	mfx::adrv::DAsio  snd_drv;
	chn_idx_in = 2;
#elif (MAIN_API == MAIN_API_MANUAL)
	mfx::adrv::DManual   snd_drv;
#elif (MAIN_API == MAIN_API_PVAB)
	mfx::adrv::DPvabI2sDma  snd_drv (io);
#else
	#error
#endif


#if __cplusplus >= 201402
	auto           ctx_uptr (std::make_unique <Context> (
#else // __cplusplus
	std::unique_ptr <Context>  ctx_uptr (new Context (
#endif // __cplusplus
		snd_drv, stop
#if fstb_SYS == fstb_SYS_LINUX
		, io
#endif // fstb_SYS_LINUX
	));
	Context &      ctx = *ctx_uptr;

	if (! ctx._stop.is_exit_requested ())
	{
		double         sample_freq;
		int            max_block_size;
		ret_val = snd_drv.init (
			sample_freq,
			max_block_size,
			ctx,
			nullptr,
			chn_idx_in,
			chn_idx_out
		);

		if (ret_val == 0)
		{
			ctx.set_proc_info (sample_freq, max_block_size);
			ret_val = snd_drv.start ();
		}

		if (ret_val == 0)
		{
			ret_val = MAIN_main_loop (ctx, snd_drv);
		}

		snd_drv.stop ();
	}

	// Flushes all message queues
	while (   ctx._model.process_messages ()
	       || ctx._page_set.use_page_mgr ().process_messages ())
	{
		continue;
	}

	ctx_uptr.reset ();

	} // try
#if (fstb_SYS == fstb_SYS_LINUX)
	catch (mfx::hw::UniqueRscLinux::Error &e)
	{
		fprintf (stderr, "Pedale Vite is already running!\n");
	}
#endif
	catch (int e)
	{
		fprintf (stderr, "Exception: int = %d\n", e);
		ret_val = e;
	}
	catch (...)
	{
		fprintf (stderr, "Exception caught.\n");
	}

	fprintf (stderr, "Exiting with code %d.\n", ret_val);

	stop.process_request ();

#if defined (_MSC_VER)
	MAIN_prog_end ();
#endif

	return ret_val;
}

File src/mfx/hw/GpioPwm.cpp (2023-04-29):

/*****************************************************************************

        GpioPwm.cpp
        Author: Laurent de Soras, 2016

--- Legal stuff ---

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
*Tab=3***********************************************************************/



/*\\\ INCLUDE FILES \\\\\\\\\\\\\\\\\\\\\\\\\\\\\\\\\\\\\\\\\\\\\\\\\\\\\\\\*/

#include "mfx/hw/bcm2837clk.h"
#include "mfx/hw/GpioPwm.h"

#include <bcm_host.h>
#include <mailbox.h>

#include <sys/mman.h>
#include <fcntl.h>
#include <unistd.h>

#include <algorithm>
#include <memory>
#include <stdexcept>

#include <cassert>
#include <cstdint>
#include <cstring>
#include <ctime>



namespace mfx
{
namespace hw
{




/*\\\ PUBLIC \\\\\\\\\\\\\\\\\\\\\\\\\\\\\\\\\\\\\\\\\\\\\\\\\\\\\\\\\\\\\\\*/



GpioPwm::GpioPwm (int granularity, Higepio &io)
:	_granularity (granularity)
,	_io (io)
,	_periph_base_addr (::bcm_host_get_peripheral_address ())
,	_reg_pwm (
		_periph_base_addr + bcm2837pwm::_pwm_ofs,
		bcm2837pwm::_pwm_len, "/dev/mem", O_RDWR | O_SYNC
	)
,	_reg_clk (
		_periph_base_addr + bcm2837clk::_clk_ofs,
		bcm2837clk::_clk_len, "/dev/mem", O_RDWR | O_SYNC
	)
,	_reg_gpio (
		_periph_base_addr + bcm2837gpio::_gpio_ofs,
		bcm2837gpio::_gpio_len, "/dev/mem", O_RDWR | O_SYNC
	)
{
	// RPi 4 (BCM 2711) has different PLLD clock values (750 MHz instead of 500 MHz)
	const bool     bcm2711_flag = (_periph_base_addr == bcm2837::_phys_base_2711);
	const int      plld_freq    =
		(bcm2711_flag) ? bcm2837::_plld_freq_2711 : bcm2837::_plld_freq_2835;

	// PWM divisor to obtain 10 MHz
	const int      target_freq  = 10'000'000; // 10 MHz
	const int      clk_div      = plld_freq / target_freq;

	_reg_pwm.at (bcm2837pwm::_ctl   ) = 0;
	_io.sleep (10);
	_reg_clk.at (bcm2837clk::_pwmctl) = // Source = PLLD (500 or 750 MHz)
		bcm2837clk::_passwd | bcm2837clk::_src_plld;
	_io.sleep (100);
	_reg_clk.at (bcm2837clk::_pwmdiv) =
		bcm2837clk::_passwd | (clk_div << bcm2837clk::_divi);
	_io.sleep (100);
	_reg_clk.at (bcm2837clk::_pwmctl) =
		bcm2837clk::_passwd | bcm2837clk::_src_plld | bcm2837clk::_enab; // Source = PLLD and enable
	_io.sleep (100);
	_reg_pwm.at (bcm2837pwm::_rng1  ) = _granularity * 10;
	_io.sleep (10);
	_reg_pwm.at (bcm2837pwm::_dmac  ) =
		bcm2837pwm::_enab | (15 << bcm2837pwm::_panic) | (15 << bcm2837pwm::_dreq);
	_io.sleep (10);
	_reg_pwm.at (bcm2837pwm::_ctl   ) = bcm2837pwm::_clrf1;
	_io.sleep (10);
	_reg_pwm.at (bcm2837pwm::_ctl   ) = bcm2837pwm::_usef1 | bcm2837pwm::_pwen1;
	_io.sleep (10);
}



// Setup a channel with a specific subcycle time in microseconds.
// After that pulse-widths can be added at any time.
int	GpioPwm::init_chn (int chn, int subcycle_time)
{
	assert (chn >= 0);
	assert (chn < _nbr_dma_chn);
	assert (subcycle_time >= _min_subcycle_time);

	int            ret_val = Err_OK;

	assert (_chn_arr [chn].get () == nullptr);

	try
	{
		_chn_arr [chn] = ChannelSPtr (new Channel (
			_io, chn, _periph_base_addr, subcycle_time, _granularity
		));
	}
	catch (MBox::Error &err)
	{
		ret_val = Err_MAILBOX;
	}
	catch (const Err &err)
	{
		ret_val = int (err);
	}
	catch (MmapPtr::Error &err)
	{
		ret_val = Err_MMAP;
	}
	catch (...)
	{
		ret_val = Err_GENERIC;
	}

	return ret_val;
}



void	GpioPwm::clear (int chn)
{
	assert (chn >= 0);
	assert (chn < _nbr_dma_chn);
	assert (_chn_arr [chn].get () != nullptr);

	Channel &      channel = *(_chn_arr [chn]);
	channel.clear ();
}



void	GpioPwm::clear (int chn, int gpio)
{
	assert (chn >= 0);
	assert (chn < _nbr_dma_chn);
	assert (_chn_arr [chn].get () != nullptr);

	Channel &      channel = *(_chn_arr [chn]);
	channel.clear (gpio);
}



void	GpioPwm::add_pulse (int chn, int gpio, int start, int width)
{
	assert (chn >= 0);
	assert (chn < _nbr_dma_chn);
	assert (_chn_arr [chn].get () != nullptr);

	const int      start_spl = (start + (_granularity >> 1)) / _granularity;
	const int      width_spl = (width + (_granularity >> 1)) / _granularity;

	Channel &      channel   = *(_chn_arr [chn]);
	channel.add_pulse (gpio, start_spl, width_spl);
}



void	GpioPwm::set_pulse (int chn, int gpio, int start, int width)
{
	assert (chn >= 0);
	assert (chn < _nbr_dma_chn);
	assert (_chn_arr [chn].get () != nullptr);

	const int      start_spl = (start + (_granularity >> 1)) / _granularity;
	const int      width_spl = (width + (_granularity >> 1)) / _granularity;

	Channel &      channel   = *(_chn_arr [chn]);
	channel.set_pulse (gpio, start_spl, width_spl);
}



/*\\\ PROTECTED \\\\\\\\\\\\\\\\\\\\\\\\\\\\\\\\\\\\\\\\\\\\\\\\\\\\\\\\\\\\*/



/*\\\ PRIVATE \\\\\\\\\\\\\\\\\\\\\\\\\\\\\\\\\\\\\\\\\\\\\\\\\\\\\\\\\\\\\\*/
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

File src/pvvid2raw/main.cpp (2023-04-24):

/*

Decodes .pvvid video capture files into raw 8-bit 4:4:4 Y'Cb'Cr' data, 30 fps.
Warning: the raw frames are dumped on the standard output.

Usage:

pvvid2raw "filename.pvvid" | x264 --stitchable --demuxer raw --input-depth 8 --input-range pc --input-res 800x480 --input-csp i444 --range pc --output-csp i444 --sar 1:1 --fps 30 --qp 0 --preset veryfast --keyint 10 --transfer bt709 --colorprim bt709 --colormatrix bt709 --stylish --output "filename.mkv" -

*/

#include "fstb/def.h"
#include "fstb/fnc.h"
#include "mfx/CompressSimple.h"
#include "mfx/VidRecFmt.h"

#if fstb_SYS == fstb_SYS_WIN
	#include <io.h>
	#include <fcntl.h>
#endif

#include <vector>

#include <cassert>
#include <cstdint>
#include <cstdio>



class VidDecomp
{
public:
	typedef mfx::VidRecFmt::TimestampUnit::period TsPer;
	explicit       VidDecomp (FILE *f_ptr, FILE *o_ptr, int fps_num, int fps_den);
	int            convert_pvvid ();
	int            read_comp_frame (bool &cont_flag);
	int            output_previous_frames (int frame_stop);
	int            conv_ts_to_framenum (uint64_t timestamp) const;
	static uint64_t
	               gcd (uint64_t a, uint64_t b);
private:
	FILE *         _f_ptr;
	FILE *         _o_ptr;
	int            _fps_num;
	int            _fps_den;
	int            _pic_w;
	int            _pic_h;
	std::vector <uint8_t>
	               _frame_buf;
	std::vector <uint8_t>
	               _raw_buf;
	std::vector <uint8_t>
	               _cmp_buf;
	uint64_t       _conv_num;
	uint64_t       _conv_den;
	uint64_t       _ts_cur;
	int            _frame_cur;
};



VidDecomp::VidDecomp (FILE *f_ptr, FILE *o_ptr, int fps_num, int fps_den)
:	_f_ptr (f_ptr)
,	_o_ptr (o_ptr)
,	_fps_num (fps_num)
,	_fps_den (fps_den)
,	_pic_w (0)
,	_pic_h (0)
,	_frame_buf ()
,	_raw_buf ()
,	_cmp_buf ()
,	_conv_num (TsPer::num * _fps_num)
,	_conv_den (TsPer::den * _fps_den)
,	_ts_cur (0)
,	_frame_cur (0)
{
	assert (f_ptr != nullptr);
	assert (o_ptr != nullptr);
	assert (fps_num > 0);
	assert (fps_den > 0);

	const uint64_t g = gcd (_conv_num, _conv_den);
	_conv_num /= g;
	_conv_den /= g;
}



int	VidDecomp::convert_pvvid ()
{
	int            ret_val = 0;

	mfx::VidRecFmt::HeaderFile header;
	if (ret_val == 0 && fread (&header, sizeof (header), 1, _f_ptr) != 1)
	{
		fprintf (stderr, "Error. Cannot read file header.\n");
		ret_val = -1;
	}

	if (ret_val == 0 && header._version > mfx::VidRecFmt::_fmt_version)
	{
		fprintf (
			stderr,
			"Error. Wrong file version %d.\n",
			int (header._version)
		);
		ret_val = -1;
	}
	if (ret_val == 0 && header._pix_code != mfx::VidRecFmt::PixCode_GREY8)
	{
		fprintf (
			stderr,
			"Error. Unsupported pixel format %d.\n",
			int (header._pix_code)
		);
		ret_val = -1;
	}

	if (ret_val == 0)
	{
		_pic_w = header._width;
		_pic_h = header._height;

		_frame_buf.assign (_pic_w * _pic_h, 0);
		_raw_buf.resize (_frame_buf.size ());
		_cmp_buf.resize (_frame_buf.size () * 5 / 4);

		_ts_cur    = 0;
		_frame_cur = 0;
	}

	// Reads frames
	bool           cont_flag = true;
	while (ret_val == 0 && cont_flag)
	{
		ret_val = read_comp_frame (cont_flag);
	}

	return ret_val;
}



int	VidDecomp::read_comp_frame (bool &cont_flag)
{
	int            ret_val = 0;

	mfx::VidRecFmt::HeaderFrame   header;

	if (ret_val == 0 && fread (&header, sizeof (header), 1, _f_ptr) != 1)
	{
		fprintf (
			stderr,
			"Error. Cannot read frame header. Last frame: %d, %llu us.\n",
			_frame_cur,
			static_cast <unsigned long long> (_ts_cur)
		);
		ret_val   = -1;
	}

	int            frame_new = _frame_cur;
	uint64_t       ts_new    = _ts_cur;
	if (ret_val == 0)
	{
#if 0
		fprintf (
			stderr,
			"Decoding frame at %llu us.\n",
			static_cast <unsigned long long> (header._timestamp)
		);
#endif

		assert (header._x < _pic_w);
		assert (header._y < _pic_h);
		assert (header._x + header._w <= _pic_w);
		assert (header._y + header._h <= _pic_h);

		ts_new    = header._timestamp;
		frame_new = conv_ts_to_framenum (ts_new);

		assert (ts_new >= _ts_cur);
		if (header._w == 0 || header._h == 0)
		{
			cont_flag = false;
			++ frame_new; // Makes sure we output the very last frame
		}

		// If the compressed frame is located on an output frame after
		// the current one, generates the required output frames.
		ret_val = output_previous_frames (frame_new);
	}

	// Decodes the current compressed frame
	static const size_t cmp_hd_len = mfx::CompressSimple::_frame_header_len;
	if (ret_val == 0 && cont_flag)
	{
		if (fread (_cmp_buf.data (), cmp_hd_len, 1, _f_ptr) != 1)
		{
			fprintf (
				stderr,
				"Error. Cannot read compressed data header."
				" Last frame: %d, %llu us.\n",
				_frame_cur,
				static_cast <unsigned long long> (_ts_cur)
			);
		}
	}

	size_t         comp_frame_size = 0;
	if (ret_val == 0 && cont_flag)
	{
		comp_frame_size = mfx::CompressSimple::read_compressed_frame_size (
			_cmp_buf.data ()
		);
		assert (cmp_hd_len + comp_frame_size <= _cmp_buf.size ());
		if (fread (
			   _cmp_buf.data () + cmp_hd_len, 1, comp_frame_size, _f_ptr
		   ) != comp_frame_size
		)
		{
			fprintf (
				stderr,
				"Error. Cannot read compressed data."
				" Last frame: %d, %llu us.\n",
				_frame_cur,
				static_cast <unsigned long long> (_ts_cur)
			);
		}
	}

	if (ret_val == 0 && cont_flag)
	{
#if ! defined (NDEBUG)
		const size_t   raw_size =
			mfx::CompressSimple::compute_raw_frame_size (_cmp_buf.data ());
		assert (raw_size <= _raw_buf.size ());
#endif
		mfx::CompressSimple::decompress_frame (
			_raw_buf.data (), _cmp_buf.data ()
		);
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

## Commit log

2017-02-11 Noise bleach: switched off band splitting/merging (quite CPU hungry) when no band processing occurs
2017-02-11 Split Noise bleach into two different effects
    The notch filters went to the new Noise chlorine, and Noise bleach keeps the band filters
    [main.cpp]
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2017-04-22 Fixed a function prototype for the bilinear transform and added the vectorised version for the one-pole approximation
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2017-05-16 Added dsp::dly::DelayLineReaderPitch, which can read a delay line like DelayLineReader while performing a basic pitch shifting.
2017-07-03 Freeverb: fixed an issue with the comb filter
2017-07-04 Fixed a compilation issue on ARM architectures
2017-07-13 UI: fixed cursor issues when switching to a new page
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2017-07-16 Various fixes for the State Variable Filter
2017-07-17 Fixed an assert caused by a missing case
2017-07-25 SiemensGirlz: implemented pitch shifting in the feedback loop of the delay line
    May be slightly slower in the general case than the previous implementation (DelayLineBbd). Source code kept in case of performance issues.
    [main.cpp]
2017-12-08 Freeverb: fixed an assert occuring when switching to the freeze mode
2017-12-27 Current program page: displays the name of the main effect (not the dry/wet mixer) when a parameter is changed.
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2018-03-28 Added Onset Detector (still experimental, not working very well) and Synth0, a very basic synth to test the pitch and onset detectors
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2018-05-14 LfoModule: fixed an alignment issue causing crashes on ARM
2018-05-28 Fixed step settings for the rotary encoders
2018-06-10 LFO: changed the smoothing filter order from 1 to 3, so the beginning of a step is smoothed too, not just the end.
2018-08-27 Added Square root, Belt and Bad Mood modes to the Double distortion
2018-09-24 Alsa audio interface: reduced the log output in case of large number of dropouts.
2018-09-24 The Current Program page now displays the controllers used by the program.
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2018-10-20 Added 3 feedback-proof “light” modes to the Double Distortion.
    These modes can be used with signals highly subject to feedback (taken with a mic on a stage), so the open loop gain is never increased by the distortion (they work with a gain of 0 dB). They are not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
2019-03-05 Added Pitch Shifter effect. Same algorithm as the SiemensGirlz, but simpler user interface
2019-04-04 Added the Amanda Ghassaei pitch detector; used it in the pitch detection plug-in for testing
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2019-05-29 Group delays of some IIR filters are now taken into account for the calculation of the plug-in latency
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2019-06-01 PWM Distortion 2: added a peak detection method, and a new parameter to choose which detection to use.
2019-06-01 PWM Distortion 1: fixed an issue with stereo output
2019-06-01 PWM Distortion 2: added a gate and a functionality to control the output volume from the input volume
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2019-06-01 PWM Distortion 2: gate ratio changed from 4 to 8 for faster effect
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2019-06-02 Added dsp::ana::FreqPeak, the most reliable real-time pitch detector we tried so far.
    The Pitch Detector plug-in has been modified to use it.
2019-06-02 Prevented floods with internally generated events (audio to main thread)
    The problem was occurring in the controller link page, when the display couldn't follow the event rate from fast modulators
2019-06-05 Added two selection filters (median and other ranks) to mfx::dsp::fir. Updated code tests.
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2019-07-01 4x up/downsampler: depending on the filter order, the implementation types (FPU/SSE/NEON) are now optimized for best performance
2019-07-01 dsp::fir::RankSelL: when setting the filter length, content is not trashed if the length is not actually changed.
2019-07-01 Added Onset Detector 2. It is currently disabled because not so good,
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2019-07-03 PWM distortion 2: fixed a few bugs and switched to block processing
2019-07-03 PWM distortion 2: optimisations are effective, we can discard the old slow code
2019-07-09 Started to work on a driver for the Pedale Vite Audio Board
2019-07-17 Pedale Vite audio driver: fixed a buffer position reset bug
    [main.cpp]
2019-07-20 Changed the DMA channel allocation for the LED PWM (from 4 to 5)
    Indeed Something related to DMA channels has changed on recent Raspbian and channel 4 wasn't working anymore.
2019-07-22 Less verbosity in the logs when the audio thread stalls
2019-07-22 Date editing: workaround for the freeze issue
    [main.cpp]
2019-07-23 ALSA driver: when restarting the driver, inserting a short delay between init() and start() seems to provide a bit more stability
2019-08-12 The PVAB driver works slightly better now.
    Full setup was required for Control Port Mode. The driver doesn't freeze anymore but the signal is a mess.
    [main.cpp]
2019-08-12 Fixed a few things, but still now working as expected.
    There is a high level of dropout, which means that the CPU/SoC is probably not fast enough to reliably sync to 5.64 MHz edges. More investigation is required, and DMA will be probably needed.
    [main.cpp]
2019-08-15 Emulation on Windows: switches are now drawn on the GUI and can be pressed with the mouse
2019-08-17 Renamed mfx::Msg to mfx::WaMsg to avoid any confusion with other Msg classes
    [main.cpp]
2019-08-26 Added a class to handle a lock-free queue for messages requiring resource allocation and deallocation.
    Consumed messages are returned to the sending thread to free their resources.
2019-08-27 Lock-free queue with resource management: now the messages own their return queue, so it's easier to check if some of them are missing during object destruction.
    [main.cpp]
2019-08-27 Fixed minor prototype/body mismatch
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2019-08-29 Fixed the reference to a comment in the GCC bug tracker, about compatibility between std::thread and architecture targets
    [main.cpp]
2019-08-30 Added dsp::fir::Remez, an implementation of the Parks-McClellan algorithm to build a FIR filter
2019-09-01 Fixed compiler errors and warnings
    [main.cpp]
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2019-09-01 Added sample-based oscillators (normal and sync) + tests
    [main.cpp]
2019-09-02 Replaced typeid() with custom function fstb::lang::type_name(), it should print something more readable.
2019-09-02 TestOscWavetable: now displays the size of the wavetable. Also tests the sample per sample processing
2019-09-03 Added dual oscillator dsp::osc::OscWavetableSub + tests
    [main.cpp]
2019-09-05 Added dsp::osc::OscWavetableSyncHard + tests, and fixed small other details related to oscillators
    [main.cpp]
2019-09-09 Added a display interface implementing Linux framebuffer, for using HDMI displays with Pédale Vite
2019-09-11 Fixed a few things with the Pédale Vite audio board driver
2019-09-11 Renamed DPvab driver to DPvabDirect. This attempt failed. Another DPvab driver should be developed, on different principles.
    [main.cpp]
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2019-09-17 Pedale Vite audio board I2S driver: fixed various issues, it now works
    [main.cpp]
2019-09-24 hw::DisplayLinuxFrameBuf: switched to pure graphic mode to avoid the blinking console cursor
2019-10-03 Added zoom feature to hw::LinuxFrameBuf, so the current GUI don't look too ridiculously small on a higher definition display
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2019-11-03 Hardware is now in version 2
    Building instructions and user manuals have been updated accordingly.
    Everything related to v1 hardware has been moved to doc/v1
    [audio-board-B.Cu.gbl, audio-board-B.Mask.gbs, audio-board-B.SilkS.gbo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]
2019-11-05 Replaced test::FileOp with mfx::FileOpWav and added functions to write data by blocks (instead of a full file at once)
    [main.cpp]
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2019-11-06 Disk recording page: now shows the current recording duration, and the time limit cannot be modified during recording.
2019-11-07 Backup is now done from the loaded configuration instead of copying the current configuration file (which could even be missing)
2019-11-09 Building instructions: added a mounting point for USB drives and notes about the Pi 4 thermal behaviour
2019-11-09 Pédale Vite audio board driver (I2S): added missing dropout detection
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2019-11-18 Fixed a few bugs and compilation errors
    [GpioPwm.cpp, GpioPwm.h]
2019-11-18 hw::GpioPwm : init_chn() now returns a more meaningful error code
    [GpioPwm.cpp, GpioPwm.h]
2019-11-21 ToolsSimd: fixed rounding on ARM, got rid of some static constants, added exp2_approx2()
2019-12-17 Switched the C++ standard to 2017 if available, although it is not mandatory
    C++17 is required to check if some atomic operations are really lock-free.
2019-12-17 Forgot to AC_SUBST some variables, added X86 and ARM conditions for the makefile (not used yet)
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2019-12-18 Fixed a few compiler warnings again by testing with various compilers and architectures
    [main.cpp]
2019-12-18 Build system: default is now Pedale Vite v2.
    Added a test to check the Raspberry Pi hardware.
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2019-12-18 Fixed a compilation error on Linux systems
    [main.cpp]
2019-12-18 MSVC++ project files: warning level set to 4 and a couple of warnings are disabled permanently.
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2019-12-23 Filter Squeezer: fixed a buffer issue with buffer sizes > 64
2019-12-24 Router: fixed bugs with the insertion of compensation delays
2019-12-24 Set a limit to the number of messages processed per block in the audio thread
2019-12-24 hw::GpioPwm: changed the mmap settings for a DMA channel, muting an assert while accessing the DMA registers.
    For some reason, we cannot mmap just the desired address range for a single DMA channel, we have to start from the beginning of the DMA registers. Even if only the first DMA channel is mmapped, it wo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
2020-01-01 Added program switching mode for global transition smoothing.
    Replaces and improves the smooth transition feature.
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2020-01-02 Double distortion: fixed click issues
    The transition between gains is linear, but the compensation gain
    (if any) should be reciprocal. To simplify computations, it is
    currently linearly ramping too. This cause problem when switching
    immediately to a very low gain, because the gain and compensation gain
    product suddenly goes very high in the middle of the course, causing a
    distinct click.
    This issues occurs mostly when switching presets, so handling
    a special case after buffer clearing was enough to fix it.
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2020-01-16 Fixed routing issue while reading an old config
    The “analysis” plug-ins (no audio output) were not routed correctly when
    reading a config file using routing as a chain. Previously their input
    was implicitely routed to the next plug-in. Here, these connections are
    now explicitely modified to reflect the previous behaviour
    .
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2020-01-20 Fixed alignment crashes on ARM architectures
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2020-02-22 Fixed a crash when saving a program containing empty slots
2020-03-02 Added a global lock to prevent Pedale Vite from running twice
    [main.cpp]
2020-03-02 Fixed a few things with the unique lock
    [main.cpp]
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2020-03-20 Replaced the standard diode clipper with a generic clipper
    [main.cpp]
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2020-04-03 UI: replaced “deg” with the degree sign “°”
2020-04-06 Replaced some volatile Type with std::atomic <Type>
    Some stuffs are remaining in conc
    [main.cpp]
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2020-05-14 MNA: fixed a scaling issue with the diode models
    Resulting change is actually very tiny
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2020-05-25 MNA: avoids tweaking voltages on nodes known to be constant
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2020-06-14 Updated schematics for KiCAD 5
    [audio-board.kicad_pcb, audio-board.sch, but-nav.sch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]
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2020-07-11 Fixed compiler error and warnings
    [main.cpp]
2020-07-14 Fixed compilation error on ARM
2020-07-27 Fixed compatibility with C++11
    [main.cpp]
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2020-09-29 Added and fixed more compiler warnings
    [main.cpp]
2020-10-05 Fixed a corruption bug with clang + misc details
    In the clang atomic library, weak and strong CAS implementations
    are different (at least for 32-bit ARM). The lock-free queue algorithm
    relies on the exact success or failure of this primitive, so when the
    weak CAS fails spuriously, it leads to data corruption. Replacing
    weak CAS with strong CAS fixes the problem.
    Also useless volatile keywords were removed, and ptrdiff_t replaced
    with intptr_t when relevant.
2020-10-14 Added lal, a minimalist linear algebra library
    This is intended to replace Eigen, which generates tons of compilation
    warnings and is a bit too slow when using small resizable matrices or
    vectors. The library is still in development and interfaces may change.
    [main.cpp]
2020-10-14 Replaced Eigen with lal in the MNA circuit simulator
2020-10-14 Case error in Makefile.am + #if/#endif mismatch
    [main.cpp]
2020-11-03 Fixed the ultraspherical windowing function
    [main.cpp]
2020-11-12 Fixed compiler warning: compound assignment to volatile
    [GpioAccess.cpp]
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2020-11-16 Attempt to fix a failure when restarting the program
    On Linux systems, the programs creates a temporary file in
    /run/lock to ensure there is at most one running instance.
    However restarting the program from the user interface did
    not delete the lock file, and the new instance couldn’t start.
    Now the restart occurs after the temporary file is deleted.
    [main.cpp]
2020-11-16 uitk::page: fixed a crash when modifying the timer list
    When sending timer messages, the timer list may be modified from
    a message, invalidating the current iterator and leading to a crash.
    Fixed by adding a flag signaling a modification.
2020-11-16 Backup to USB: more accurate error messages
    [main.cpp]
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2021-02-24 SvfMixerLow: fixed prototype error
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2021-03-17 Added Martin Vicanek’s oscillator, for comparison
    [main.cpp]
2021-03-20 Fixed message printing
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2021-03-26 Building doc: config and troubleshooting update
    Latest Raspberry Pi OS changed some default settings that required
    a fix.
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2021-03-26 Fixed most of the I2S/DMA code
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2021-04-04 dsp::iir::SplitMultiband: misc refinements
    - True block processing disabled and replaced with sample processing
    - Filter states cleared after the number of band are changed
    - Added get_nbr_bands()
    - Forgot to add the test files to the MSVC project
    - Comments
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2021-04-29 Pitch shifter: fixed buffer overflow with long windows
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2021-05-05 FrameOverlapSyn: fixed index error
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2021-05-10 Spectral Freeze: added Dry mode parameter
    The Cut mode needs the whole system to be reworked because the
    phase relationship between the dry signal and the frozen signal is not
    preserved.
2021-05-11 Bug fix
    When trying to delete the empty slot at the end of the list
    for control signal plug-ins.
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2021-05-25 Added granulation and convolution with velvet noise
    [main.cpp]
2021-05-27 Double distortion: fixed case in parameter names
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2021-08-02 Noise Bleach: filterbank improvement
    – Slightly faster and better splitting capacity.
    – Factored some code
2021-10-31 conc: fixed issues with some architectures
    – Should work better on MacOS/ARM.
    – For various raisons, __atomic_compare_exchange_n() for 128-bit may not
    be lock-free on x86, even with -mcx16 compiler option. We’d better stay
    with the “legacy” builtin __sync_val_compare_and_swap() which does
    exactly what we want.
    – Armel architectures haven't any primitives guaranteed to be lock-free
    contrary to armhf, but it should compile and work even if the
    performances are expected to be inferior.
2021-10-31 Fixed various compilation issues
    [GpioPwm.cpp]
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2021-11-17 fstb::Approx: refactoring
    – More constexpr functions
    – Removed useless fstb:: namespace prefix
    – Replaced (a + 1) * x with a * x + x to remove the constant
    – Other misc stuff
2021-11-21 Approx: added SIMD for exp2 and log2
    However most implementations are currently disabled because some rework
    is needed in ToolsSimd.
2021-11-21 fstb::ToolsSimd: refactoring
    The Vect*32 types are now separate classes in the V*32 form.
    This allows adding constructors and conversion functions, which is an
    important step to get unique template function definitions instead of
    separated scalar/vector ones.
    Moreover, the operator implementation is cleaner.
    Not tested yet on ARM, fixes will probably follow.
    [main.cpp]
2021-11-21 fstb::ToolsSimd: fixed refactoring on ARM
2021-11-24 Fixed compilation on ARM
2021-11-29 Fixed regression on ARM for exp2()
    Caused by commit 15ef75c94df11d83a399de0e7d927885805ab8ee
2021-11-30 fstb::Vf32: fixed fms on ARM and added fnma
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2021-12-12 Lipidipi: new improvements
    – Now uses BP-filtered groups of 4 voices
    – Fixed some bugs related to the LFOs
    – Adjustable mix
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2021-12-14 Back to 16-byte alignment for ARM NEON
    Seems that 8 bytes leads to bus errors.
    But now GCC complains when alignas() argument is > 8.
    It needs more thinking about a correct way to mute the warnings.
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2021-12-21 Updated hiir and related files
    – Added HalfBand classes for full-rate half-band filtering
    – Added processing on user-provided data types
    – Performance improvement for Downsampler2xSse and Upsampler2xSse
    – Fixed the phase delay estimation
    – Better test code for phase delay
    [main.cpp]
2021-12-21 hiir: more fixes for ARM NEON
    [main.cpp]
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2022-02-26 Fixed unnecessary alignment requirement
    This caused a bus error on ARM.
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2022-05-11 Updated board files to KiCAD 6
    [audio-board.kicad_pcb, audio-board.kicad_sch, audio-board.sch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]
2022-05-29 OscSinCosStableSimd: fixed several issues
    - Initialisation and frequency changes were not handled correctly,
    leaving wrong values for scalar positions > 0.
    - correct_fast() was also buggy.
    - Moved the test into its own class.
    [main.cpp]
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2022-09-22 Reworked note <-> param conversions + tests
    [main.cpp]
2023-04-27 Changed GPIO pin numbering from physical to BCM
    This should ease the future replacement of the wiringPi library.
    [GpioPin.h, GpioPwm.cpp, GpioPwm.h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]
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2023-04-29 configure.ac: fixed default for wiringPi
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2023-04-30 Replaced wiringPi with a custom implementation
    Pigpio was OK for the required operations but had negative side effects
    on the audio I2S code, probably messing with the DMA or something.
    Optional support for wiringPi is kept as a backup solution, time to make
    sure everything works reliably.
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

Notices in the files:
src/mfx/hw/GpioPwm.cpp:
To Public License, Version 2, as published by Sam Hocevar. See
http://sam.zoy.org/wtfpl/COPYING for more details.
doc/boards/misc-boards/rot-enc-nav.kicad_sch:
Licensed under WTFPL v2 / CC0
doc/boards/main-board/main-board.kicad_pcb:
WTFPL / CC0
